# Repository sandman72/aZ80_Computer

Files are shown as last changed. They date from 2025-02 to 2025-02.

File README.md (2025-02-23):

# aZ80_Computer

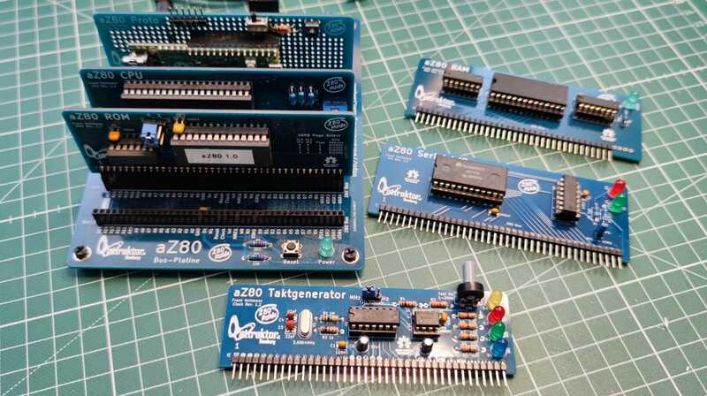
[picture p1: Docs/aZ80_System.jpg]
Das aZ80 System


#### Was ist der aZ80 Retro Computer?

Die Idee war: Wir bauen einen kleinen bezahlbaren Retro Computer für Workshops im Attraktor e.V.

 - Mit Steckkarten, damit man ihn erweitern kann. 
 - Beim Aufbau jeder Karte gibt es einen Einblick, was diese im Detail macht und wie sie funktioniert
 - Eine Einführung zur Computertechnik der 70er Jahre und die Gedankengänge und Evolutionen, die es zu der Zeit gab.
 - Wir programmieren auf dem aZ80 mit MS-BASIC und Assembler, z.B. kleine Spiele und Programme.

Unter Docs findet sich eine erste Präsentation über das Projekt. Eine ausführliche Anleitung folgt nach den ersten Workshops.

#### Hardware

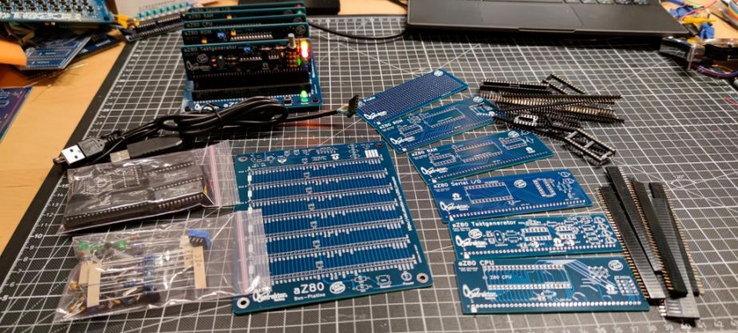
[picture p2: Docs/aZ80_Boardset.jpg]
Die aZ80 Boards


Die Entscheidung was für ein System ich "neu" entwickeln wollte, fiel auf einen Bauvorschlag von <a href="http://searle.wales/">Grant Searle</a>, 
der auch bei einigen anderen Retro-Computern (z.B. RC2014) zum Einsatz kam. Damit gibt es eine gewisse 
Kompatibilität zum RC2014 System und den Steckkarten, aber der aZ80 sollte als Open-Hardware und -Software verfügbar 
sein und nicht hinter einer Paywall liegen, teure Kits oder Zusatz Hardware benötigen, z.B. wie der RC2014.

#### Software

Für den aZ80 wurden eine alte Version von MS Basic (Nascom Basic 4.7) und der Efex Monitor (Efex V4 1.0) mit einem eigenen BIOS kombiniert.
Das BIOS checkt, ob die wichtigsten Karten des Systems funktionieren und initialisiert diese. Danach erscheint über die serielle Schnittstelle
die Auswahlmöglichkeit zwischen dem Basic und dem Monitor Programm. Diese sind so angepasst, dass sie mit dem 
Online Z80 Compiler <a href="https://www.asm80.com/">ASM80</a> bearbeitet werden können.

Nascom Basic Verweis: <a href="https://gitlab.com/feilipu/NASCOM_BASIC"> https://gitlab.com/feilipu/NASCOM_BASIC </a>

Efex V4 1.0 Verweis: <a href="https://mkpeker.wixsite.com/efex"> https://mkpeker.wixsite.com/efex </a>

#### VDP

Als Highlight hat der aZ80 ein Video Display Prozessor mit an Board, der die Verbindung in die jetzige Zeit herstellt. Mit dieser Karte kann man den aZ80
an einen DVI/HDMI Monitor anschließen und per USB auch Tastatur, Maus, Joystick und/oder Speicher anschließen. Das kombiniert mit einem schicken Gehäuse
mit eingebautem Display gibt dann einen kleinen feinen Standalone Z80 Computer.

Der VDP wird über die serielle Schnittstelle angesprochen und kann Text 40x25 Zeichen oder auch Grafiken (320x240 Pixel mit 256 Farben), Sprites oder 
einen Mouse Cursor anzeigen. Zusätzlich gibt es einen Debug Bildschirm, mit dem man den aktuellen Status sich anzeigen lassen kann (Win+ESC Taste).

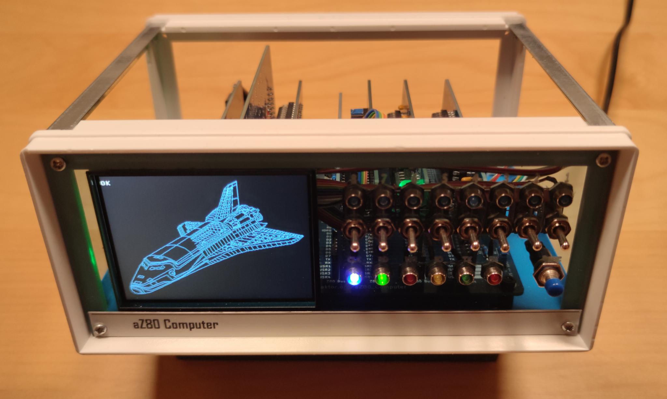
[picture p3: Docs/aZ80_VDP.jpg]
Die aZ80 VDP


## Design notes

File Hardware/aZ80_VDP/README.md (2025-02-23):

# aZ80 VDP Platine

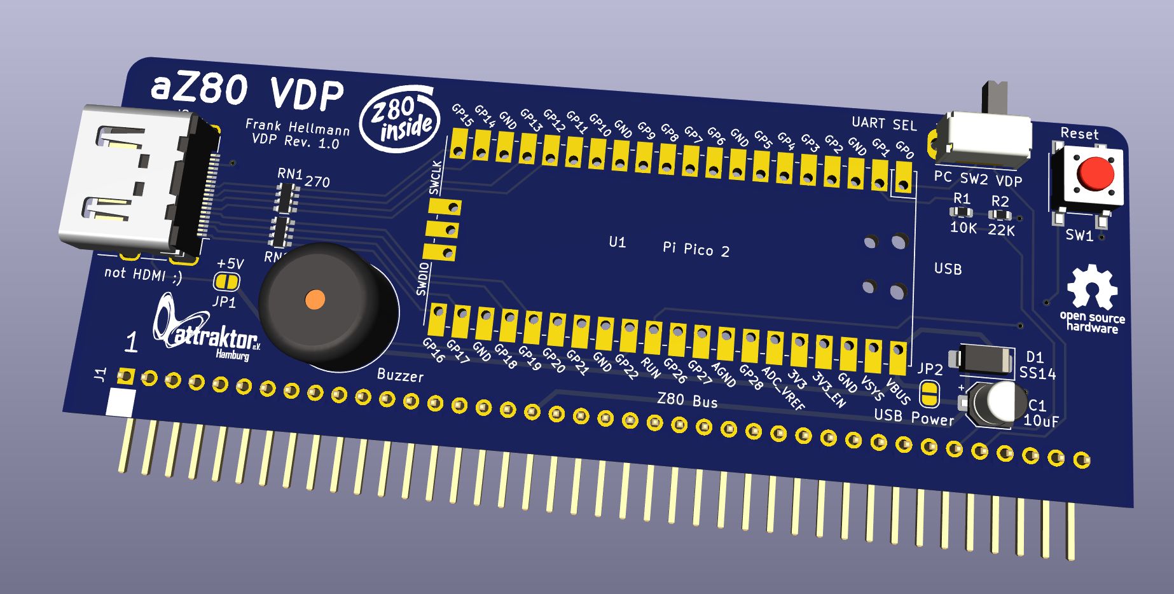
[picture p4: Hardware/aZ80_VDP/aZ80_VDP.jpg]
Die aZ80 VDP Platine


Die Video-Display-Processor VDP Platine ist eine Grafik- und I/O-Karte mit eingebautem VT100+ Terminal Emulator. Über die serielle Schnittstelle kann sie Daten vom aZ80 System
entgegennehmen und anzeigen, kann aber auch über den USB Port Eingaben über eine USB-Tastatur an das aZ80 System weitergeben. 
Auch andere USB-Geräte, wie Maus, Joystick oder Speicherstick können abgefragt werden, wobei die Unterstützung noch work in progress ist.

Der VDP untertützt die normale Anzeige von Text, der über die seriellen Schnittstelle eingeht. Darüber hinaus werden auch ANSI Kontrollzeichen 
unterstützt, welche eine erweiterte Kontrolle der Textattribute, wie Farbe, Blinken, Position usw. erlaubt, und darüber hinaus auch eine Grafikausgaben
und die Kontrolle von Sprites, Maus-Cursor und den Buzzer erlaubt. Weiteres auf der <a href="./ANSI.md">ANSI Seite</a>.

Über die USB-Tastatur kann mit der Tastenkombination WIN+ESC ein Debug-Fenster eingeblendet werden, das den akutellen Zustand des VDP anzeigt.

Der Reset Taster SW1 bietet es an den VDP zurückzusetzen und vereinfacht auch das installieren einer neuen Firmware an einem PC.

Der Umschalter SW2 bietet zwei Betriebsmodi an:
| SW1 | Modus |
|:---:|:---|
| PC  | PC-Betrieb - Die serielle Schnittstelle auf der Bus-Platine hat Vorrang |
| VDP | Standalone-Betrieb - Die USB Schnittstelle am VDP hat Vorrang |

#### Technische Daten

Der VDP bietet eine Grafikauflösung von 320x240 Pixel mit 256 Farben. Die Ausgabe erfolgt hochskaliert als 640x480 Pixel Modus mit 60Hz über eine (not) HDMI Schnittstelle.

 - Arduino Software auf einem Raspberry PI Pico 2 - RP2350
 - 320x240 Pixel Auflösung
 - 40x30 Zeichen Textmodus mit 16 bzw. 256 Farben
 - 256 Farben Palette mit 16bit Farbtiefe, 8 Farben in automatischer Farbrotation
 - 64 32x32 Pixel Sprites mit 256 Farben und Maskenkanal
 - einen Mauscursor
 - einfache Text- und Grafik-Kommandos
 - Double-Buffered Text-, Grafik und Sprite-Aufbau für flickerfreie Anzeige mit 60Hz

#### Update der Firmware

Zur Installation einer neuen Firmware auf den Pico 2 wird dieser mit einem Micro USB Kabel an einen PC angeschloßen.
Dann drückt man erst die Reset Taste SW1, nun den BOOT Taster, hält diesen fest und lässt die Reset Taste SW1 los.
Auf dem PC sollte nun ein weiteres Laufwerk RPI angezeigt werden. Auf dieses kopiert man die aktualisierte UF2 Datei.

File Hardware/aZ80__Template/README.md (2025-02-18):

# aZ80 Platinen Template

Dieses Template kann genutzt werden um mit KiCAD V8.0 oder neuer eigene Platinen im Formfaktor des aZ80 Retro Systems zu designen.

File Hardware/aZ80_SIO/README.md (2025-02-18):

# aZ80 Serielle Platine

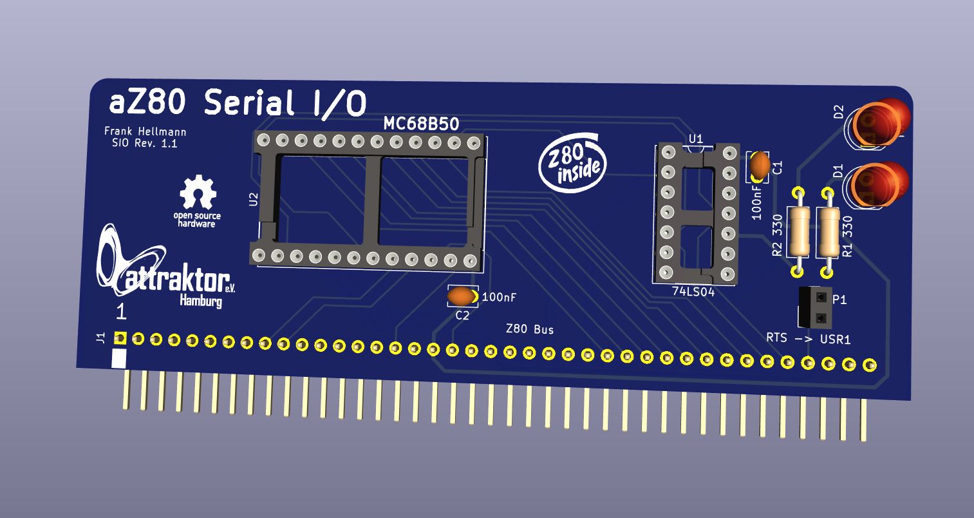
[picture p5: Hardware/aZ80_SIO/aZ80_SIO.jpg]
Die aZ80 Serielle Platine


Die serielle Platine stellt über eine serielle Schnittstelle die Verbindung zur Aussenwelt her. 
Diese Schnittstelle wird über die Busplatine an deren Anschluß J1 zur Verfügung gestellt. 
Dort kann man dann ein seriell zu USB Wandlerkabel anschließen und mit einem Computer als Terminal Ersatz verbinden. 
Hierbei ist auf die Pinbelegung zu achten, da diese nicht wirklich genormt ist.

Über den Jumper JP1 kann ein RTS/CTS-Handshaking aktiviert werden, was wichtig ist, wenn man viele Daten oder lange 
Listings vom Computer übertragen will. Das Handshaking stellt sicher, dass nur dann Daten übertragen werden, wenn 
das aZ80 System diese auch verarbeiten kann und noch Platz im Empfangsbuffer ist.

Die Einstellungen in einem seriellen Terminal Emulator auf einem PC sind dann folgende:

    57600 Baud  8-N-1  RTS/CTS Handshake

#### LEDs

Die LEDs zeigen den Datentransfer über die Sende- (TX) und Empfangs- (RX) Leitung an.

#### Jumper JP1

Der Jumper JP1 erlaubt das Aktivieren des RTS/CTS-Handshaking über die USR1 Leitung zur Busplatine. 
Dort muß auch der Jumper JP1 gesteckt werden um das Signal an den Anschluß J1 weiterzuleiten.

#### Baudrate

Die Baudrate wird direkt aus dem Systemtakt der Clock Platine abgeleitet und beträgt im Normallfall 57600 Baud, wenn ein 3.6864MHz Quartz verwendet wird.

Wenn die Clock Platine auf niedrige Frequenz (4-20Hz) steht, dann funktioniert die Serielle Karte nicht ordnungsgemäß.

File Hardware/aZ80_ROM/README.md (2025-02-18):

# aZ80 ROM Platine

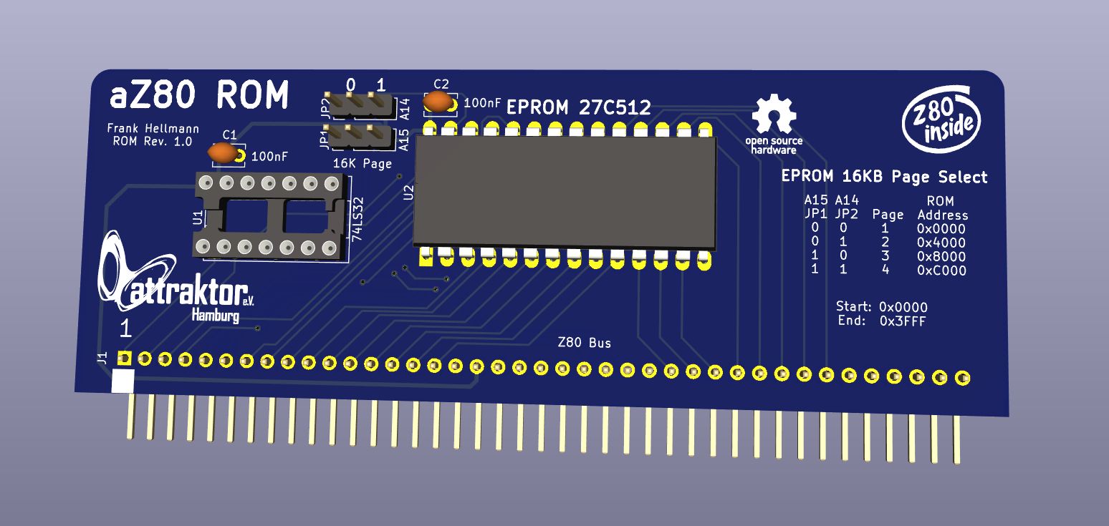
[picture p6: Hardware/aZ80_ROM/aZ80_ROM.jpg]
Die aZ80 ROM Platine


Die ROM Platine stellt dem aZ80 Retro System den nichtflüchtigen Speicher zur Verfügung. 

Der 32KB große Speicherbaustein (EEPROM) ist in 4 8KB große Teile (Bänke/Pages) aufgeteilt.

Das ROM wird im ersten Speicherbereich eingeblendet ($0000 - $3FFF) und enthält auch die Interrupt Vectoren.

#### Bank Auswahl

Über die Jumper JP1 und JP2 kann der 8KB Teil des ROMs eingestellt werden, der dem aZ80 zur Verfügung gestellt werden soll.

| JP2 | JP1 | Bank |
|:---:|:---:|:-----|
| 0 | 0 | 1 - BIOS mit BASIC und MONITOR |
| 0 | 1 | 2 - Diagnostic ROM |
| 1 | 0 | (aktuell Kopie von Bank 1) |
| 1 | 1 | (aktuell Kopie von Bank 2) |

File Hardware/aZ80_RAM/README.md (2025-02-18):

# aZ80 RAM Platine

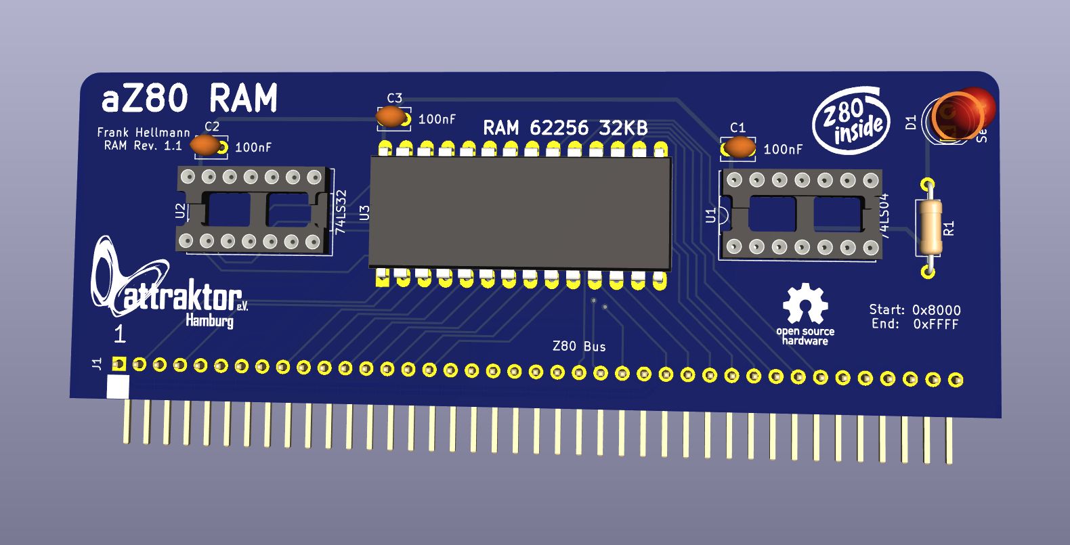
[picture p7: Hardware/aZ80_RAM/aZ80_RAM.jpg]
Die aZ80 RAM Platine


Die RAM Platine stellt den 32KB großen flüchtigen Arbeitsspeicher dem aZ80 Retro System zur Verfügung.

Das RAM wird im oberen Teil des Addressraums eingeblendet ($8000-$FFFF).

Die LED zeigt einen Zugriff auf den Arbeitsspeicher an.

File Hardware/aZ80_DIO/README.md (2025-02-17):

# aZ80 Digital I/O Platine

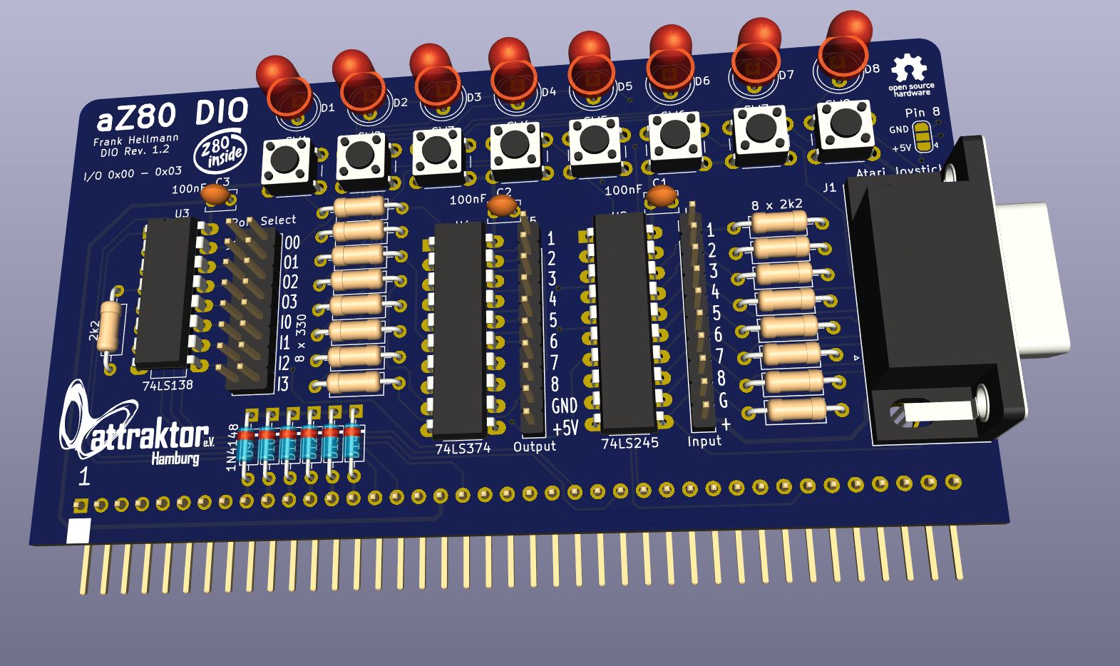
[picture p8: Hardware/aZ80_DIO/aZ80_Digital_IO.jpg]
Die aZ80 Digital I/O Platine


Die DIO (Digital I/O) Platine stellt über Taster, Joystick Anschluss und LEDs eine Verbindung zur Aussenwelt her.

#### Port Auswahl

Über den Jumperblock JP1 kann die Adresse (Port) eingestellt werden, auf den die DIO Platine reagieren soll. 
Normalerweise ist dort O0 und I0 gesteckt, was bedeutet, dass die DIO Platine auf Addresse 0 beim Lesen und Schreiben reagiert.
Damit können auch mehrere Karten in einem aZ80 System genutzt werden, wenn alle Karten unterschiedliche Addressen bekommen.

#### LEDs

Die LEDs können über die eingestellte Addresse mit einem I/O Write eingeschaltet werden. 

```
Basic:   OUT 0, 170             schaltet jede zweite LED an Port 0 an.

ASM:     LD      A,%10101010
         OUT     IOPORT,A       schaltet jede zweite LED an Port 0 an.
```

#### Taster & Joystick

Die Taster und der Joystick können über die eingestellte Addresse mit einem I/O Read ausgelesen werden.

```
Basic:   A$=INP(0)     liest den Status der Taster in A$ ein

ASM:     IN A,(0)      liest den Status der Taster in Register A
```

#### Basic Beispiel um LED mit Button einzuschalten

```
10 OUT 0,INP(0)
20 GOTO 10
```

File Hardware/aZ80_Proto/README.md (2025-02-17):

# aZ80 Prototypen Platine

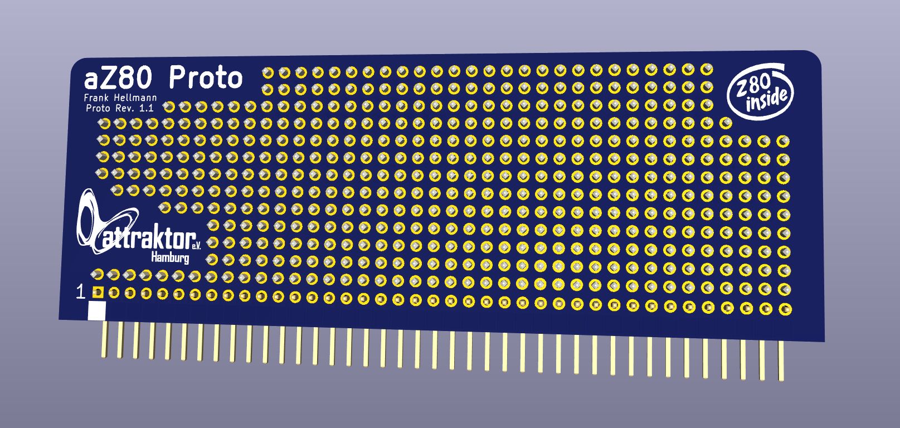
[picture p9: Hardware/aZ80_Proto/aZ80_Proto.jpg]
Die aZ80 Prototypen Platine


Die Proto Platine kann für eigene Experimente oder Schaltungen benutzt werden und ist mit einem Lochraster ausgestattet.

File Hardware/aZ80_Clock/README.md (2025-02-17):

# aZ80 Taktgenerator Platine

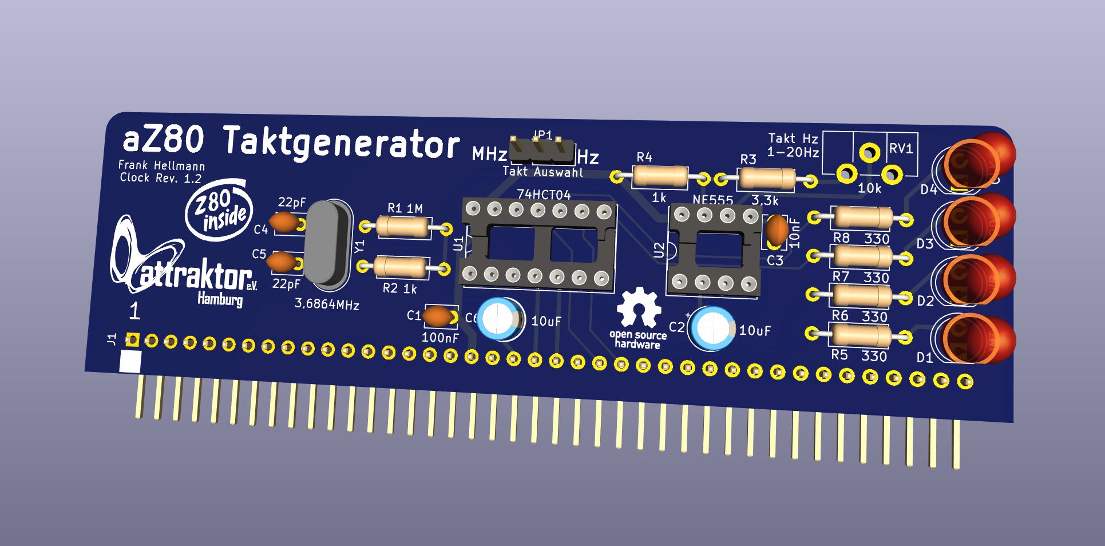
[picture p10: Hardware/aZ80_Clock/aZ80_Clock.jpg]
Die aZ80 Takt Platine


Die Taktgenerator Platine gibt den Takt des aZ80 Retro Computers vor und synchronisiert alle Karten.

Es gibt zwei Modis die mit dem Jumper JP1 umgestellt werden können:

 - 1 - Volle Geschwindigkeit mit 3.6864 MHz
 - 2 - Langsame Geschwindigkeit mit 4-20Hz

Im Normalfall läuft das aZ80 Retro System mit vollem 3.6864Mhz Takt, welcher auch die serielle Baudrate von 57.600 Baud vorgibt.

Bei der langsamen Geschwindigkeit kann man dem System besser "auf den Zahn fühlen", z.B. mit einem Logic Analyser oder der Digital I/O Karte, hat aber keine serielle Verbindung mehr.
Das Poti RV1 erlaubt das Einstellen der Geschwindigkeit im Rahmen von ca. 4 bis 20 Herz.

Die Status LEDs zeigen an, was auf dem aZ80 Bus so los ist:

 - RD - Es wird auf dem Bus etwas gelesen
 - WR - Es wird auf dem Bus etwas geschrieben
 - INT - Es ist ein Interrupt ausgelöst worden
 - CLK - Hier wird der aktuelle Takt als Blinken angezeigt

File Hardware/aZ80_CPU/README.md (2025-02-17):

# aZ80 CPU Platine

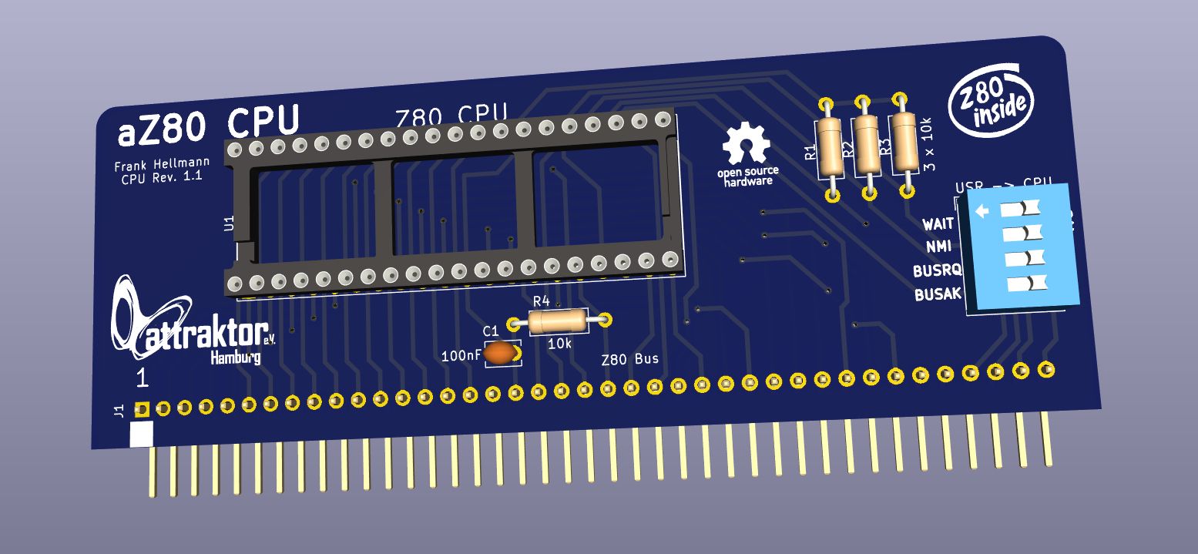
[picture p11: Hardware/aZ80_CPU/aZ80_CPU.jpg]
Die aZ80 CPU Platine


Die CPU Platine ist das Hirn des aZ80 Retro Computers und verarbeitet die Daten.

#### Switch USR -> CPU

Der Switch ist normalerweise in allen Positionen auf Off gestellt und erlaubt in Zukunft weiteren Karten die Steuerung der CPU.

 - 1 - WAIT 
 - 2 - NMI
 - 3 - BUSRQ
 - 4 - BUSAK

Das WAIT Signal hält die CPU an und wird aktuell nur beim Betrieb der SN76489 Soundkarte genutzt. Diese ist so langsam, dass sie die CPU anhalten muss, bis der nächste Befehl gesendet werden darf.

Das NMI (Non-Maskable-Interrupt) Signal ist aktuell ungenutzt.

Das BUSRQ (Bus-Request) Signal ist aktuell ungenutzt.

Das BUSAK (Bus-Acknowledge) Signal ist aktuell ungenutzt.

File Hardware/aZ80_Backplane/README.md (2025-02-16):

# aZ80 Bus-Platine

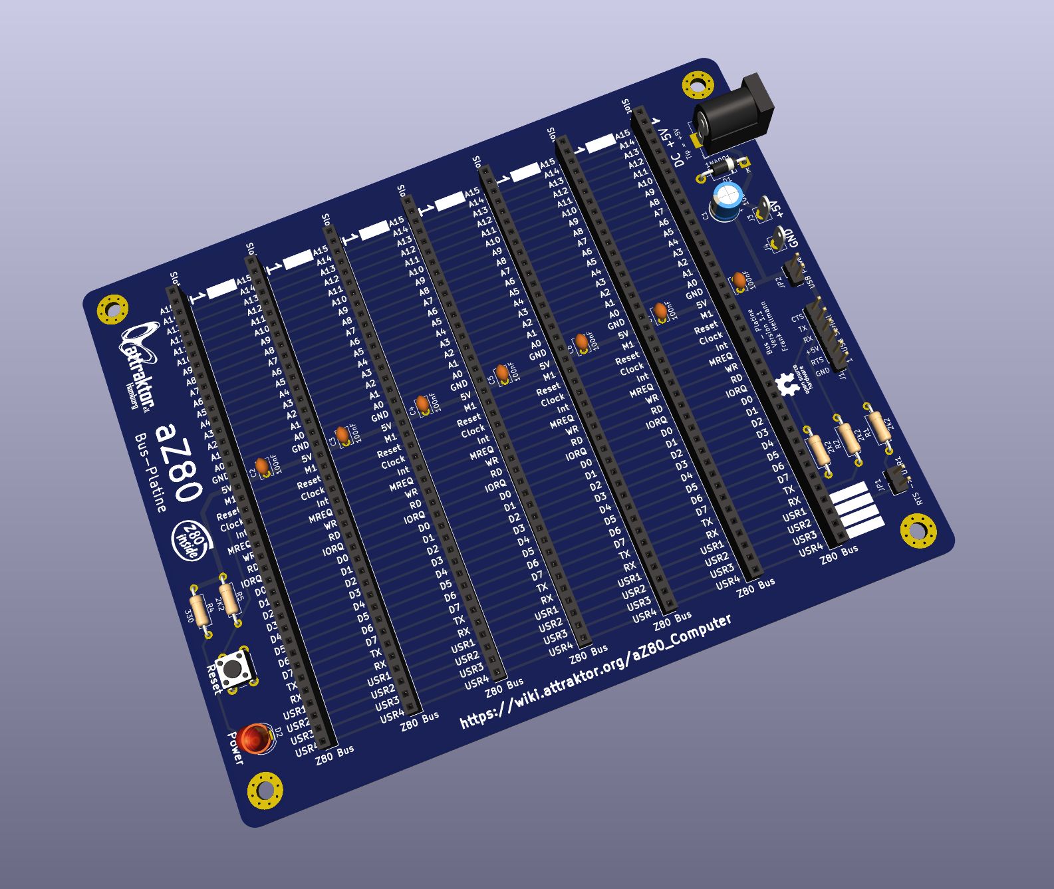
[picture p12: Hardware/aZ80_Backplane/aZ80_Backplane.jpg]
Die aZ80 Bus-Platine


Die Bus-Platine bildet das Rückgrat unseres Computers. Sie verbindet die einzelnen Karten des aZ80 miteinander.

Die sieben Slots sind alle gleich belegt und leiten den Adress- und Datenbus sowie die Kontrollsignale und die Versorgungsspannung weiter an die verschiedenen Karten.

Die LED D2 zeigt an, dass eine Versorgungsspannung anliegt.

Der Taster SW1 erlaubt das Zurücksetzen und Neustarten des Computers, der sogenannte RESET. Dies ist hilfreich, wenn der aZ80 mal nicht mehr reagieren sollte.

Im Kurs zeigen wir euch, wie man diese Platinen am besten zusammen lötet.

#### Externe Anschlüsse:

 - J1 - Steckleiste für Serielles Interfaces (FTDI Belegung)
 - J2 - Buchse für die externe 5V Versorgungsspannung (Barrel-Jack, Mitte +5V)
 - J3 - +5V Messpunkt für die Versorgungsspannung.
 - J4 - Masse Messpunkt für die Versorgungsspannung.

#### Steckbrücken (Jumper):

 - JP1 - Steuerleitung RTS des FTDI USB Seriell Wandlers mit Leitung USR1 verbinden
 - JP2 - Stromversorgung per FTDI USB Seriell Wandler erlauben

Unser aZ80 Computer benötigt eine +5V Versorgungsspannung von etwa 300mA, was einen Betrieb über den FTDI USB Seriell Wandler erlaubt, wenn nicht noch weitere Zusatzkarten (Video, Audio usw.) eingesteckt sind. In diesem Falle sollte man über die Buchse J2 ein USB-Netzteil anschließen.

Der BUS ist größtenteils kompatibel mit dem sogenannten RC40 System (Retro Computer 40), dass auch im RC2014 Computer benutzt wird. Hierzu gibt es diverse Erweiterungsplatinen, die auch zum großen Teil mit dem aZ80 kompatibel sind.

#### Pin-Belegung der aZ80 Busses:

| Pin |  Signal  |
|---:|:---|
|  1 - 16 | A15-A0 	Adress-Bus | 
| 17 | GND		Masse |
| 18 | VCC +5V	Versorgungsspannung |
| 19 | M1		Steuerungssignal |
| 20 | RESET		Zurücksetzen des Systems |
| 21 | CLOCK		Taktsignal 3,68MHz |
| 22 | INT		Interrupt, Unterbrechungsanforderung |
| 23 | MREQ		Memory Request, Speicheranfrage |
| 24 | WR		Write, Daten schreiben |
| 25 | RD		Read, Daten lesen |
| 26 | IORQ		I/O Request, I/O-Anfrage |
| 27 - 34 | D0-D7		Daten-Bus |
| 35 | TX		Serielle Daten Senden |
| 36 | RX		Serielle Daten Empfangen |
| 37 - 40 | USR1-USR4	Benutzerdefinierte Signale |  

Der Adress- und Daten-Bus ermöglicht dem Prozessor/CPU mit den einzelnen Karten Daten auszutauschen. Dabei enthält der Adress-Bus, wenn man so will, die Adresse eines Postfachs in das man was reinlegen oder rausholen möchte. Der Daten-Bus enthält die Information die dort gelesen wurde oder abgelegt werden soll.

Mit den Steuersignale (RD, WR, MREQ, IORQ, M1) legt der Prozessor fest, wie und von wo etwas gelesen oder geschrieben werden soll.   

#### Benutzerdefinierte Signale USR1-USR4:

Die vier USR1-USR4 Pins kann man selber nach Bedarf belegen. Die Serielle Karte kann z.B. über die Steuerleitung USR1 mit dem FTDI Seriell Wandler verbunden werden, was eine Flusssteuerung der Daten erlaubt. Dies ist nötig, wenn unser aZ80 lange BASIC Programme empfangen und nichts verloren gehen soll.

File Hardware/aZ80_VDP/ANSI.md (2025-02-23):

### We support the following ESC Sequences

To use them the Escape Sequence (ESC = 27) needs to be send. For example:

PRINT CHR$(27);"[7m REVERSE"
    
PRINT CHR$(27);"[31m RED"
  
#### Single Chars:
| ESC  | Action |
|:-----|:-----|
| ESC[7 | Save the cursor position |
| ESC[8 | Move cursor to previously saved position |
| ESC[c | Reset Terminal |
| ESC[s | Save the cursor position |
| ESC[u | Move cursor to previously saved position |
| ESC[A | Move the cursor up |
| ESC[B | Move the cursor down |
| ESC[C | Move the cursor forward |
| ESC[D | Move the cursor backward |
| ESC[H | Move to 0-0 |
| ESC[J | Clear screen from cursor |
| ESC[K | Clear line from cursor |

#### Multiple chars:
| ESC  | Action |
|:-----|:-----|
| ESC[?12l | Cursor not blinking |
| ESC[?12h | Cursor blinking |
| ESC[?25l | Cursor invisible |
| ESC[?25h | Cursor visible |
| ESC[0m | Text Normal |
| ESC[5m | Text Blink on |
| ESC[7m | Text Reverse on |
| ESC[30m | Set foreground color to palette entry 0 (usually black) |
|  to | |
| ESC[37m | Set foreground color to palette entry 7 (usually white) |
| ESC[38;5;-n-m | Set foreground color to palette entry -n- (0-255) |
| ESC[40m | Set background color to palette entry 0 (usually black) |
|  to
| ESC[47m | Set background color to palette entry 7 (usually white) |
| ESC[48;5;-n-m | Set background color to palette entry -n- (0-255) |
| ESC[49;5;-n-m | Set screen background color to palette entry -n- (usually black) |
| ESC[50;c;r;g;bm | Set palette entry -c- to RGB color -r-,-g-,-b- (0-255) |
| ESC[5n | Return terminal status "OK" |
| ESC[6n | Return cursor position -> returns ESC[-n-;-m-R -n- = y -m- = x (reversed) |
| ESC[9n | Return mouse pos/buttons  -> returns ESC[-n-;-m-;-b-R -n- = x -m- = y  -b- = buttons |
| ESC[-n-A | Move the cursor up -n- lines |
| ESC[-n-B | Move the cursor down -n- lines |
| ESC[-n-C | Move the cursor forward -n- characters |
| ESC[-n-D | Move the cursor backward -n- characters |
| ESC[-Row-;-Col-H | Move to -Row-,-Col- |
| ESC[0J | clear screen from cursor |
| ESC[1J | clear screen to cursor |
| ESC[2J | Clear the screen and move the cursor to 0-0 |
| ESC[3J | same as ESC[2J |
| ESC[0K | Clear from cursor to the end of the line |
| ESC[1K | Clear from the beginning of the current line to the cursor |
| ESC[2K | Clear the whole line |
| ESC[nS | scroll whole page up by n rows (default 1 if n missing) |

#### Sprites
| ESC  | Action |
|:-----|:-----|
| ESC[80;n;em | Set sprite state -e- enable=1 disable=0 |
| ESC[81;n;x;ym | Move sprite -n- to position -x- -y- |
| ESC[82;n;x;ym | Set sprite velocity to -x- -y- |

#### Graphics
| ESC  | Action |
|:-----|:-----|
| ESC[1;0;0;g | Move GFX cursor to position x=0 y=0 |
| ESC[5;10;20;42;g | Draw Pixel at position x=10 y=20 with color 42 |
| ESC[10;80;90;17;g | Draw Rectangle at cursor with width 80, height 90 with color 17 |
| ESC[11;80;90;17;g | Draw filled Rectangle at cursor with width 80, height 90 with color 17 |
| ESC[20;40;64;g | Draw Circle at cursor with radius 40 with color 64 |
| ESC[21;40;64;g | Draw filled Circle at cursor with radius 40 with color 64 |
| ESC[99g | Clear command list and set cursor to x=0 y=0 |

#### Cursor Modes
| ESC  | Action |
|:-----|:-----|
| ESC[0 q | Cursor Off |
| ESC[1 q | Blinking Block |
| ESC[2 q | Steady Block |
| ESC[3 q | Blinking Underline |
| ESC[4 q | Steady Underline |
| ESC[5 q | Blinking Bar |
| ESC[6 q | Steady Bar |

#### Mouse Modes
| ESC  | Action |
|:-----|:-----|
| ESC[?1020h | Return Mouse Position -> returns ESC[-n-;-m-;-b-R -n- = x  -m- = y  -b- = buttons |
| ESC[?1030h | Mouse Off |
| ESC[?1031h | Mouse moves text cursor (TODO) |
| ESC[?1032h | Mouse shows as single point |
| ESC[?1033h | Mouse shows as cross hair |
| ESC[?1034h | Mouse shows as user defined sprite (TODO) |
| ESC[?1030l | Mouse Off |

#### OS Commands (TODO)
commands are send in form of ESC]command; with a closing ;
| ESC  | Action |
|:-----|:-----|
| ESC]dir; | Return directory listing of USB Stick |
| ESC]load -n-; | Loads/Prints out file -n- to terminal |
| ESC]save -n-; | Saves terminal output to file -n- |
| ESC]del -n-; | Deletes file -n- |

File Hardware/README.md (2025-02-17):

# aZ80 Hardware

Das aZ80 System

#### Wie funktioniert der aZ80 Retro Computer?

Wenn man sich die Teile dieses Computers, wie Bus-Platine, Taktgenerator, CPU, RAM, ROM, Serielle Schnittstelle usw., als Teile eines menschlichen Körpers vorstellt, dann wäre z.B. die Bus-Platine das Rückgrat, welche die anderen Komponenten verbindet. An der Busplatine hängt dann die Taktplatine, die den Herzschlag an allen Platinen liefert und diese damit synchronisiert. Die CPU als Hirn hängt genauso am Bus und verarbeitet alle Sinneseindrücke und gibt die Befehle. Die ROM und RAM Platinen hängen dort auch wie unser Gedächtnis mit am Bus. Und die Serielle Schnittstelle arbeitet wie unser Mund und Ohren und nimmt die Verständigung mit der Umwelt auf.

Alle Teile werden benötigt um ein funktionierenden Computer zu bekommen und wenn ein Teil nicht richtig funktioniert, kann sich das aZ80 System im übertragenen Sinne z.B. nichts merken, oder auch nicht richtig sprechen.

#### Aus welchen Komponenten besteht das aZ80 System?

Über die zentrale Verbindungsplatine (aZ80 Bus) werden die Prozessorplatine (aZ80 CPU),
der Festwertspeicher (aZ80 ROM), der Zugriffspeicher (aZ80 RAM), die Taktplatine (aZ80 Clock),
der serielle Controller (aZ80 Serial), die Ein- und Ausgabeplatine (aZ80 DIO) und weitere Platinen,
miteinander verbunden. Der 40 Pin breite Bus des aZ80 enthält die wichtigsten Signale um diese 
Komponenten miteinander zu verbinden. Weitere Infos und Produktionsdaten findet man im jeweiligen
Unterordner.

## Hier weitere Infos zur Hardware:

### Pin-Belegung der aZ80 Busses:

| Pin |  Signal  |
|---:|:---|
|  1 - 16 | A15-A0 	Adress-Bus | 
| 17 | GND		Masse |
| 18 | VCC +5V	Versorgungsspannung |
| 19 | M1		Steuerungssignal |
| 20 | RESET		Zurücksetzen des Systems |
| 21 | CLOCK		Taktsignal 3,68MHz |
| 22 | INT		Interrupt, Unterbrechungsanforderung |
| 23 | MREQ		Memory Request, Speicheranfrage |
| 24 | WR		Write, Daten schreiben |
| 25 | RD		Read, Daten lesen |
| 26 | IORQ		I/O Request, I/O-Anfrage |
| 27 - 34 | D0-D7		Daten-Bus |
| 35 | TX		Serielle Daten Senden |
| 36 | RX		Serielle Daten Empfangen |
| 37 - 40 | USR1-USR4	Benutzerdefinierte Signale |  

### Speicher und I/O Adressen

#### ROM:  $0000 - $3FFF
|  Addresse  | Verwendung |
| ---:|:---|
| $0000 | RST Vectors und System Funktionen |
| $0070 | BIOS |
| $0200 | BASIC |
| $2000 | MONITOR |
| | |
| $4000 - $7FFF	| Expansion ROM or VideoRAM 16K (preliminary) |

#### RAM:  $8000 - $FFFF
|  Addresse  | Verwendung |
| ---:|:---|
| $8000 - $80FF | System Variables (Zero Page) |
| $8000 | Serial Buffer  size $3F |
| $8040 | Serial In Pointer  size 2 |
| $8042 | Serial Rd Pointer  size 2 |
| $8044 | Serial Buffer Used	size 2 |
| $8046 | Basic Started?  size 1 |
| Init: | | 
| $80ED | Temp Stack |			
| Basic: | |
| $8047 | Workspace Start (see Basic) |
| $81A3 | Basic Memory Start |
| Monitor: | |
| $8047 | Workspace Start (see Monitor) |
| | |
| $8100 - $FFFF	| Stack + User Memory |

#### I/O Map
|  I/O Addresse  | Verwendung |
| ---:|:---|
| $00-$0F	| Digital I/O 00000000 - 0000xx11  (preliminary) |
| $10-$1F	| IDE/CF  I/O 0001xx00 - 0001xx11  (preliminary) |
| $80-$81	| Serial  I/O 10xxxxx0 - 10xxxxx1  (addr decoder verbrät viele Addressen) |
| $C0-$CF	| Video I/O 1100xx00 - 1100xx11  (preliminary) |
| $D0-$DF	| Audio I/O 1101xx00 - 1101xx11  (preliminary) |

#### RST Vectors
|  Reset Vector | Verwendung |
| ---:|:---|
| RST00		| $0000	Reset Vector |
| RST08		| $0008	TX Char - Sende Zeichen über seriellen Port |
| RST10		| $0010	RX Char - Empfange Zeichen über seriellen Port | 
| RST18		| $0018	Check Char - Überprüfe ob Zeichen eingegangen sind |
| RST20		| $0020	- |
| RST28		| $0028	- |
| RST30		| $0030	- |
| RST38		| $0038	INT Vector - |

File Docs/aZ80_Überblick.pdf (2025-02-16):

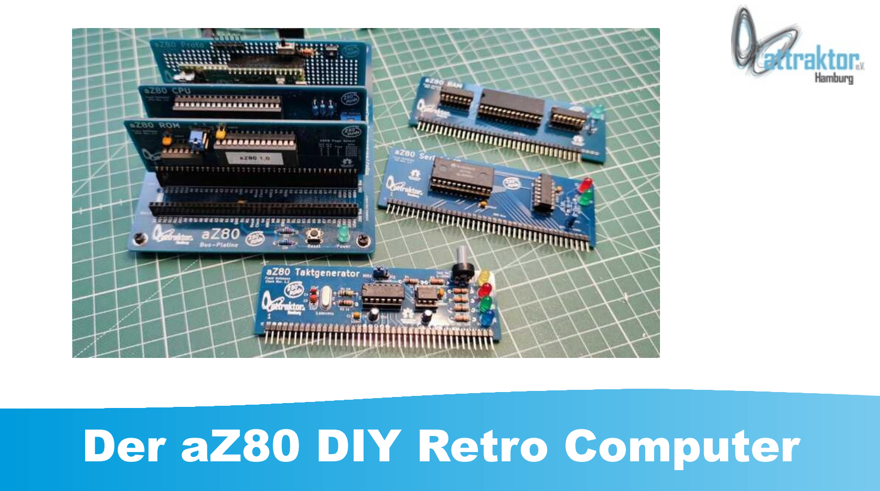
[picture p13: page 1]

# Der aZ80 DIY Retro Computer

31.07.2023 | Frank Hellmann - Attraktor e.V. | 2

## aZ80 – Überblick

- Die Idee: Wir bauen einen kleinen bezahlbaren Retro Computer
- Mit Steckkarten, damit man ihn erweitern kann
- Beim Aufbau jeder Karte gibt es einen Einblick, was diese im Detail macht und wie sie funktioniert
- Eine Einführung zur Computertechnik der 70er Jahre und die Gedankengänge und Evolutionen, die es zu der Zeit gab.
- Wir programmieren auf dem aZ80 mit MS-BASIC und Assembler, z.B. kleine Spiele und Programme.

## aZ80 – Computertechnik Anfang der 70er

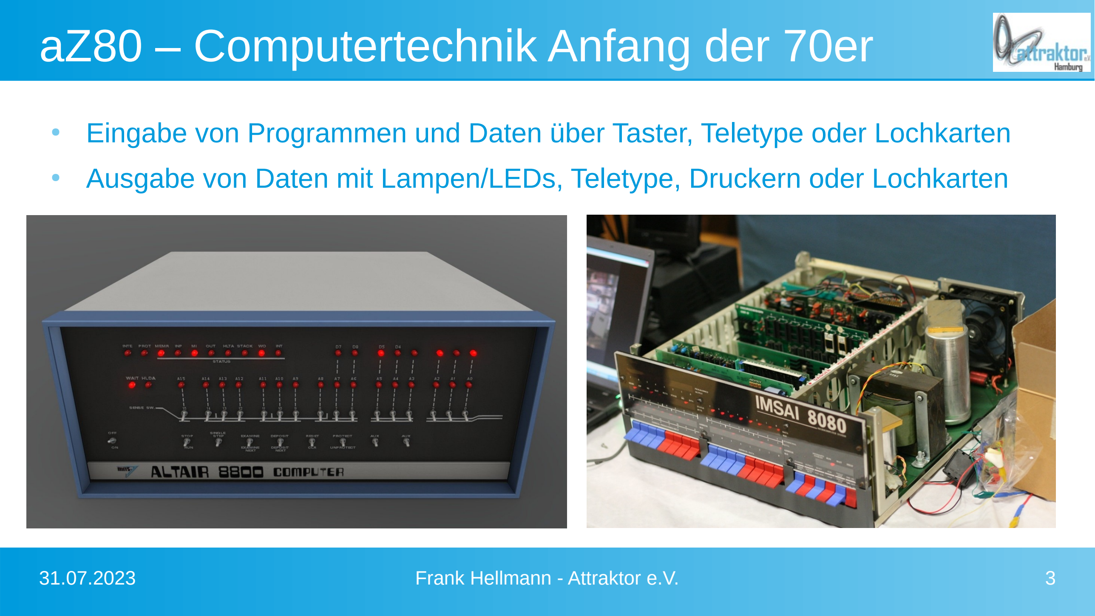
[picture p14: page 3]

- Eingabe von Programmen und Daten über Taster, Teletype oder Lochkarten
- Ausgabe von Daten mit Lampen/LEDs, Teletype, Druckern oder Lochkarten

## aZ80 – Computertechnik Anfang der 70er

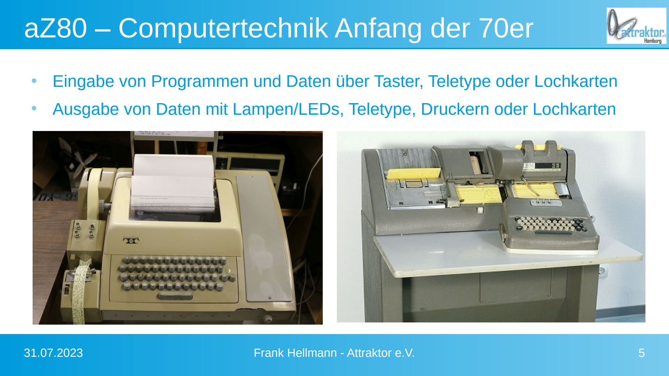
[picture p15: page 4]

- Eingabe von Programmen und Daten über Taster, Teletype oder Lochkarten
- Ausgabe von Daten mit Lampen/LEDs, Teletype, Druckern oder Lochkarten

## aZ80 – Computertechnik Anfang der 70er

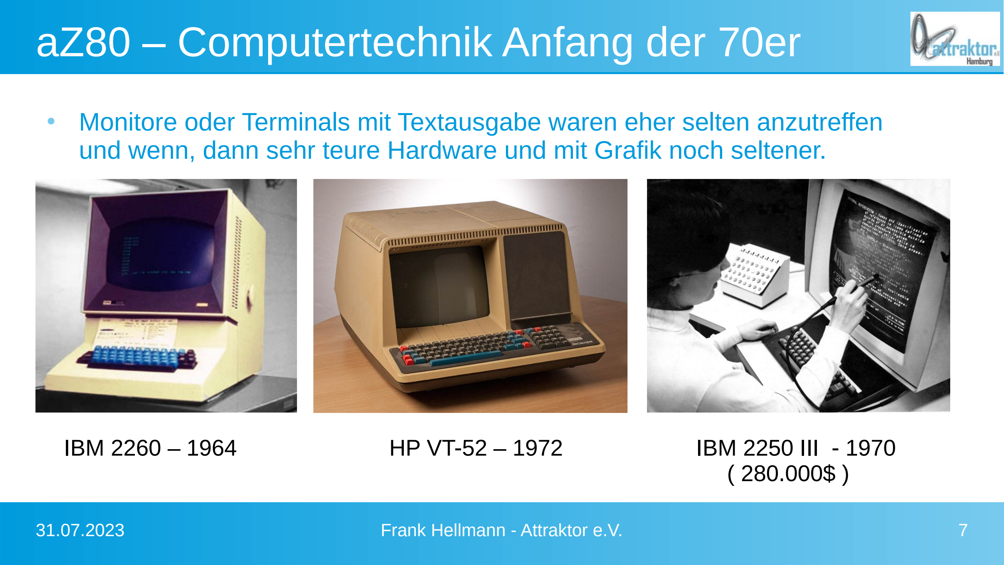
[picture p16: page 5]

- Monitore oder Terminals mit Textausgabe waren eher selten anzutreffen und wenn, dann sehr teure Hardware und mit Grafik noch seltener.
IBM 2260 – 1964 | HP VT-52 – 1972 | IBM 2250 III - 1970 ( 280.000$ )

## aZ80 – Computertechnik Anfang der 70er

- Don Lancasters TV-Typewriter war 1973 der erste erschwingliche Bausatz ($275 / $1920 heute) um Text (32*16 Zeichen) auf einem Fernseher über ein Antennenkabel anzuzeigen zu können.
- Der Apple I Computer war der erste Computer mit einem eingebauten „TV-Terminal“ (40*24 Zeichen). 200 Stück wurden davon für $666,66 ($3600 heute) verkauft.

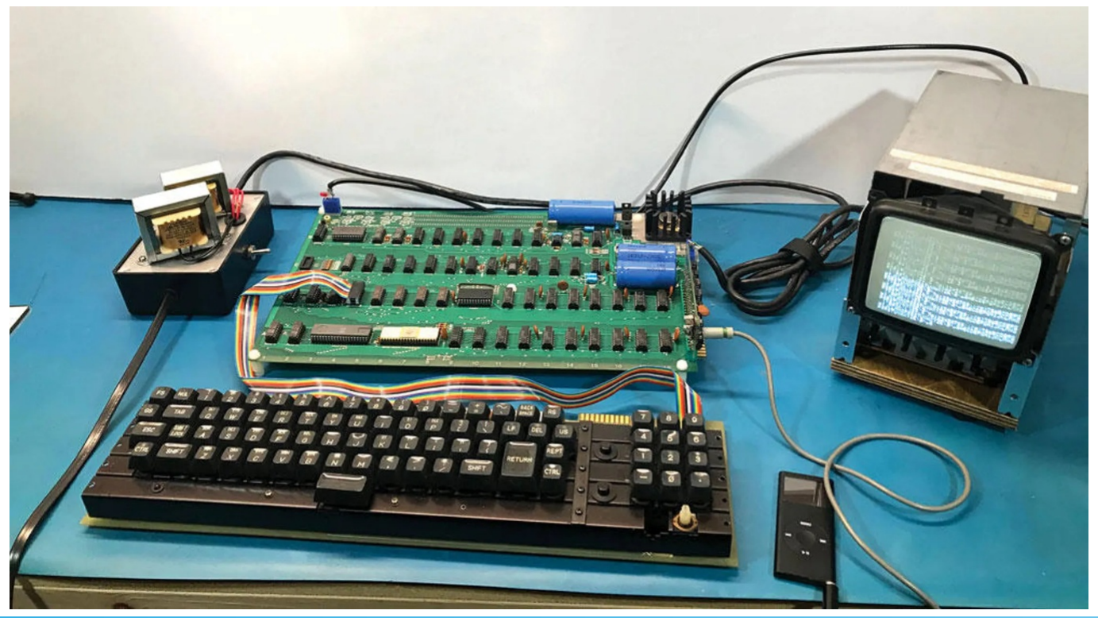
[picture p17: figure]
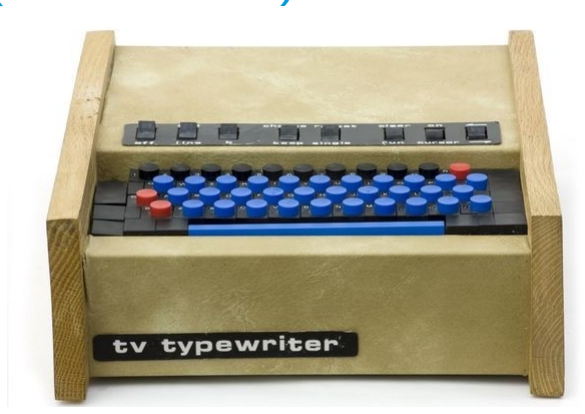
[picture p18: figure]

## aZ80 – Überblick

- Die Entscheidung fiel auf einen Bauvorschlag von Grant Searle, der auch bei einigen anderen Retro-Computern (RC2014) zum Einsatz kam. Damit gibt es eine gewisse Kompatibilität zu diesen Computern.
- Unser aZ80 soll aber als Open-Hardware und -Software verfügbar sein und nicht hinter einer Paywall liegen, teure Kits oder Zusatz-Hardware benötigen, z.B. wie der RC2014.

Grant Searle’s Blog: http://searle.wales/

## aZ80 – Überblick Basis-Kit

Hier der technische Überblick. Wir gehen beim Aufbau der einzelnen Karten auf die Details ein, was das jeweils bedeutet:
- Der Prozessor wird ein Z80 sein
- Der Takt wird bei 3.68MHz liegen
- Der Speicher des aZ80 Basis-Kits hat 32kB RAM und 8kB ROM
- Die Anbindung an die Außenwelt erfolgt über den seriellen Port
- Verbunden werden die Karten über eine Busplatine
- Die Busplatine verbindet den aZ80 per USB auch mit einem PC

## aZ80 – Überblick Basis-Kit

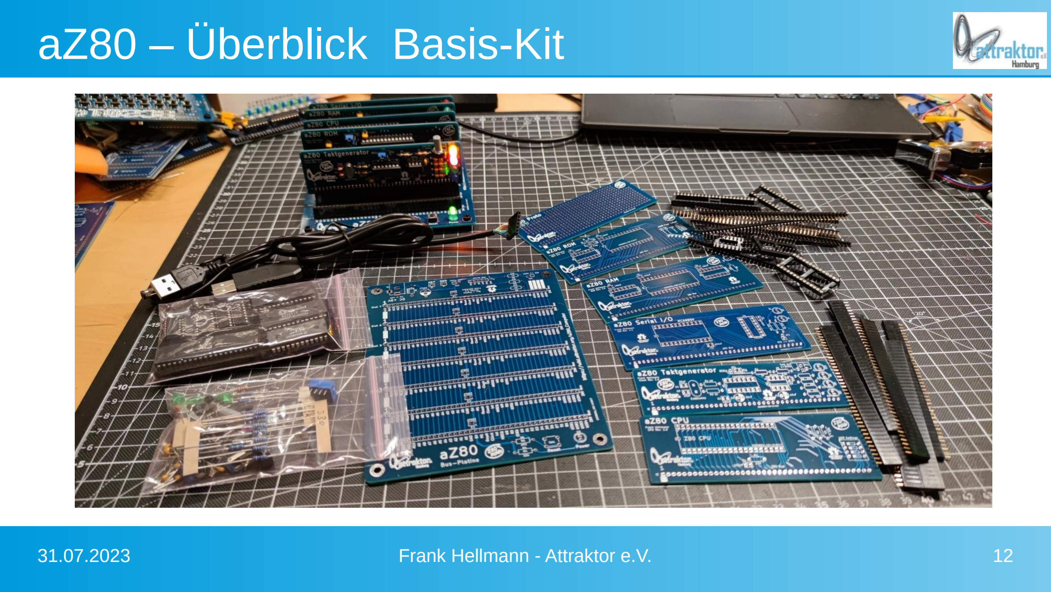
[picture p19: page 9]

## aZ80 – Überblick Basis-Kit

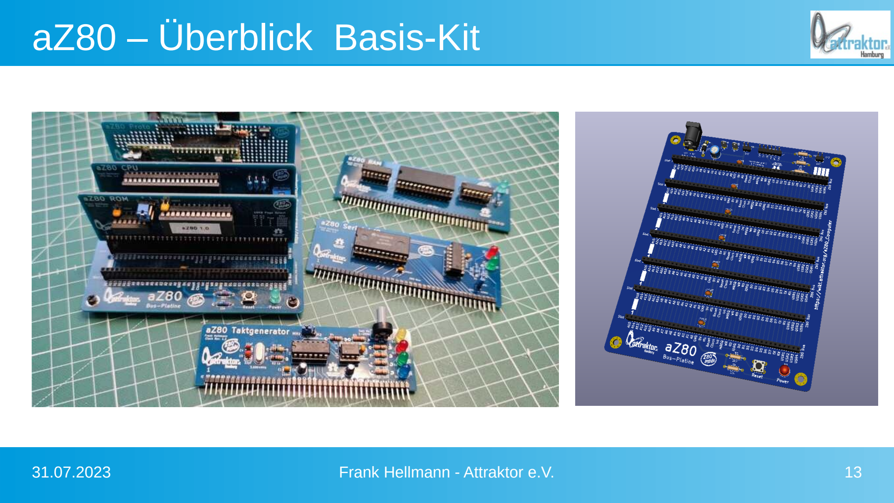
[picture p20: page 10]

## aZ80 – Überblick CPU

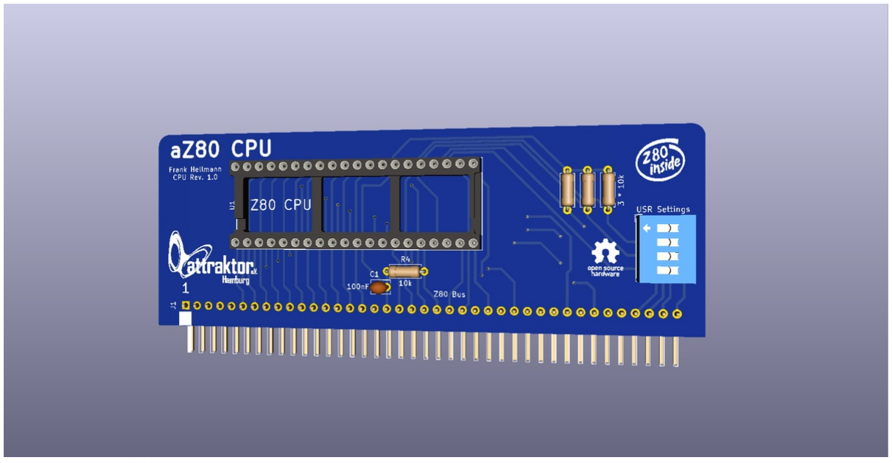
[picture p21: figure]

## aZ80 – Historie des Z80 Prozessors

- Federico Faggin (* 1. Dez. 1941 in Italien)
- Hat bei Fairchild 1968 an den ersten ICs gearbeitet
- Ging 1970 zu Intel, da Fairchild kein Interesse an seiner Arbeit und Forschung hatte.
- Hat bei Intel den ersten Mikroprozessor 4004 fast im Alleingang entwickelt, der zum Boom Intels führte
- War bei Intel nicht glücklich über den Führungsstil,
insbesondere der verweigerten Patente, und verließ Intel

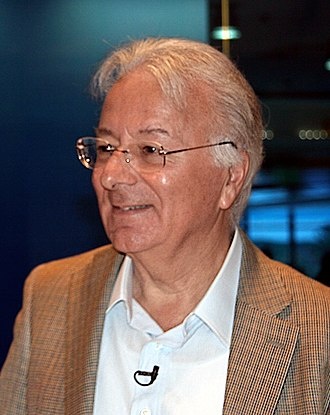
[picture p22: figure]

- Gründete 1974 Zilog um seine Vorstellung von Prozessoren zu verwirklichen
- 1976 kam mit dem Zilog Z80 einer der erfolgreichsten 8bit - Prozessoren der 70er und 80er Jahre auf den Markt.

## aZ80 – Überblick Taktgenerator

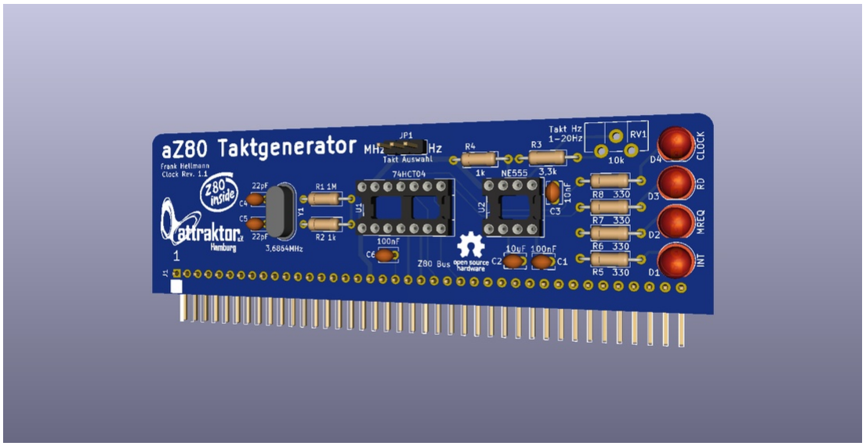
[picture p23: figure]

## aZ80 – Überblick RAM

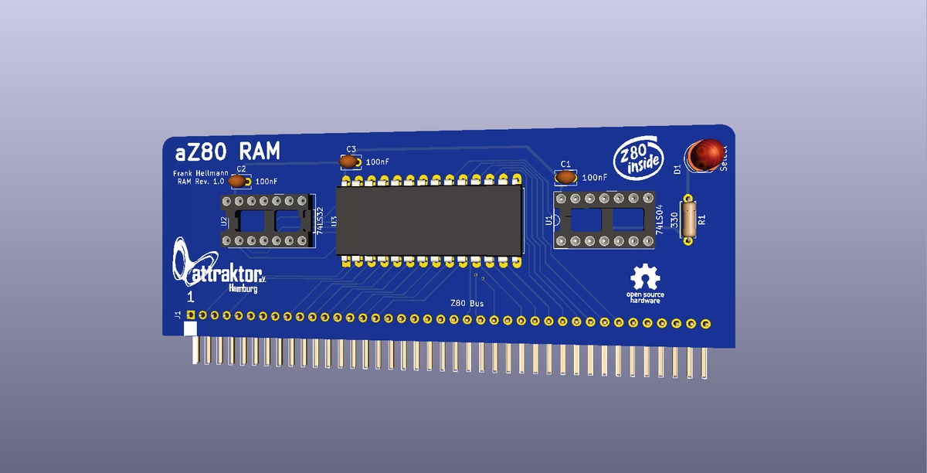
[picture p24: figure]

## aZ80 – Überblick ROM

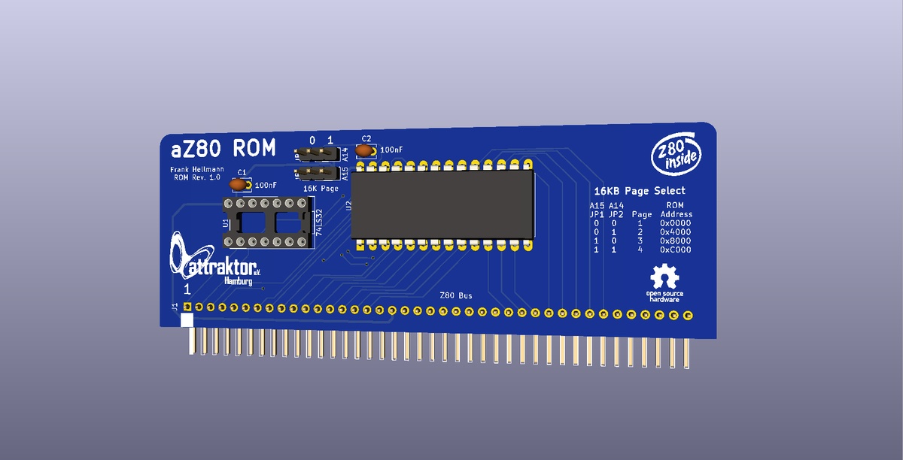
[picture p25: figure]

## aZ80 – Überblick Serieller Port

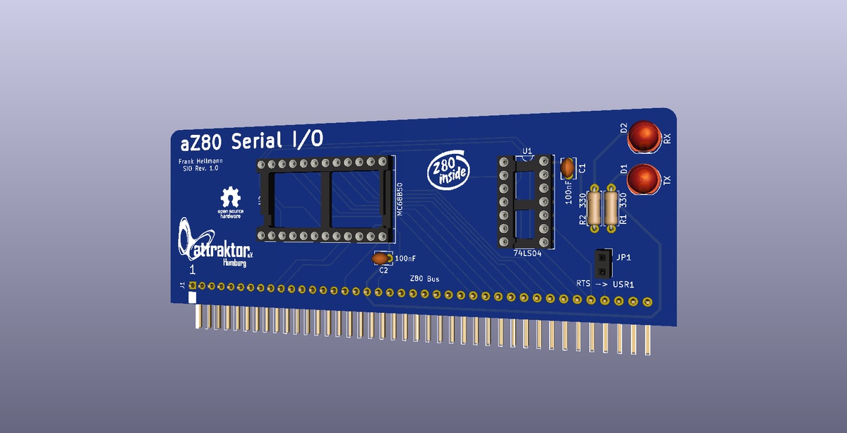
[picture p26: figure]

## aZ80 – Überblick Serieller Port per USB

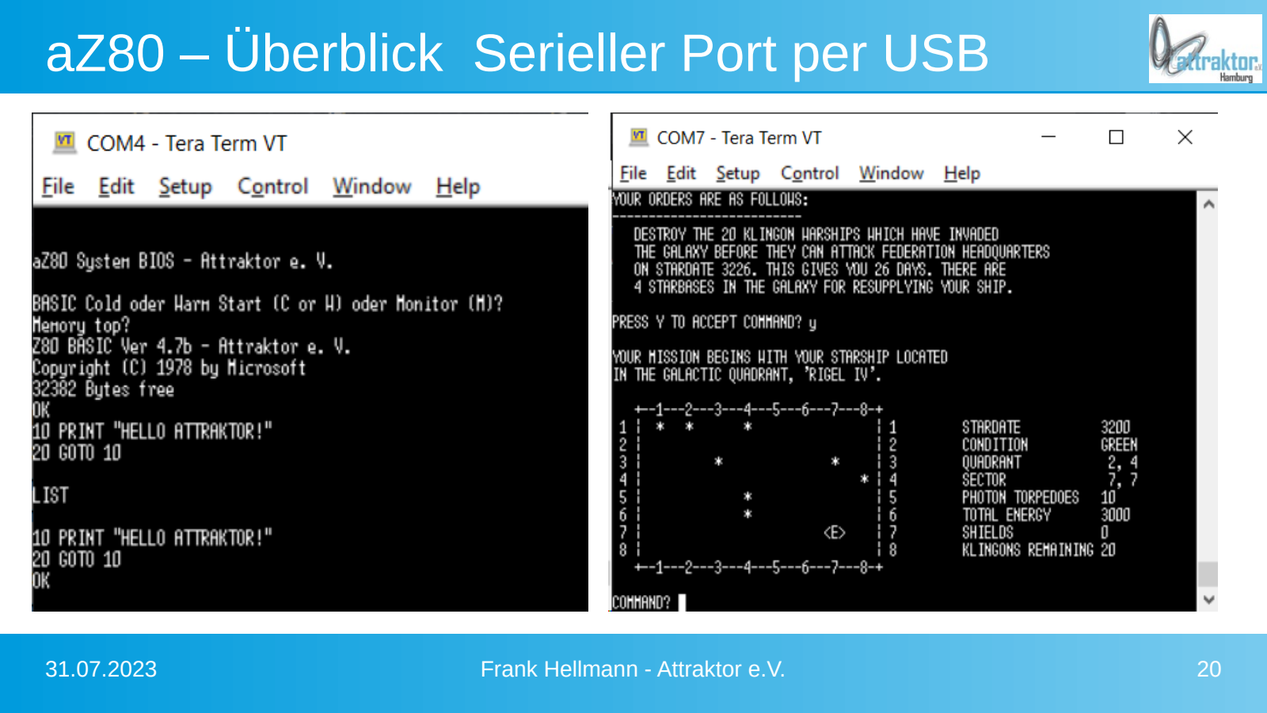
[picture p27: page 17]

## aZ80 – Überblick Basis-Kit

- Ausblick auf die möglichen Erweiterungen:
- I/O Karten mit Tastern und LEDs
- Grafikkarte mit HDMI Ausgang und USB Geräten (320x240, 256Farben, 48 Sprites, 40x30 Zeichen Text)
- Audio Karte mit SN76189 Soundchip
- CP/M kompatible RAM/ROM- und CF-Karte

## aZ80 – Überblick Basis-Kit

Wenn Interesse besteht an diesem Projekt mitzuwirken, sprecht mich gerne an.

https://wiki.attraktor.org/aZ80_Computer

Vielen Dank!

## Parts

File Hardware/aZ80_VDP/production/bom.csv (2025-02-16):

Designator | Footprint | Quantity | Value | LCSC Part #
C1 | CP_Elec_4x5.7 | 1 | 10uF | C3343
D1 | D_SMA | 1 | SS14 | C2480
J2 | HDMI_A_Molex_208658-1001_Horizontal | 1 | not HDMI ;) | C22750565
SW2 | SW_Slide_SPDT_Angled_CK_OS102011MA1Q | 1 | UART SEL | C226259
R1 | 0603 | 1 | 10K | C25804
R2 | 0603 | 1 | 22K | C31850
RN1, RN2 | R_Array_Convex_4x0603 | 2 | 270 | C1966
SW1 | SW_Push_1P1T_NO_6x6mm_H9.5mm | 1 | Reset | C221872

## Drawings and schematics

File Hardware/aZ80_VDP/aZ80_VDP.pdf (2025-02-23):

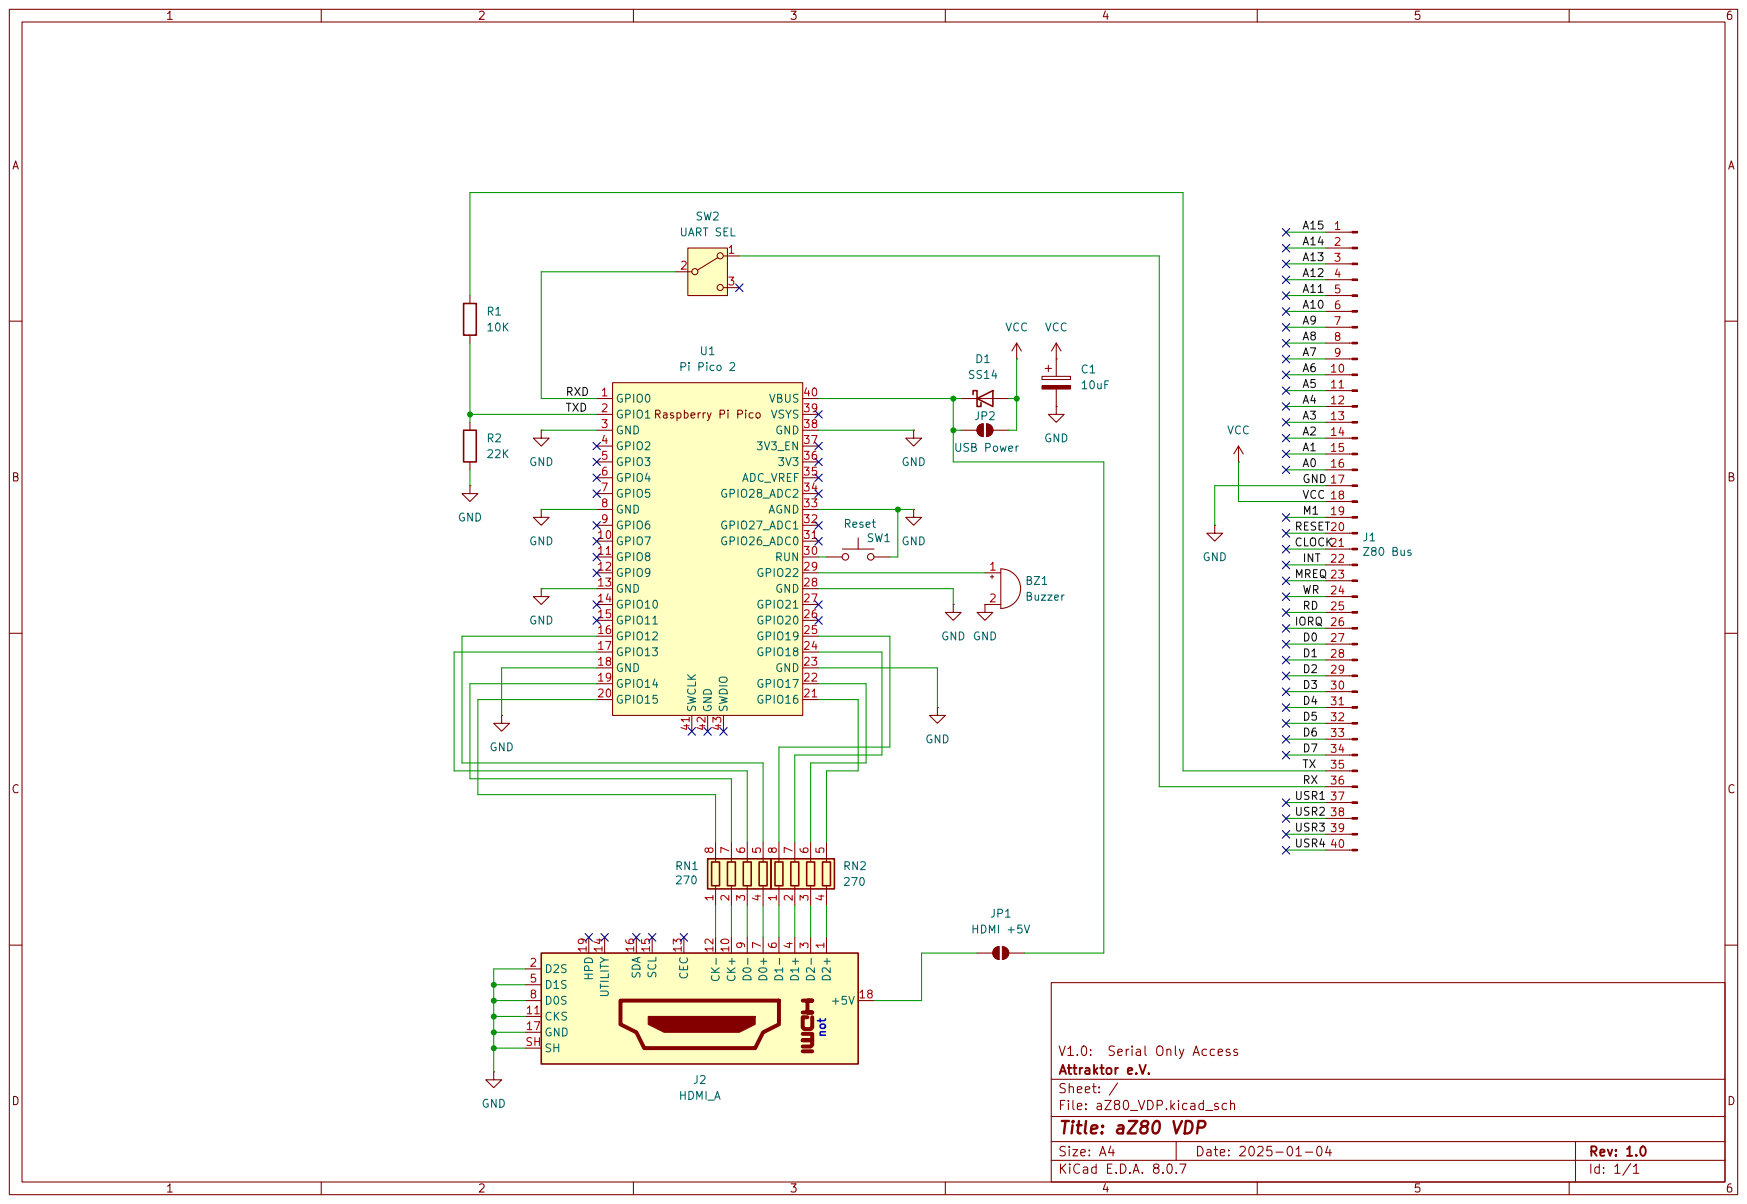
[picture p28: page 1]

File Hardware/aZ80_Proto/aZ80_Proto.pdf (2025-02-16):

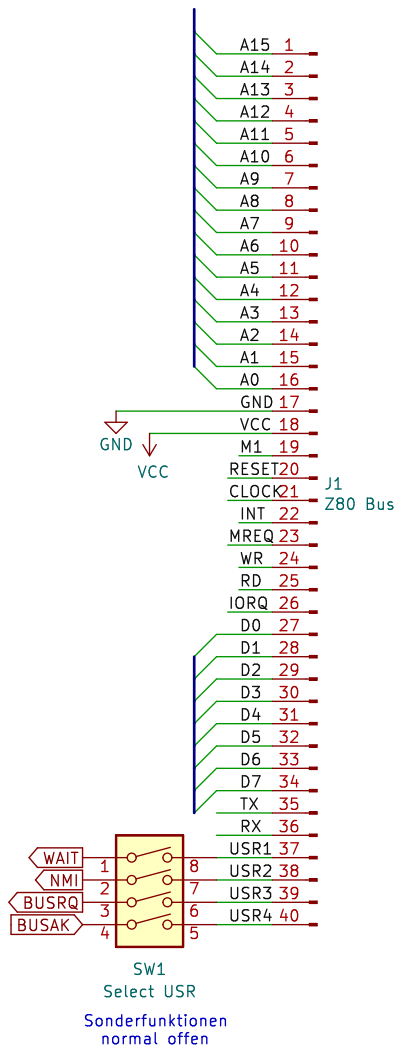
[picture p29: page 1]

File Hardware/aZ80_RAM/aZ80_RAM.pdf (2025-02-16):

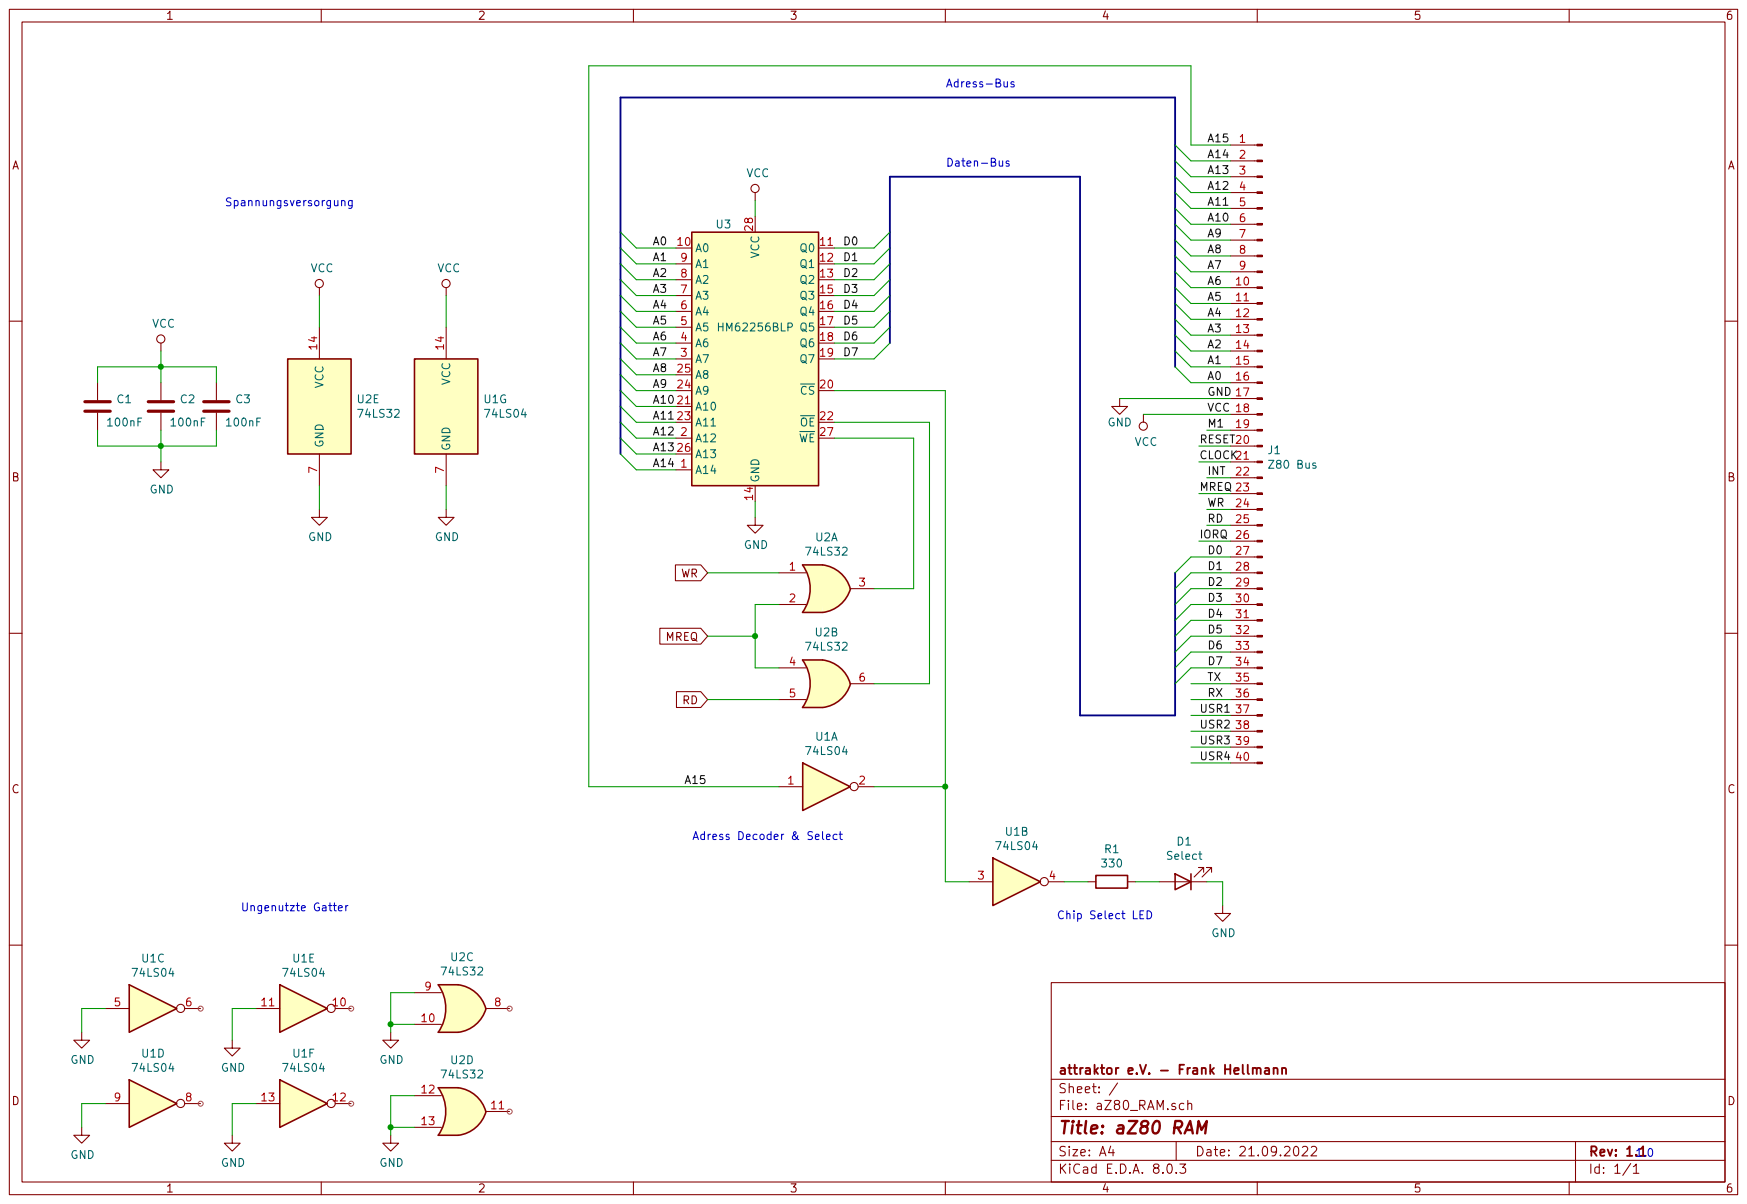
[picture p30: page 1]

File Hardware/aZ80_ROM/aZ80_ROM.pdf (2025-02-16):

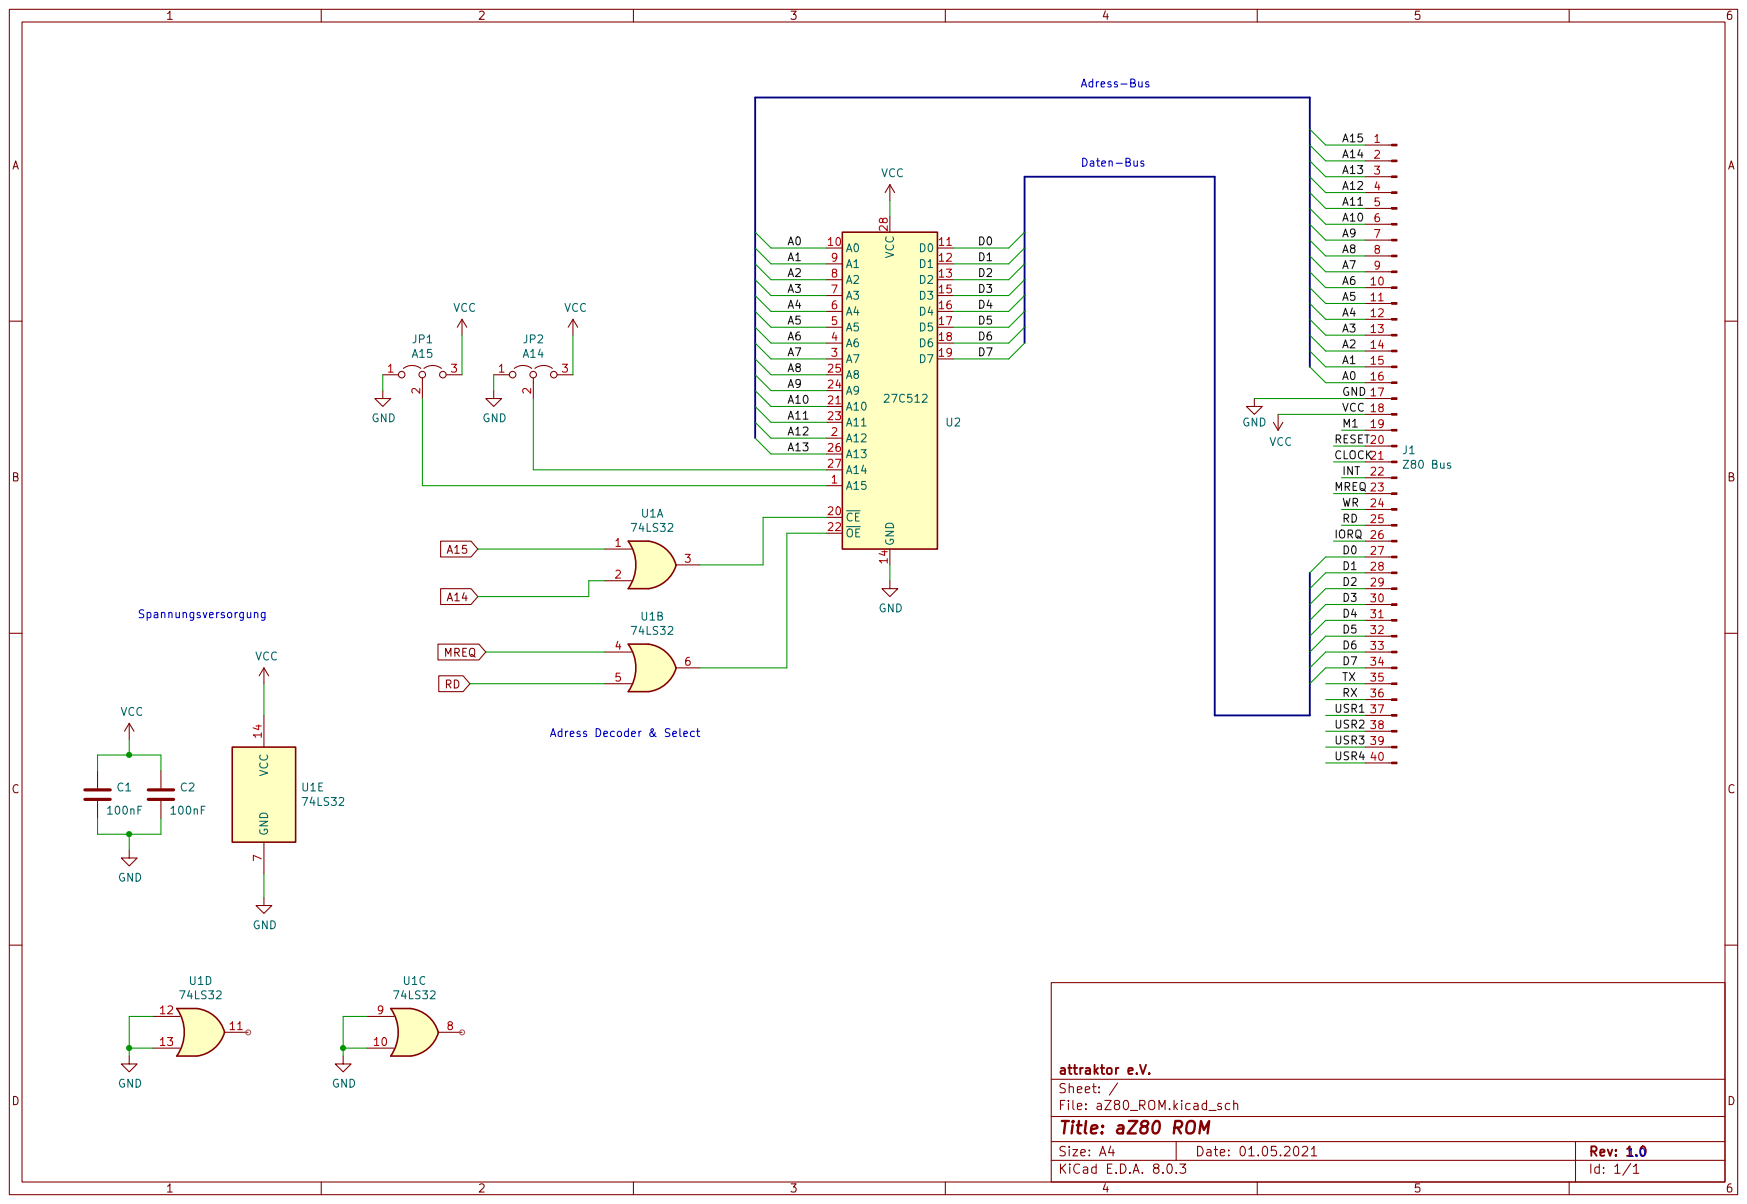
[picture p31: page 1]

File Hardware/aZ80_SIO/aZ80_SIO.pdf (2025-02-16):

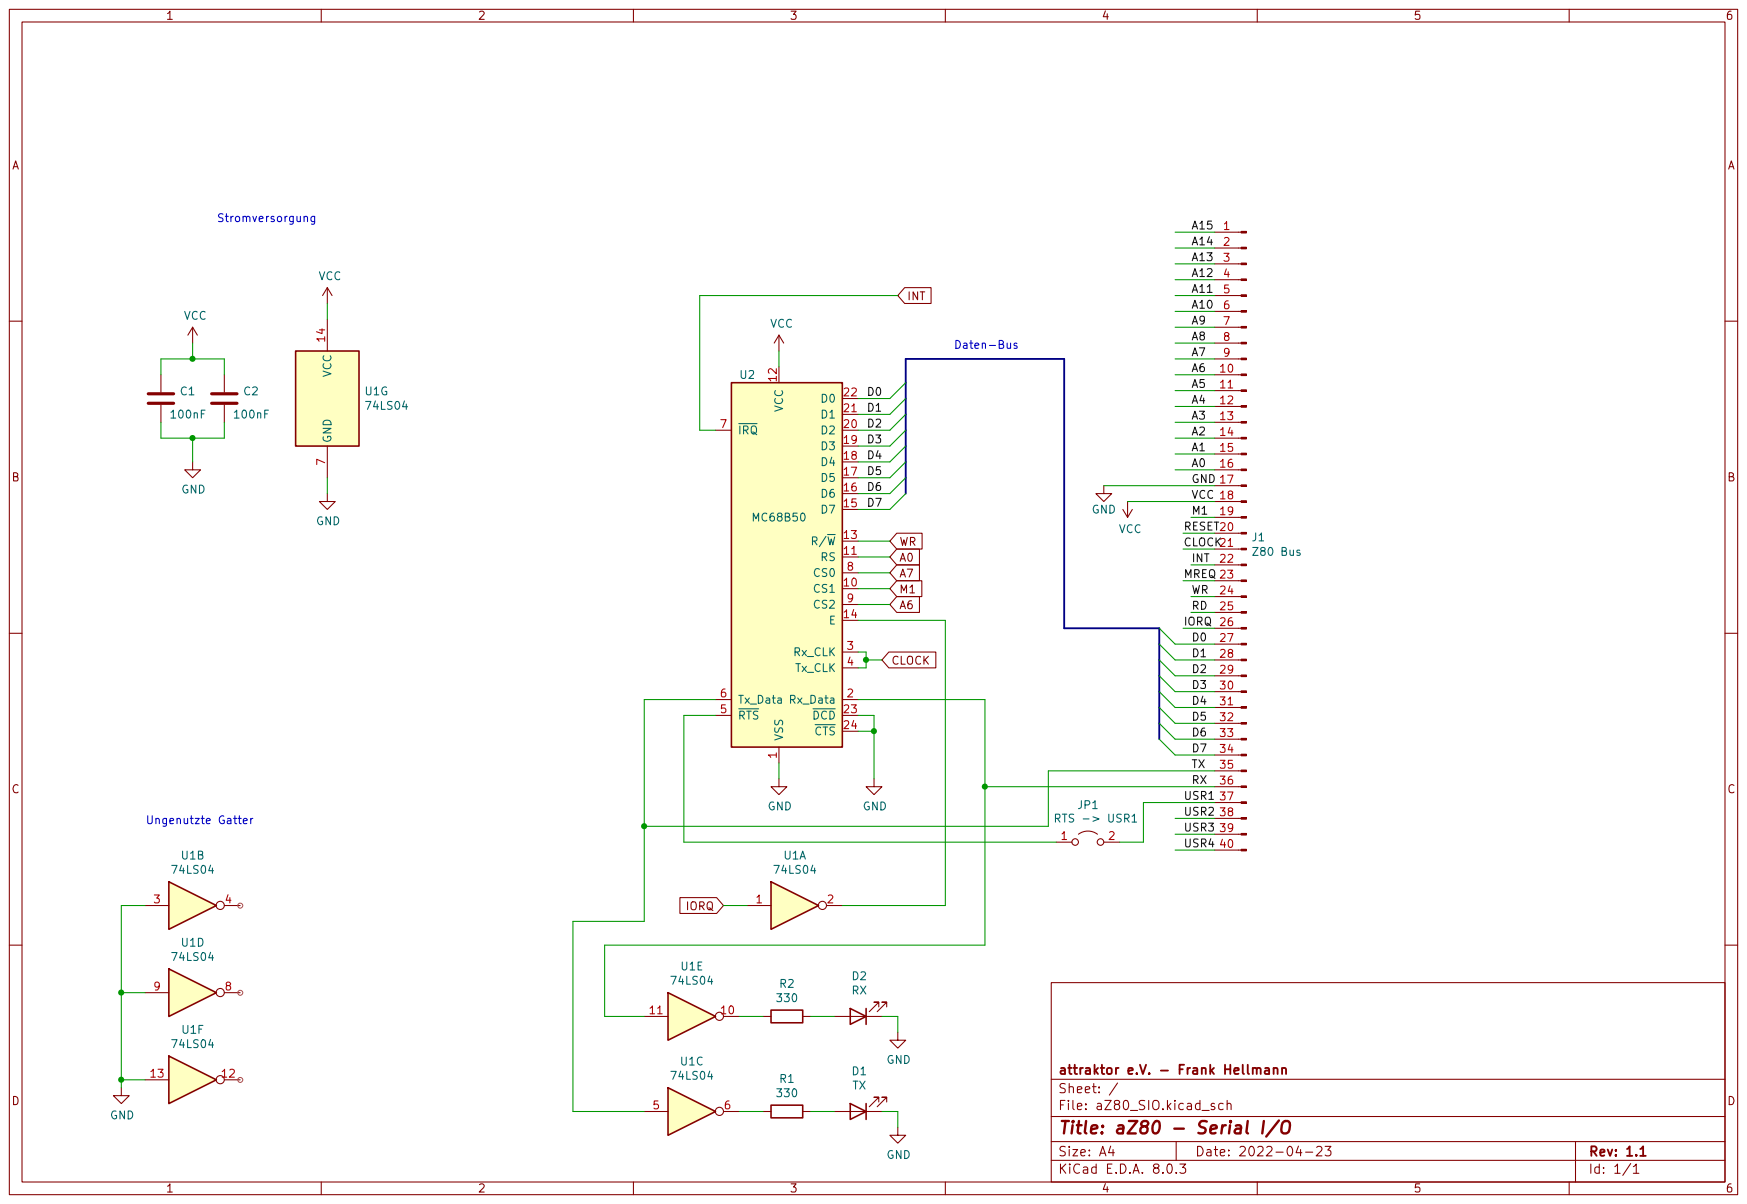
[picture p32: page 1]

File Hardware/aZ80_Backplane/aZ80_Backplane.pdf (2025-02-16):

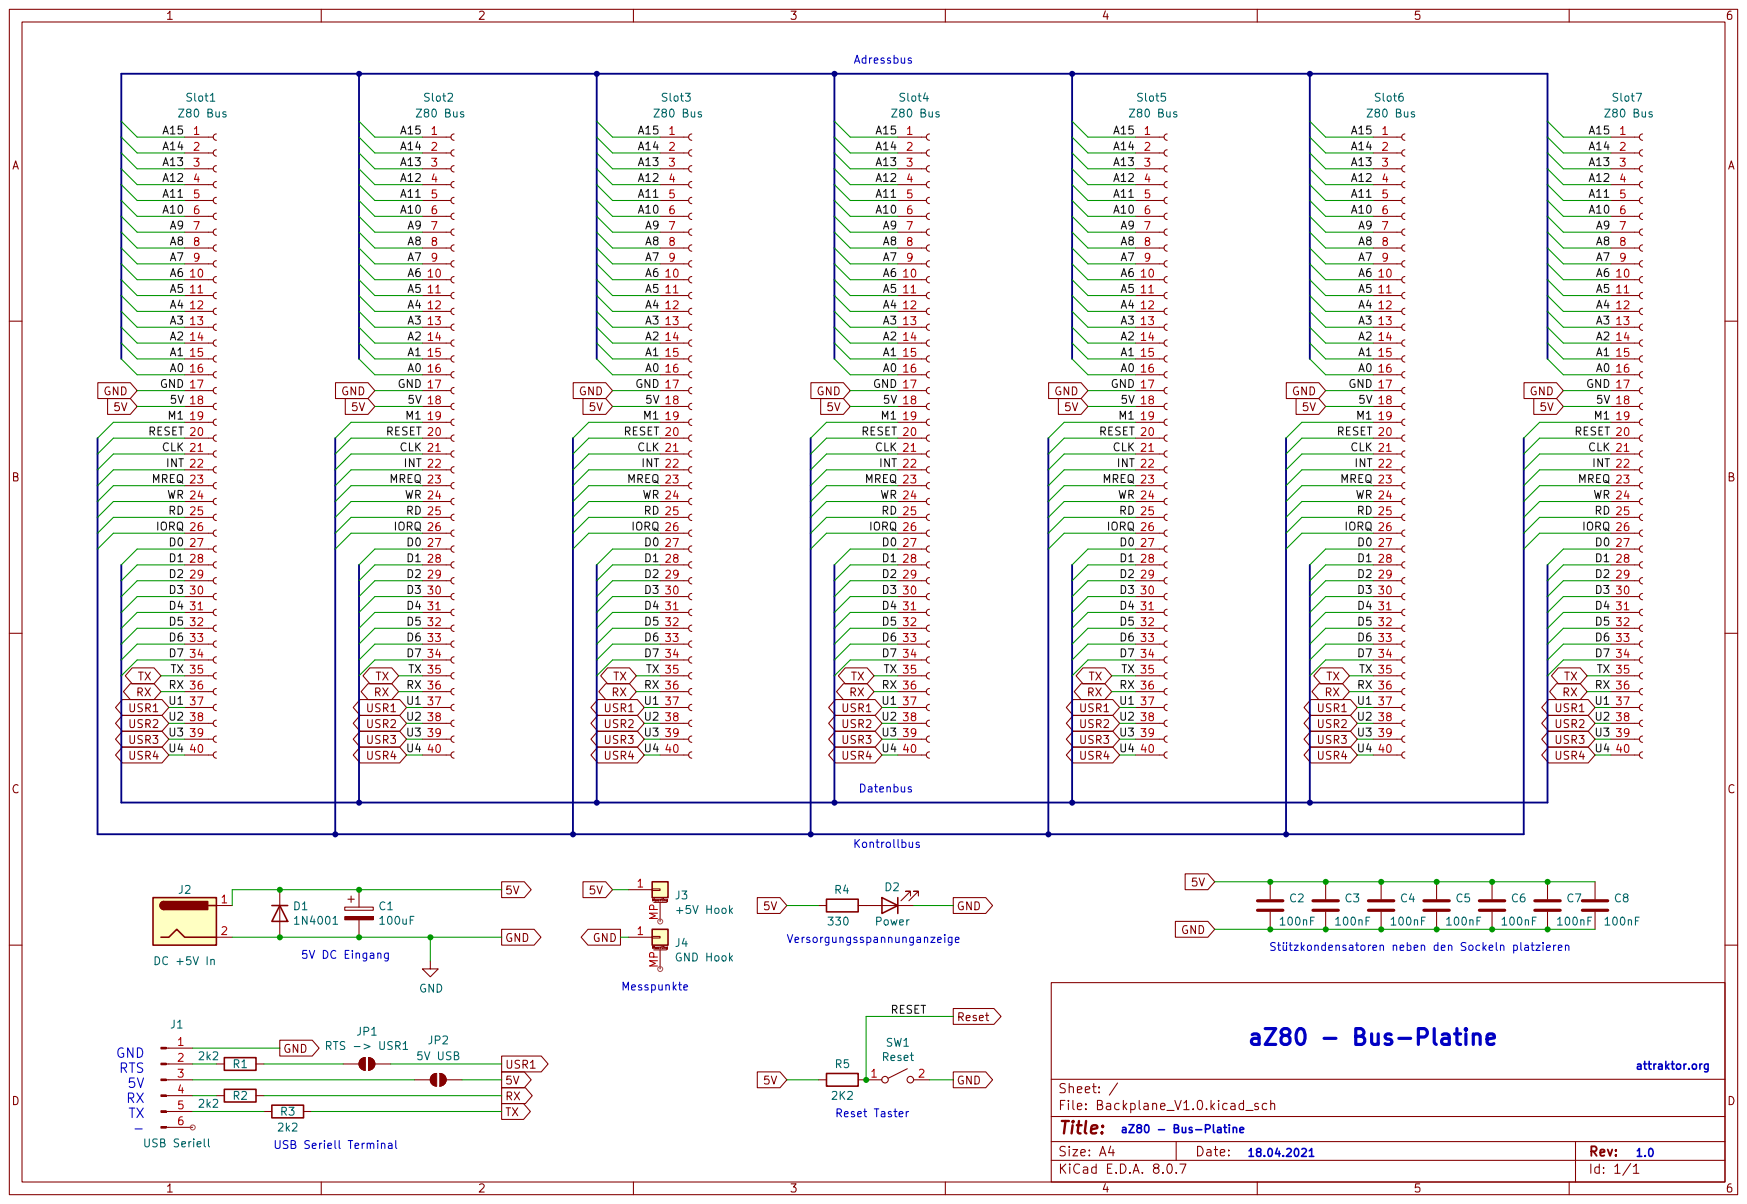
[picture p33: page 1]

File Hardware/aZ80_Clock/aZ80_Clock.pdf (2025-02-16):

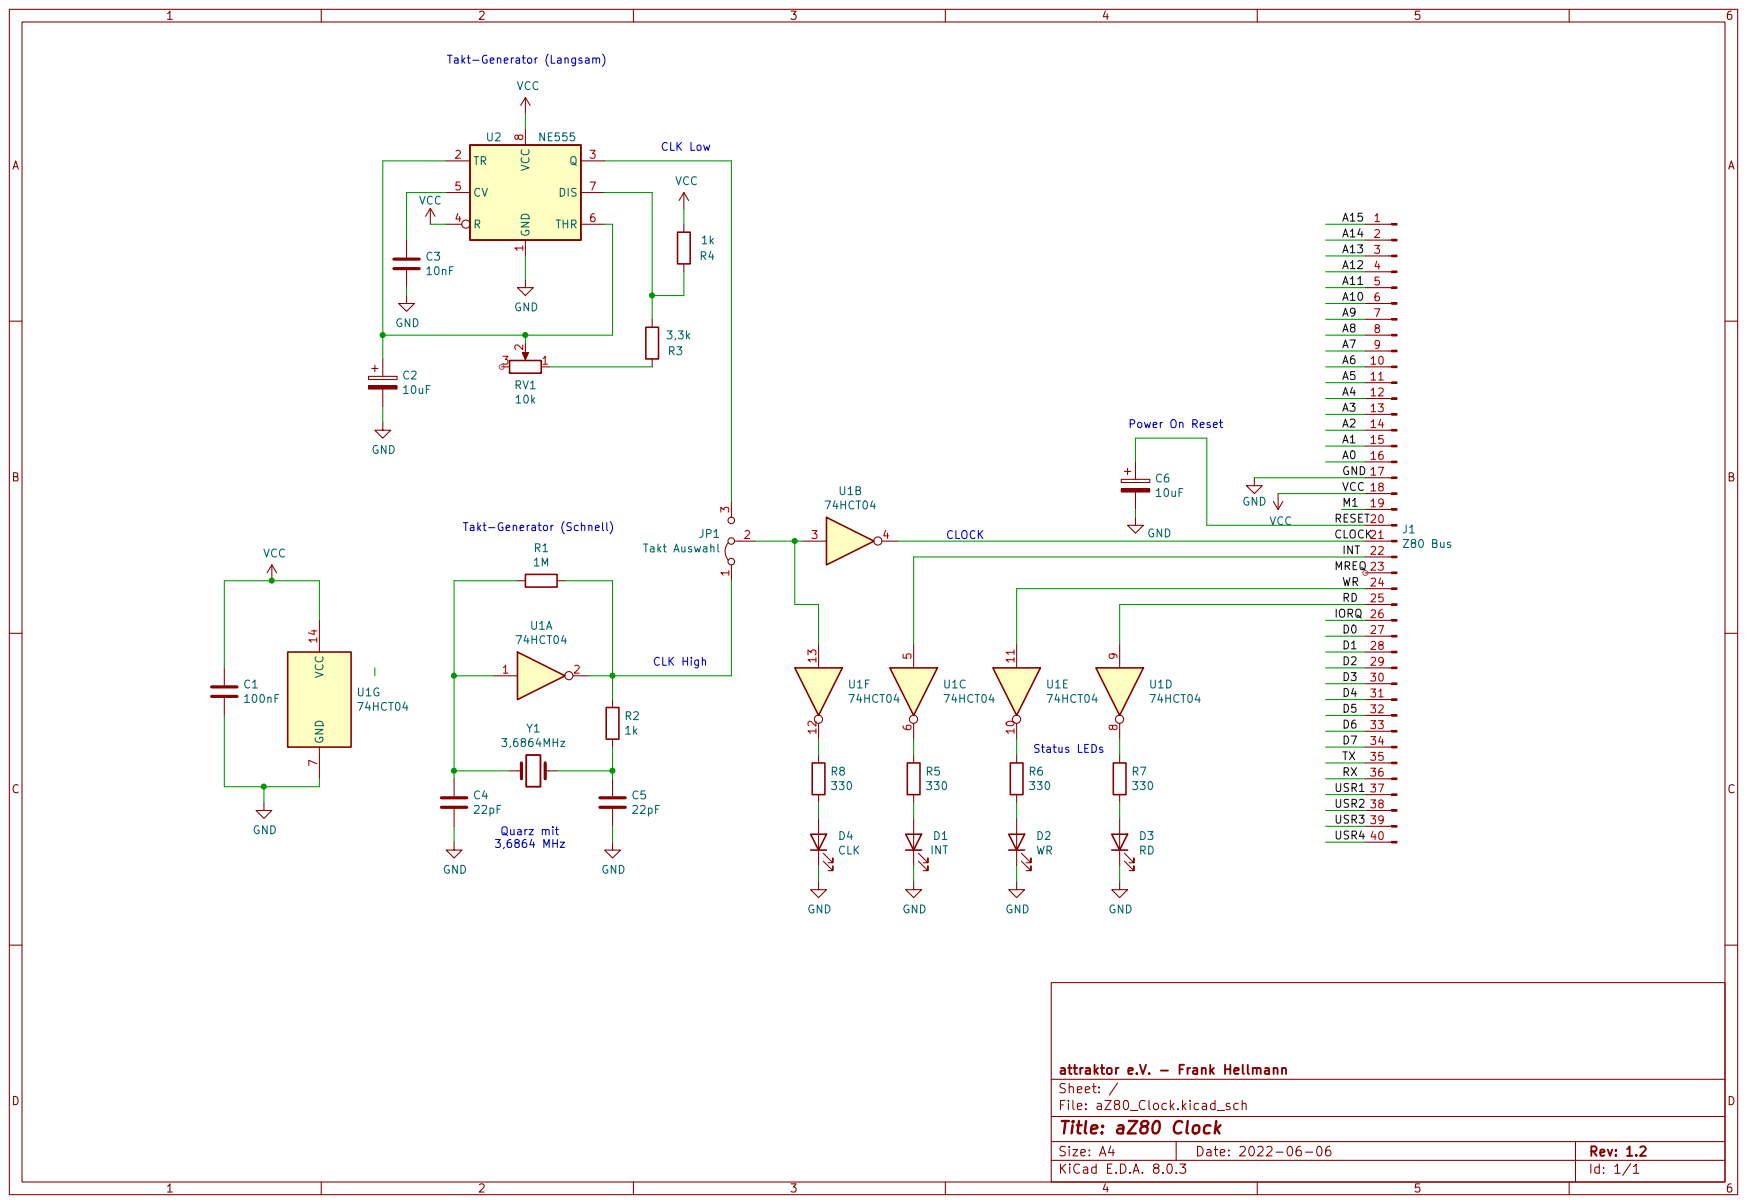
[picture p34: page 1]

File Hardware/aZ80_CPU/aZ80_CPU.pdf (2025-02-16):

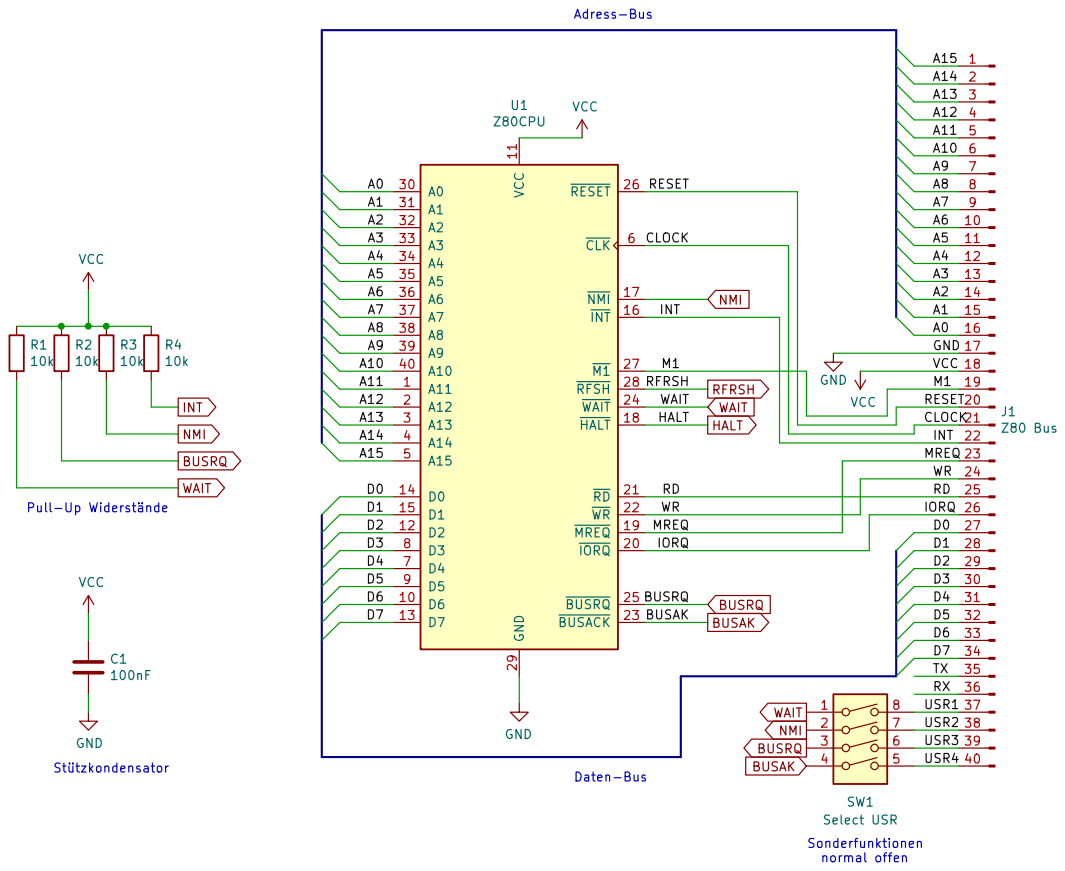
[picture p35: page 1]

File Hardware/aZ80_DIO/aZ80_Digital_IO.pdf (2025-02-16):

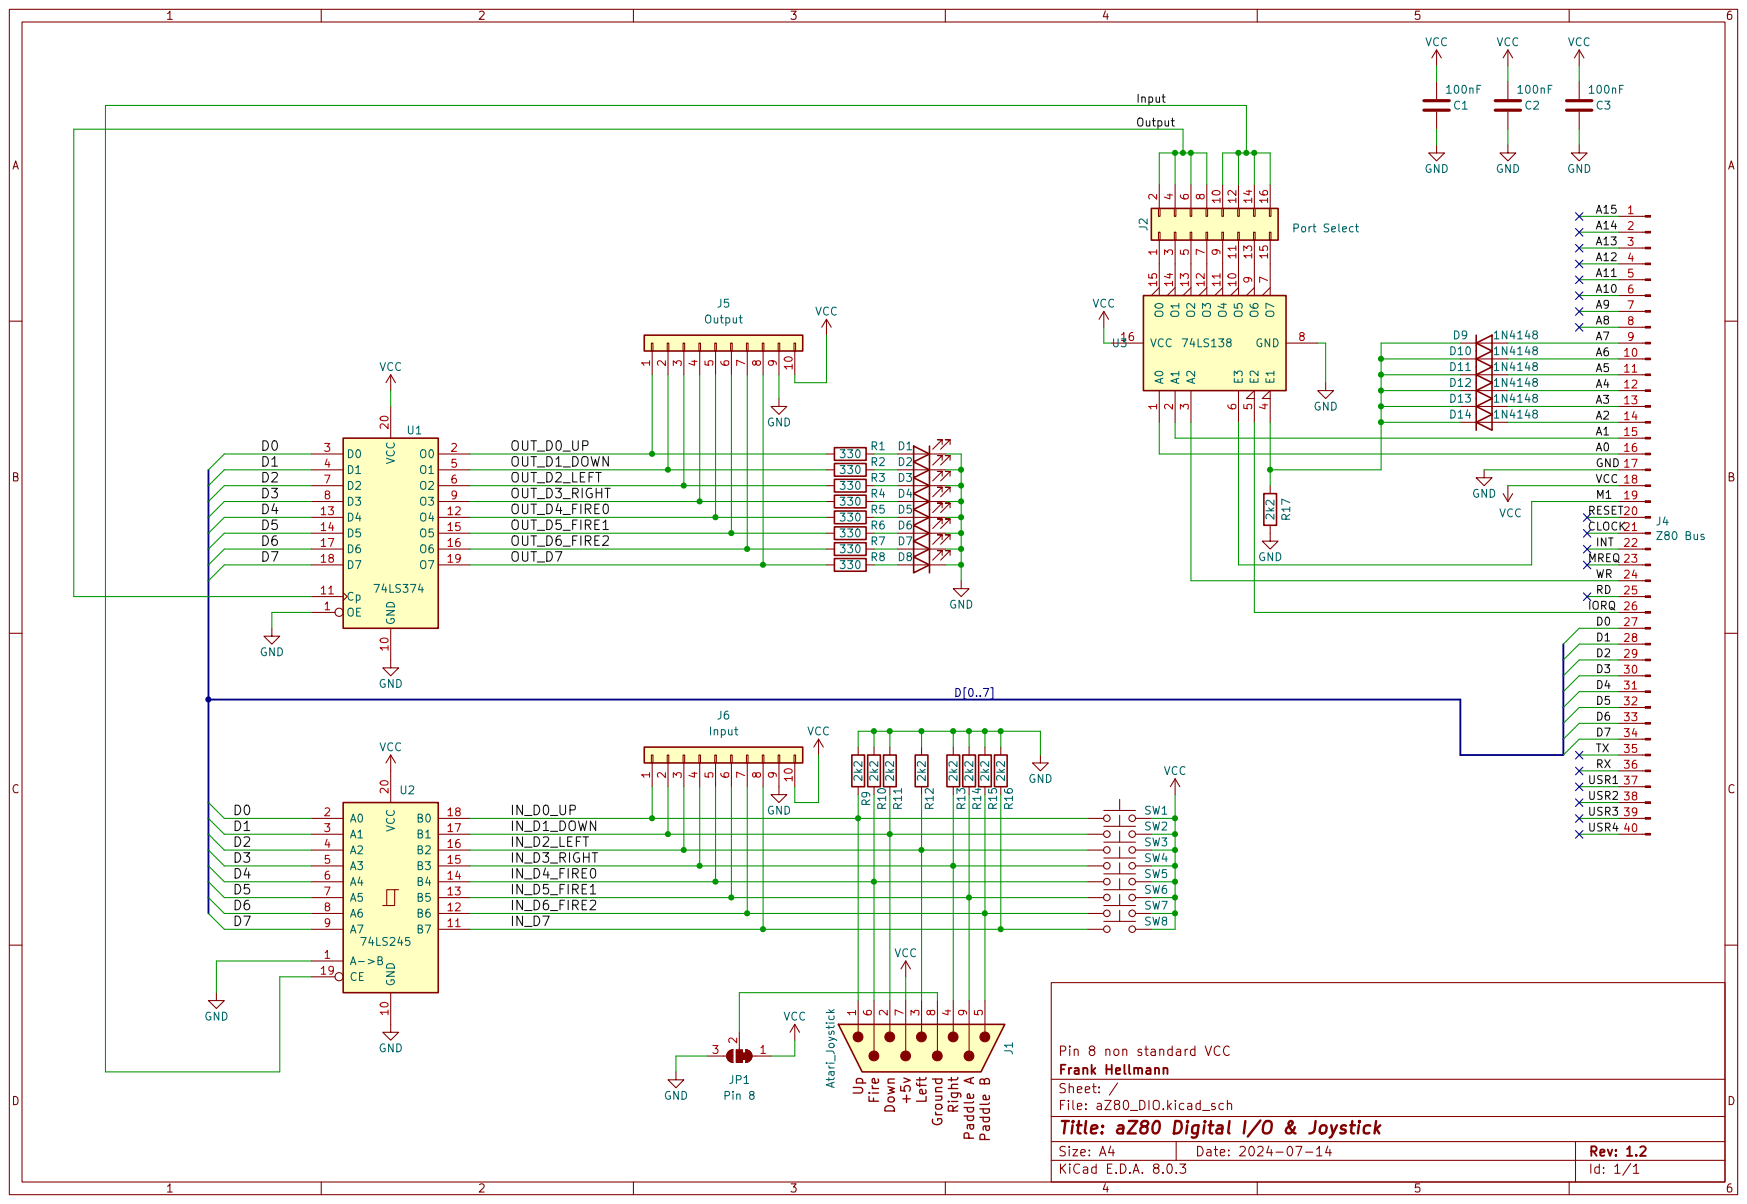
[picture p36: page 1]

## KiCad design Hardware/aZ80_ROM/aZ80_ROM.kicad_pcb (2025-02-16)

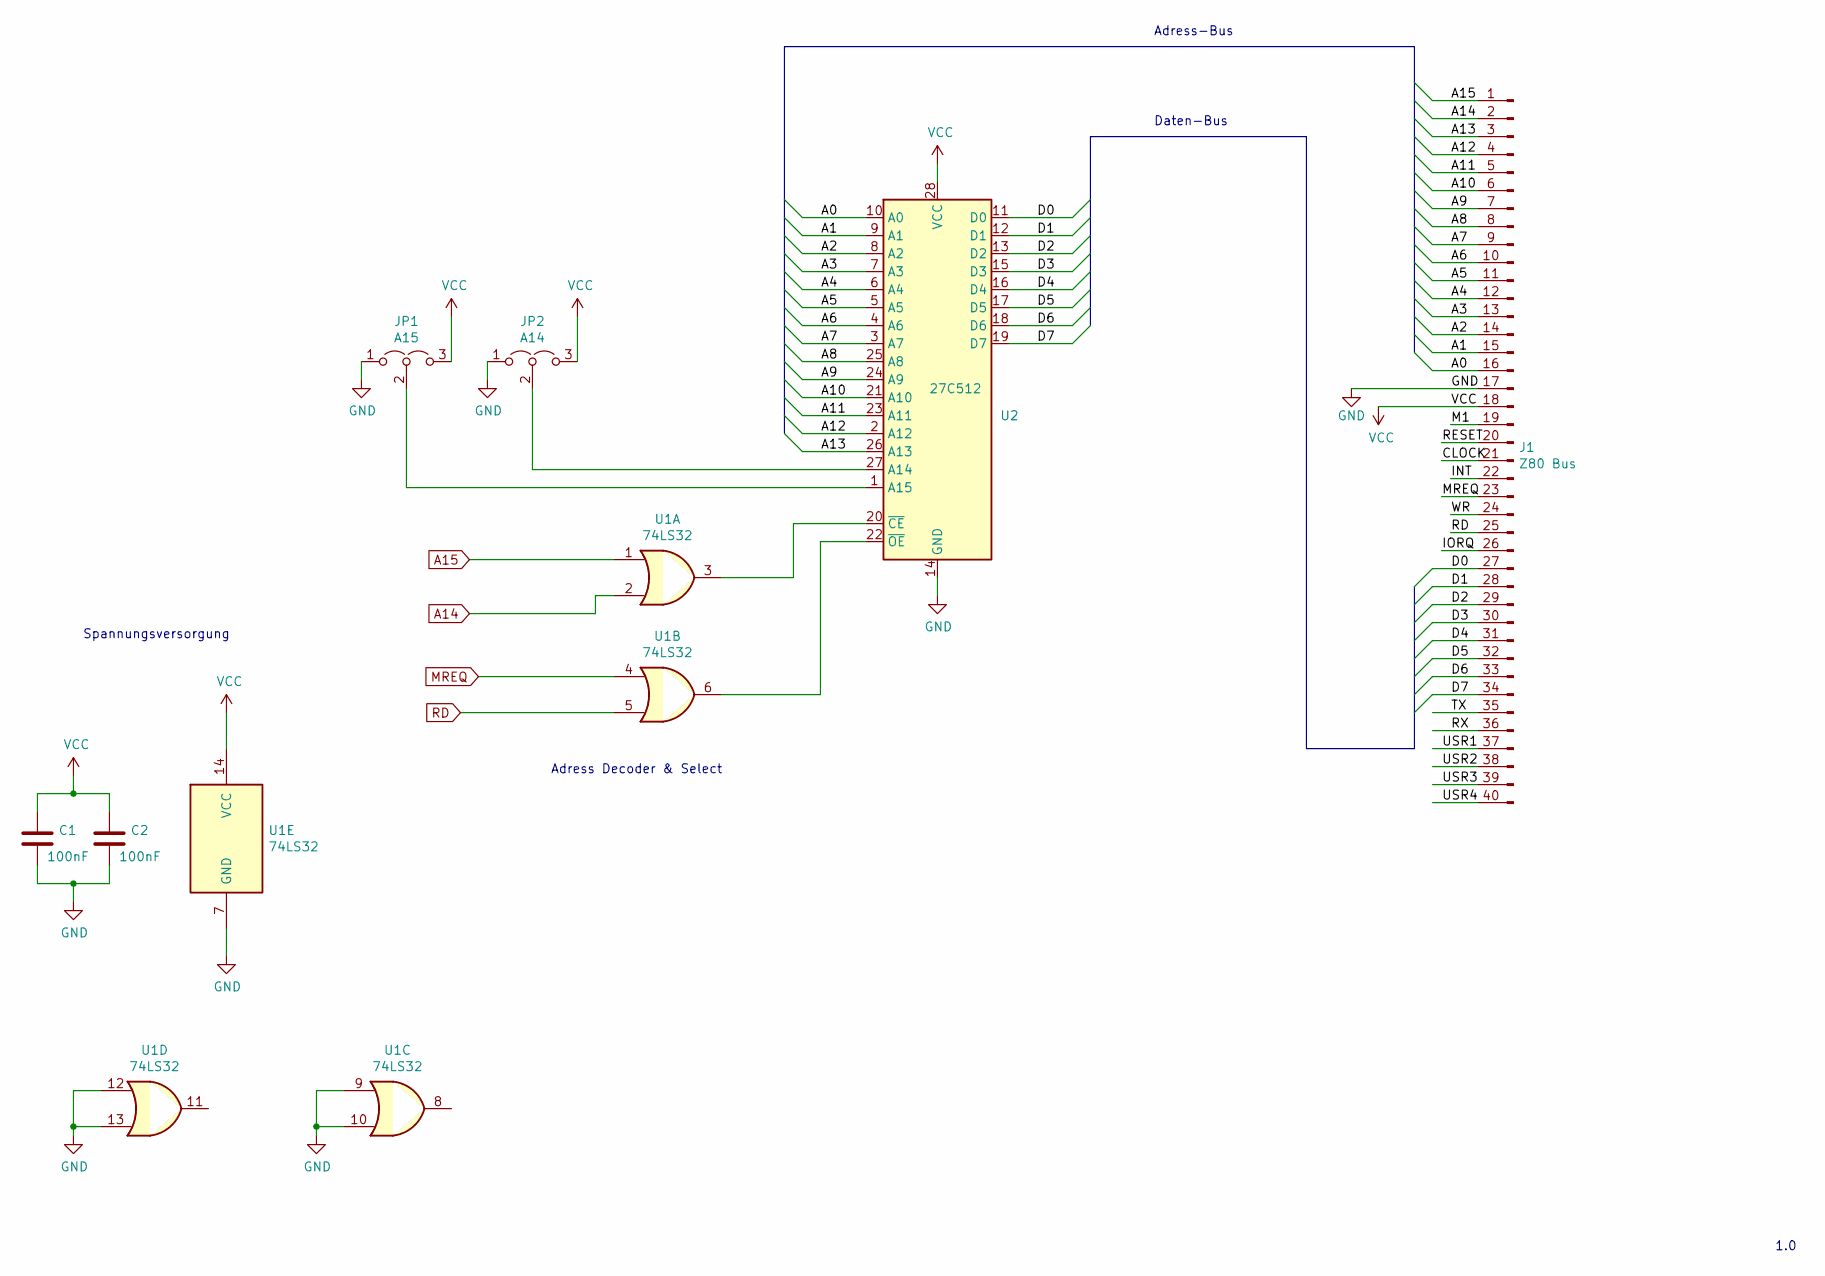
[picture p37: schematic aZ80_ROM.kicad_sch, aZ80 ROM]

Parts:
C1, C2: 100nF; C_Disc_D3.8mm_W2.6mm_P2.50mm
J1: Z80 Bus; PinHeader_1x40_P2.54mm_Horizontal
JP1: A15; PinHeader_1x03_P2.54mm_Vertical
JP2: A14; PinHeader_1x03_P2.54mm_Vertical
U1: 74LS32; DIP-14_W7.62mm_Socket_LongPads
U2: 27C512; DIP-28_W15.24mm_LongPads

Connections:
/A0: J1.16, U2.10 (A0)
/A1: J1.15, U2.9 (A1)
/A2: J1.14, U2.8 (A2)
/A3: J1.13, U2.7 (A3)
/A4: J1.12, U2.6 (A4)
/A5: J1.11, U2.5 (A5)
/A6: J1.10, U2.4 (A6)
/A7: J1.9, U2.3 (A7)
/A8: J1.8, U2.25 (A8)
/A9: J1.7, U2.24 (A9)
/A10: J1.6, U2.21 (A10)
/A11: J1.5, U2.23 (A11)
/A12: J1.4, U2.2 (A12)
/A13: J1.3, U2.26 (A13)
/CLOCK: J1.21
/D0: J1.27, U2.11 (D0)
/D1: J1.28, U2.12 (D1)
/D2: J1.29, U2.13 (D2)
/D3: J1.30, U2.15 (D3)
/D4: J1.31, U2.16 (D4)
/D5: J1.32, U2.17 (D5)
/D6: J1.33, U2.18 (D6)
/D7: J1.34, U2.19 (D7)
/INT: J1.22
/IORQ: J1.26
/M1: J1.19
/RESET: J1.20
/RX: J1.36
/TX: J1.35
/USR1: J1.37
/USR2: J1.38
/USR3: J1.39
/USR4: J1.40
/WR: J1.24
A14: J1.2, U1.2
A15: J1.1, U1.1
GND: C1.2, C2.2, J1.17, JP1.1 (A), JP2.1 (A), U1.7 (GND), U1.9, U1.10, U1.12, U1.13, U2.14 (GND)
MREQ: J1.23, U1.4
unnamed: JP1.2 (C), U2.1 (A15)
unnamed: JP2.2 (C), U2.27 (A14)
unnamed: U1.3, U2.20 (~CE)
unnamed: U1.6, U2.22 (~OE)
RD: J1.25, U1.5
VCC: C1.1, C2.1, J1.18, JP1.3 (B), JP2.3 (B), U1.14 (VCC), U2.28 (VCC)

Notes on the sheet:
Daten-Bus
Adress Decoder & Select
Adress-Bus
Spannungsversorgung
1.0

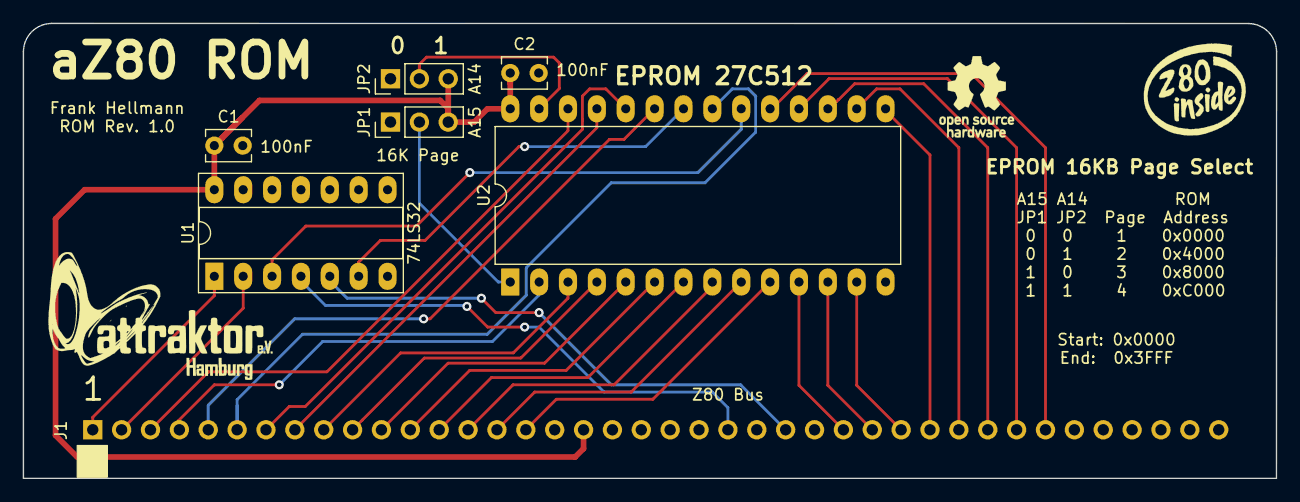
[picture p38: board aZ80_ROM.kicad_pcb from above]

Board: 2 copper layers, 110.2 x 40.0 mm, 7 parts (1 on the bottom side), 32 nets.

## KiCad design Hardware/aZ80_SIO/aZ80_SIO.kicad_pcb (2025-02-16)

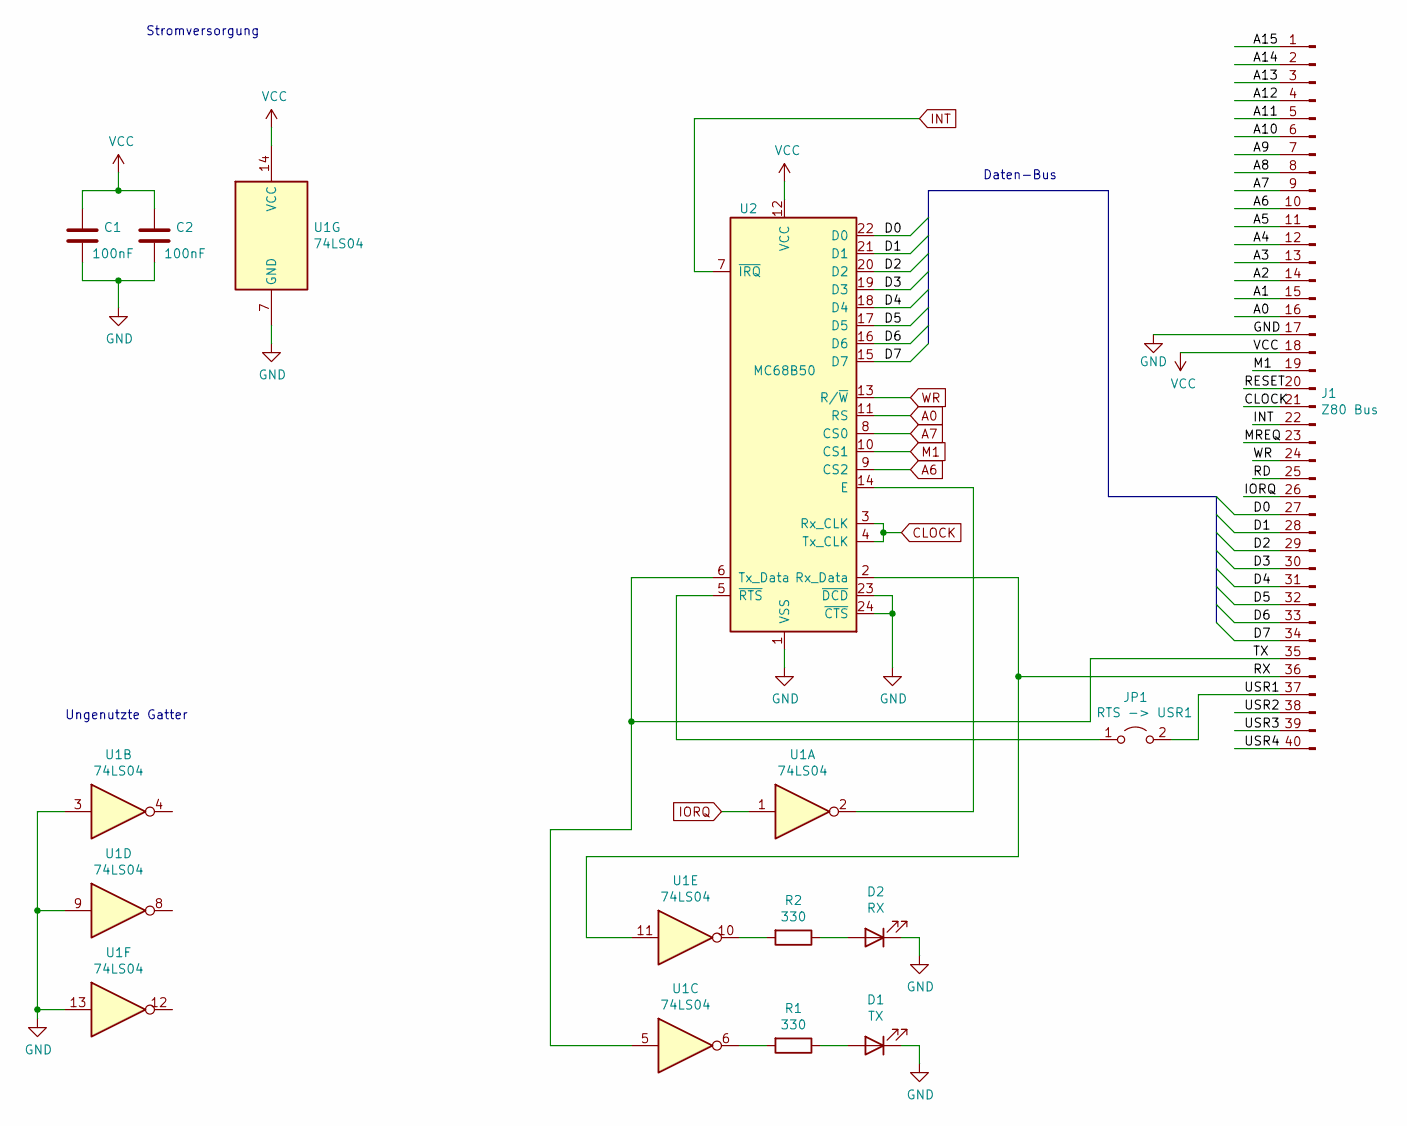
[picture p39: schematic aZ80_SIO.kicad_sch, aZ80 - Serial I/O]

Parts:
C1, C2: 100nF; C_Disc_D3.8mm_W2.6mm_P2.50mm
D1: TX; LED_D5.0mm
D2: RX; LED_D5.0mm
J1: Z80 Bus; PinHeader_1x40_P2.54mm_Horizontal
JP1: RTS -> USR1; PinSocket_1x02_P2.54mm_Vertical
R1, R2: 330; R_Axial_DIN0207_L6.3mm_D2.5mm_P10.16mm_Horizontal
U1: 74LS04; DIP-14_W7.62mm_Socket_LongPads
U2: MC68B50; DIP-24_W15.24mm_Socket_LongPads

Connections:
/A1: J1.15
/A2: J1.14
/A3: J1.13
/A4: J1.12
/A5: J1.11
/A8: J1.8
/A9: J1.7
/A10: J1.6
/A11: J1.5
/A12: J1.4
/A13: J1.3
/A14: J1.2
/A15: J1.1
/D0: J1.27, U2.22 (D0)
/D1: J1.28, U2.21 (D1)
/D2: J1.29, U2.20 (D2)
/D3: J1.30, U2.19 (D3)
/D4: J1.31, U2.18 (D4)
/D5: J1.32, U2.17 (D5)
/D6: J1.33, U2.16 (D6)
/D7: J1.34, U2.15 (D7)
/MREQ: J1.23
/RD: J1.25
/RESET: J1.20
/RX: J1.36, U1.11, U2.2 (Rx_Data)
/TX: J1.35, U1.5, U2.6 (Tx_Data)
/USR1: J1.37, JP1.2 (B)
/USR2: J1.38
/USR3: J1.39
/USR4: J1.40
A0: J1.16, U2.11 (RS)
A6: J1.10, U2.9 (CS2)
A7: J1.9, U2.8 (CS0)
CLOCK: J1.21, U2.3 (Rx_CLK), U2.4 (Tx_CLK)
GND: C1.2, C2.2, D1.1 (K), D2.1 (K), J1.17, U1.3, U1.7 (GND), U1.9, U1.13, U2.1 (VSS), U2.23 (~DCD), U2.24 (~CTS)
INT: J1.22, U2.7 (~IRQ)
IORQ: J1.26, U1.1
M1: J1.19, U2.10 (CS1)
unnamed: D1.2 (A), R1.1
unnamed: D2.2 (A), R2.1
unnamed: JP1.1 (A), U2.5 (~RTS)
unnamed: R1.2, U1.6
unnamed: R2.2, U1.10
unnamed: U1.2, U2.14 (E)
VCC: C1.1, C2.1, J1.18, U1.14 (VCC), U2.12 (VCC)
WR: J1.24, U2.13 (R/~W)

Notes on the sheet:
Daten-Bus
Ungenutzte Gatter
Stromversorgung

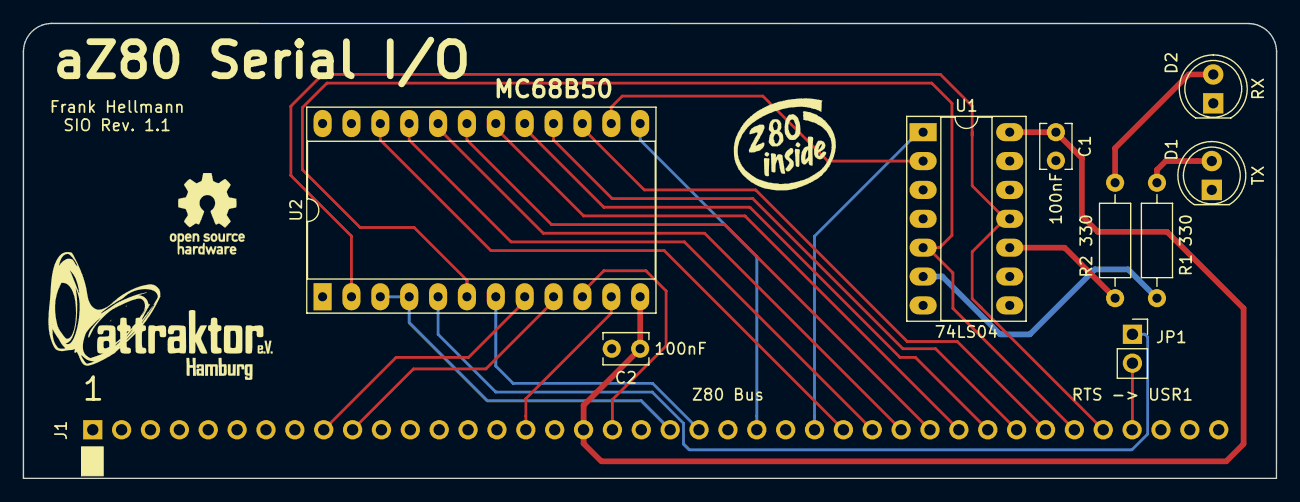
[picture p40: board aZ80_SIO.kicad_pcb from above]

Board: 2 copper layers, 110.2 x 40.0 mm, 10 parts (1 on the bottom side), 27 nets.

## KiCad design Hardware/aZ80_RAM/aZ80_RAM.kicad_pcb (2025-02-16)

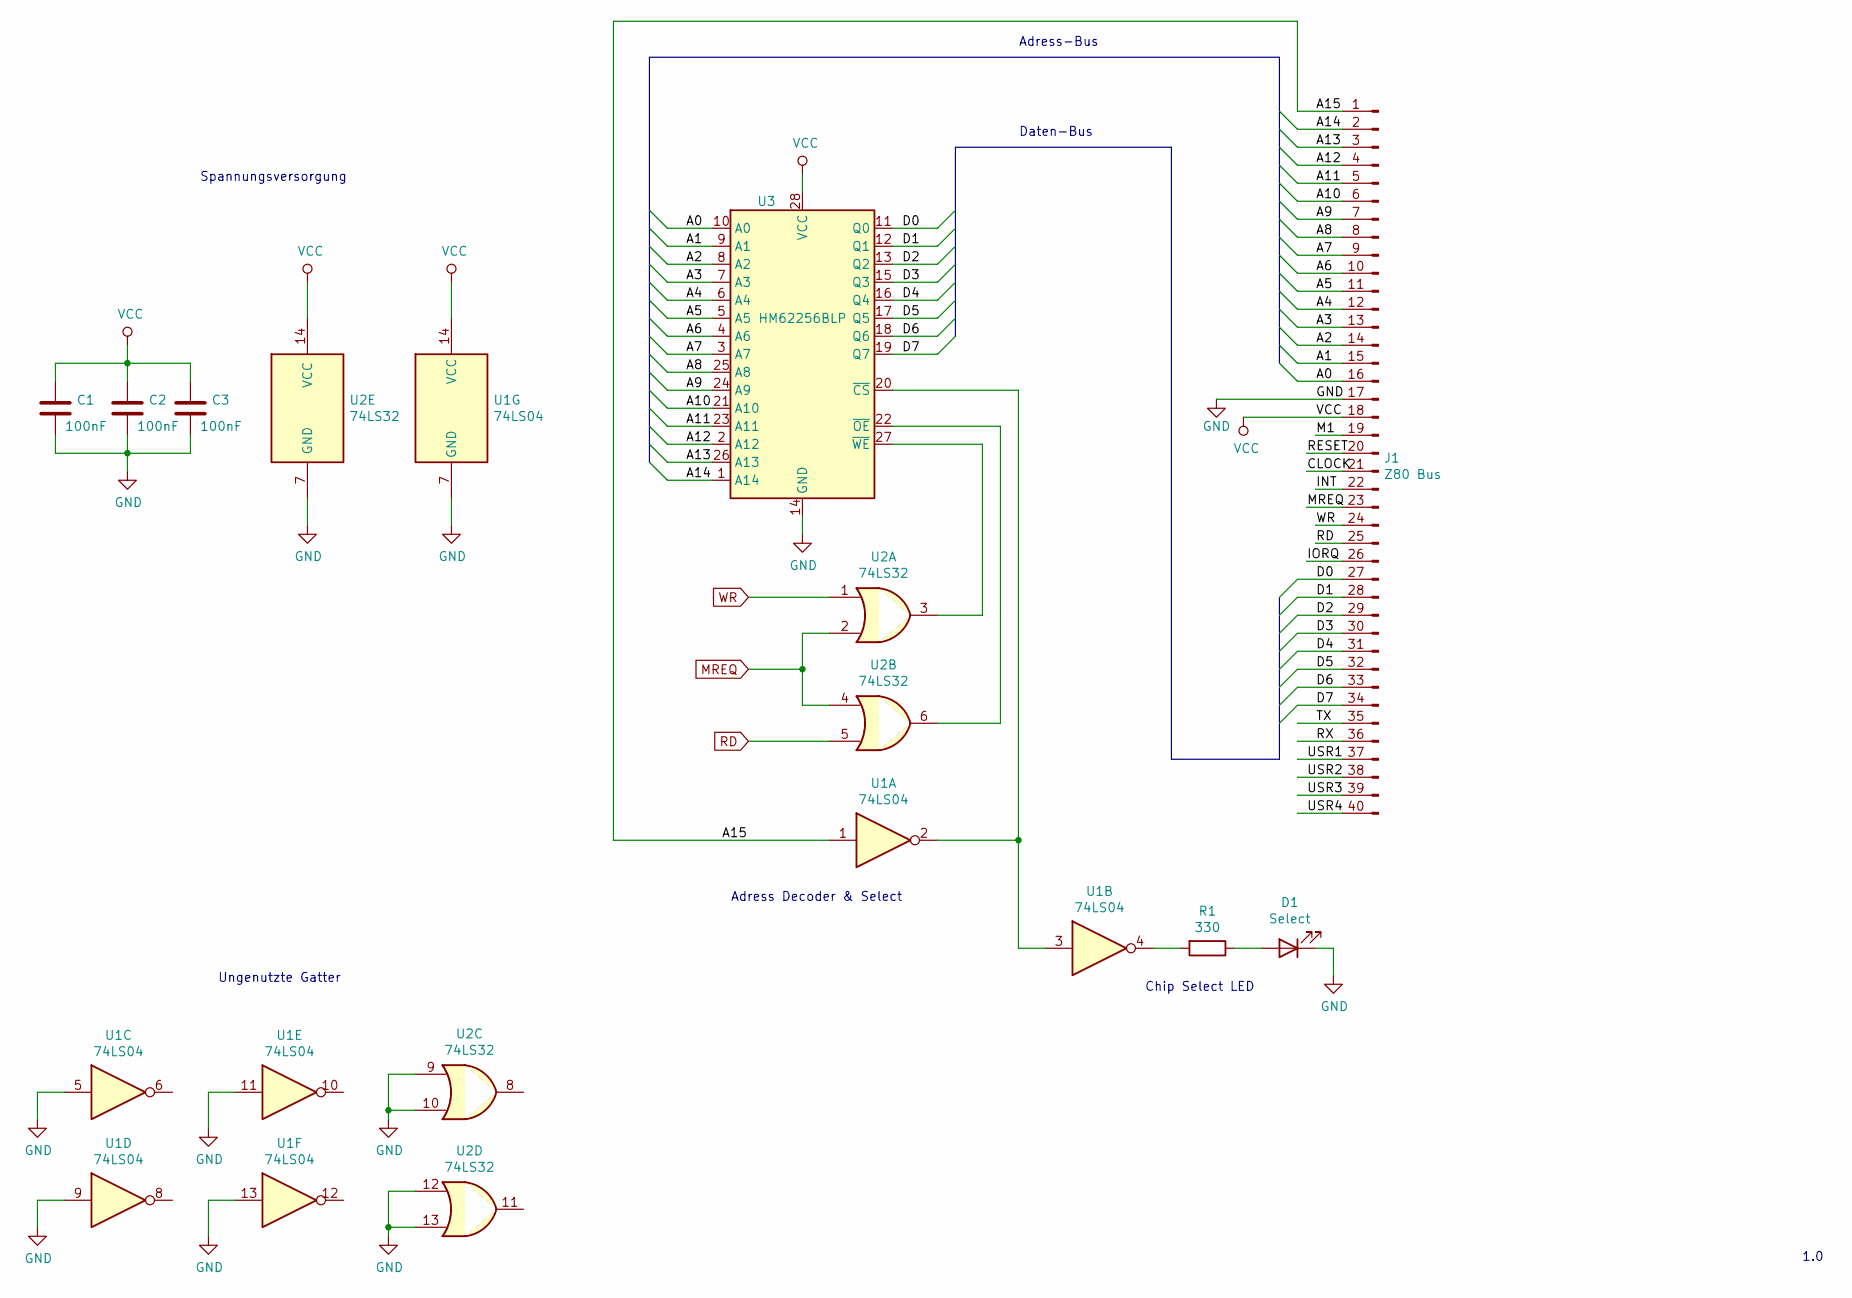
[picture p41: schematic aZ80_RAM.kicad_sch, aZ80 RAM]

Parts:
C1, C2, C3: 100nF; C_Disc_D3.8mm_W2.6mm_P2.50mm
D1: Select; LED_D5.0mm
J1: Z80 Bus; PinHeader_1x40_P2.54mm_Horizontal
R1: 330; R_Axial_DIN0207_L6.3mm_D2.5mm_P10.16mm_Horizontal
U1: 74LS04; DIP-14_W7.62mm_Socket_LongPads
U2: 74LS32; DIP-14_W7.62mm_Socket_LongPads
U3: HM62256BLP; DIP-28_W15.24mm_LongPads

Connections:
/A0: J1.16, U3.10 (A0)
/A1: J1.15, U3.9 (A1)
/A2: J1.14, U3.8 (A2)
/A3: J1.13, U3.7 (A3)
/A4: J1.12, U3.6 (A4)
/A5: J1.11, U3.5 (A5)
/A6: J1.10, U3.4 (A6)
/A7: J1.9, U3.3 (A7)
/A8: J1.8, U3.25 (A8)
/A9: J1.7, U3.24 (A9)
/A10: J1.6, U3.21 (A10)
/A11: J1.5, U3.23 (A11)
/A12: J1.4, U3.2 (A12)
/A13: J1.3, U3.26 (A13)
/A14: J1.2, U3.1 (A14)
/A15: J1.1, U1.1
/CLOCK: J1.21
/D0: J1.27, U3.11 (Q0)
/D1: J1.28, U3.12 (Q1)
/D2: J1.29, U3.13 (Q2)
/D3: J1.30, U3.15 (Q3)
/D4: J1.31, U3.16 (Q4)
/D5: J1.32, U3.17 (Q5)
/D6: J1.33, U3.18 (Q6)
/D7: J1.34, U3.19 (Q7)
/INT: J1.22
/IORQ: J1.26
/M1: J1.19
/RESET: J1.20
/RX: J1.36
/TX: J1.35
/USR1: J1.37
/USR2: J1.38
/USR3: J1.39
/USR4: J1.40
GND: C1.2, C2.2, C3.2, D1.1 (K), J1.17, U1.5, U1.7 (GND), U1.9, U1.11, U1.13, U2.7 (GND), U2.9, U2.10, U2.12, U2.13, U3.14 (GND)
MREQ: J1.23, U2.2, U2.4
unnamed: D1.2 (A), R1.1
unnamed: R1.2, U1.4
unnamed: U1.2, U1.3, U3.20 (~CS)
unnamed: U2.3, U3.27 (~WE)
unnamed: U2.6, U3.22 (~OE)
RD: J1.25, U2.5
VCC: C1.1, C2.1, C3.1, J1.18, U1.14 (VCC), U2.14 (VCC), U3.28 (VCC)
WR: J1.24, U2.1

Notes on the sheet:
Daten-Bus
Ungenutzte Gatter
Adress-Bus
Chip Select LED
1.0
Spannungsversorgung
Adress Decoder & Select

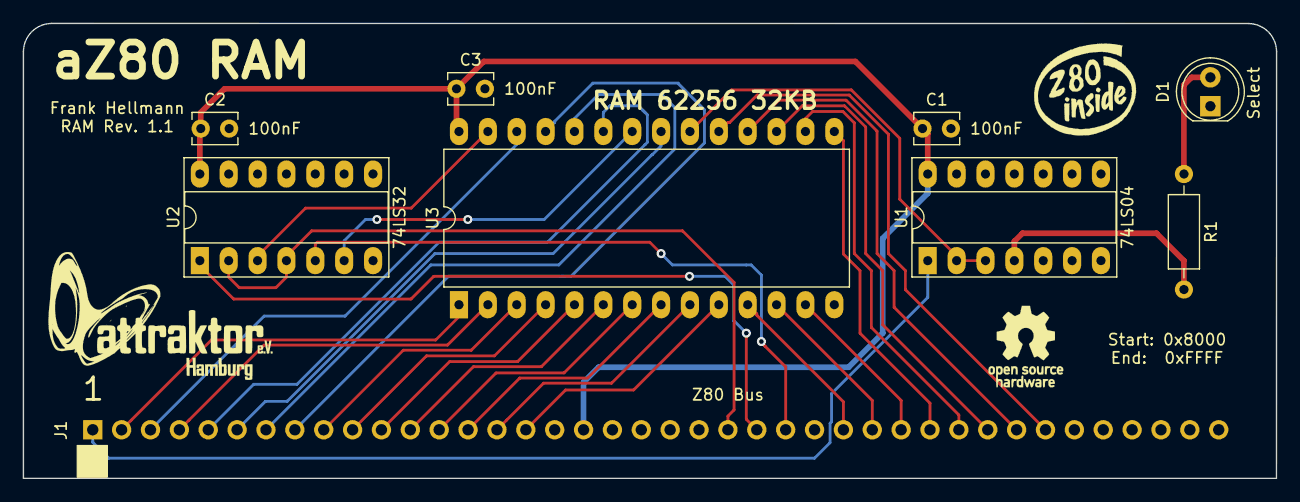
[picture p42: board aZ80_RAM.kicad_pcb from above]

Board: 2 copper layers, 110.2 x 40.0 mm, 9 parts (1 on the bottom side), 34 nets.

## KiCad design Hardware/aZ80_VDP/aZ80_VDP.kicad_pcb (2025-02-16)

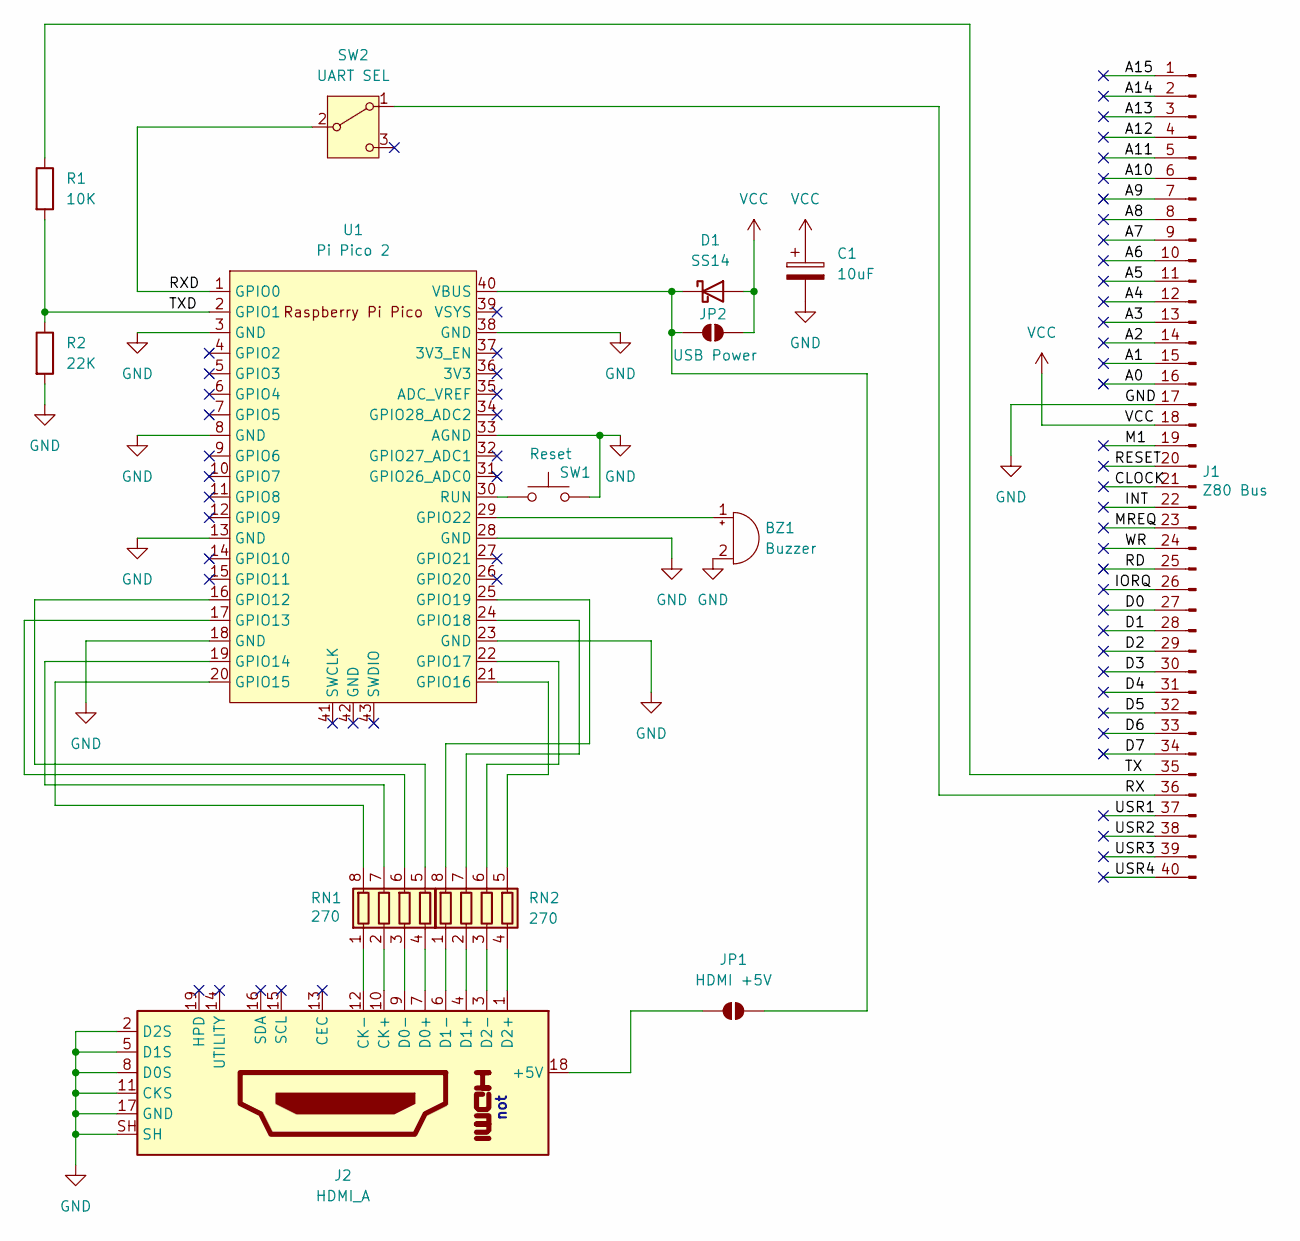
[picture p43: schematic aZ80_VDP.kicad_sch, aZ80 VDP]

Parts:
BZ1: Buzzer; Buzzer_12x9.5RM7.6
C1: 10uF; CP_Elec_4x5.7
D1: SS14; D_SMA
J1: Z80 Bus; PinHeader_1x40_P2.54mm_Horizontal
J2: HDMI_A; HDMI_A_Molex_208658-1001_Horizontal
JP1: HDMI +5V; SolderJumper-2_P1.3mm_Open_RoundedPad1.0x1.5mm
JP2: USB Power; SolderJumper-2_P1.3mm_Open_RoundedPad1.0x1.5mm
R1: 10K; R_0603_1608Metric
R2: 22K; R_0603_1608Metric
RN1, RN2: 270; R_Array_Convex_4x0603
SW1: Reset; SW_Push_1P1T_NO_6x6mm_H9.5mm
SW2: UART SEL; SW_Slide_SPDT_Angled_CK_OS102011MA1Q
U1: Pi Pico 2; RPi_Pico_SMD_TH

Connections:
/A0: J1.16
/A1: J1.15
/A2: J1.14
/A3: J1.13
/A4: J1.12
/A5: J1.11
/A6: J1.10
/A7: J1.9
/A8: J1.8
/A9: J1.7
/A10: J1.6
/A11: J1.5
/A12: J1.4
/A13: J1.3
/A14: J1.2
/A15: J1.1
/CLOCK: J1.21
/D0: J1.27
/D1: J1.28
/D2: J1.29
/D3: J1.30
/D4: J1.31
/D5: J1.32
/D6: J1.33
/D7: J1.34
/INT: J1.22
/IORQ: J1.26
/M1: J1.19
/MREQ: J1.23
/RD: J1.25
/RESET: J1.20
/RX: J1.36, SW2.1 (A); also elsewhere on the board
/RXD: SW2.2 (B), U1.1 (GPIO0); also elsewhere on the board
/TX: J1.35, R1.1
/TXD: R1.2, R2.1, U1.2 (GPIO1)
/USR1: J1.37
/USR2: J1.38
/USR3: J1.39
/USR4: J1.40
/WR: J1.24
GND: BZ1.2 (-), C1.2, J1.17, J2.2 (D2S), J2.5 (D1S), J2.8 (D0S), J2.11 (CKS), J2.17 (GND), J2.SH, R2.2, SW1.2, U1.3 (GND), U1.8 (GND), U1.13 (GND), U1.18 (GND), U1.23 (GND), U1.28 (GND), U1.33 (AGND), U1.38 (GND)
unnamed: BZ1.1 (+), U1.29 (GPIO22)
unnamed: D1.1 (K), JP1.2 (B), JP2.1 (A), U1.40 (VBUS)
unnamed: J2.18 (+5V), JP1.1 (A)
unnamed: J2.10 (CK+), RN1.2 (R2.1)
unnamed: J2.12 (CK-), RN1.1 (R1.1)
unnamed: J2.7 (D0+), RN1.4 (R4.1)
unnamed: J2.9 (D0-), RN1.3 (R3.1)
unnamed: J2.4 (D1+), RN2.2 (R2.1)
unnamed: J2.6 (D1-), RN2.1 (R1.1)
unnamed: J2.1 (D2+), RN2.4 (R4.1)
unnamed: J2.3 (D2-), RN2.3 (R3.1)
unnamed: RN1.8 (R1.2), U1.20 (GPIO15)
unnamed: RN1.7 (R2.2), U1.19 (GPIO14)
unnamed: RN1.6 (R3.2), U1.17 (GPIO13)
unnamed: RN1.5 (R4.2), U1.16 (GPIO12)
unnamed: RN2.8 (R1.2), U1.25 (GPIO19)
unnamed: RN2.7 (R2.2), U1.24 (GPIO18)
unnamed: RN2.6 (R3.2), U1.22 (GPIO17)
unnamed: RN2.5 (R4.2), U1.21 (GPIO16)
unnamed: SW1.1, U1.30 (RUN)
VCC: C1.1, D1.2 (A), J1.18, JP2.2 (B)

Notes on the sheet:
not

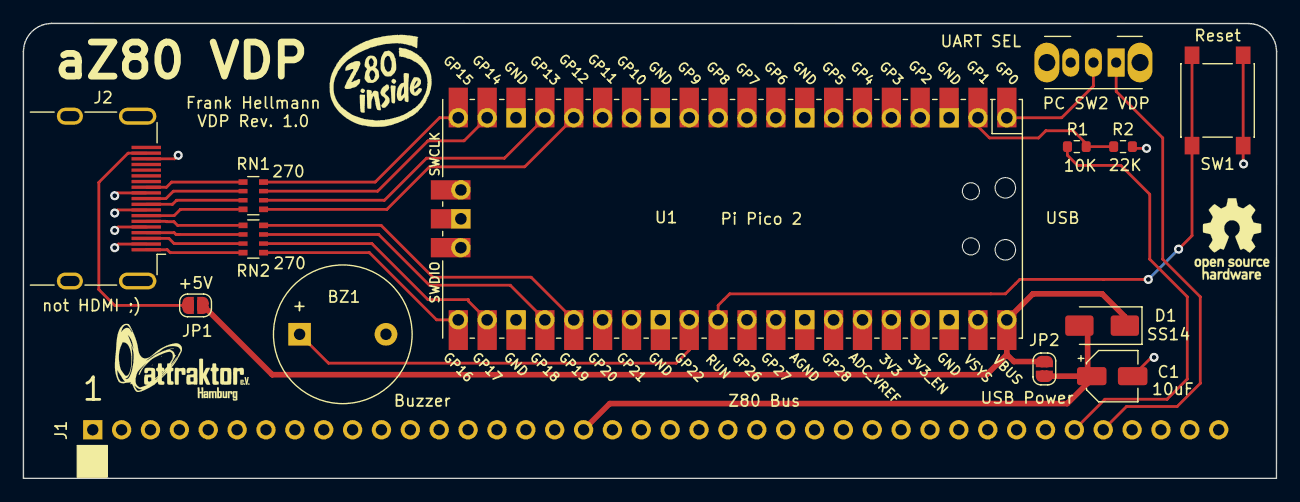
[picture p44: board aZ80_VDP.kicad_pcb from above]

Board: 2 copper layers, 110.2 x 40.0 mm, 14 parts (1 on the bottom side), 26 nets.

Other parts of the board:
PC SW2 VDP: UART SEL; SW_Slide_SPDT_Angled_CK_OS102011MA1Q

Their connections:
/RX: PC SW2 VDP.1 (A); also elsewhere on the board
/RXD: PC SW2 VDP.2 (B); also elsewhere on the board

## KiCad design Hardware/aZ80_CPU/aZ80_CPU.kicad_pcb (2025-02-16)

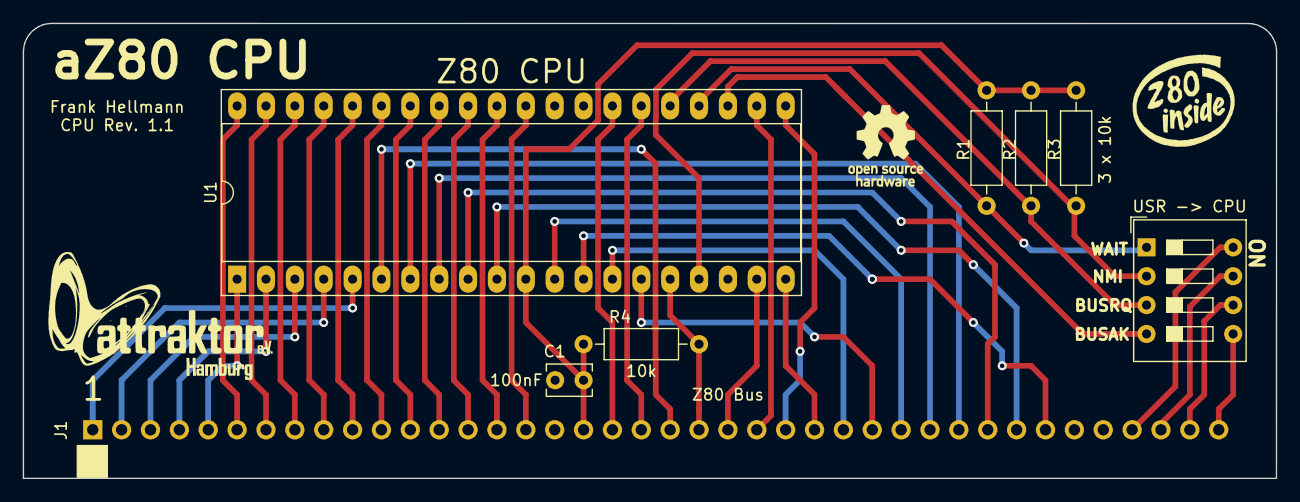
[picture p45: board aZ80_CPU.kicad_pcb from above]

Board: 2 copper layers, 110.2 x 40.0 mm, 8 parts (1 on the bottom side), 42 nets.

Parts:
C1: 100nF; C_Disc_D3.8mm_W2.6mm_P2.50mm
J1: Z80 Bus; PinHeader_1x40_P2.54mm_Horizontal
R1, R2, R4: 10k; R_Axial_DIN0207_L6.3mm_D2.5mm_P10.16mm_Horizontal
R3: 3 x 10k; R_Axial_DIN0207_L6.3mm_D2.5mm_P10.16mm_Horizontal
U1: Z80CPU; DIP-40_W15.24mm_Socket_LongPads
USR -> CPU: Select USR; SW_DIP_SPSTx04_Slide_9.78x12.34mm_W7.62mm_P2.54mm

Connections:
/A0: J1.16, U1.30
/A1: J1.15, U1.31
/A2: J1.14, U1.32
/A3: J1.13, U1.33
/A4: J1.12, U1.34
/A5: J1.11, U1.35
/A6: J1.10, U1.36
/A7: J1.9, U1.37
/A8: J1.8, U1.38
/A9: J1.7, U1.39
/A10: J1.6, U1.40
/A11: J1.5, U1.1
/A12: J1.4, U1.2
/A13: J1.3, U1.3
/A14: J1.2, U1.4
/A15: J1.1, U1.5
/CLOCK: J1.21, U1.6
/D0: J1.27, U1.14
/D1: J1.28, U1.15
/D2: J1.29, U1.12
/D3: J1.30, U1.8
/D4: J1.31, U1.7
/D5: J1.32, U1.9
/D6: J1.33, U1.10
/D7: J1.34, U1.13
/IORQ: J1.26, U1.20
/M1: J1.19, U1.27
/MREQ: J1.23, U1.19
/RD: J1.25, U1.21
/RESET: J1.20, U1.26
/USR1: J1.37, USR -> CPU.8
/USR2: J1.38, USR -> CPU.7
/USR3: J1.39, USR -> CPU.6
/USR4: J1.40, USR -> CPU.5
/WR: J1.24, U1.22
BUSAK: U1.23, USR -> CPU.4
BUSRQ: R2.2, U1.25, USR -> CPU.3
GND: C1.2, J1.17, U1.29
INT: J1.22, R4.2, U1.16
NMI: R3.2, U1.17, USR -> CPU.2
VCC: C1.1, J1.18, R1.1, R2.1, R3.1, R4.1, U1.11
WAIT: R1.2, U1.24, USR -> CPU.1

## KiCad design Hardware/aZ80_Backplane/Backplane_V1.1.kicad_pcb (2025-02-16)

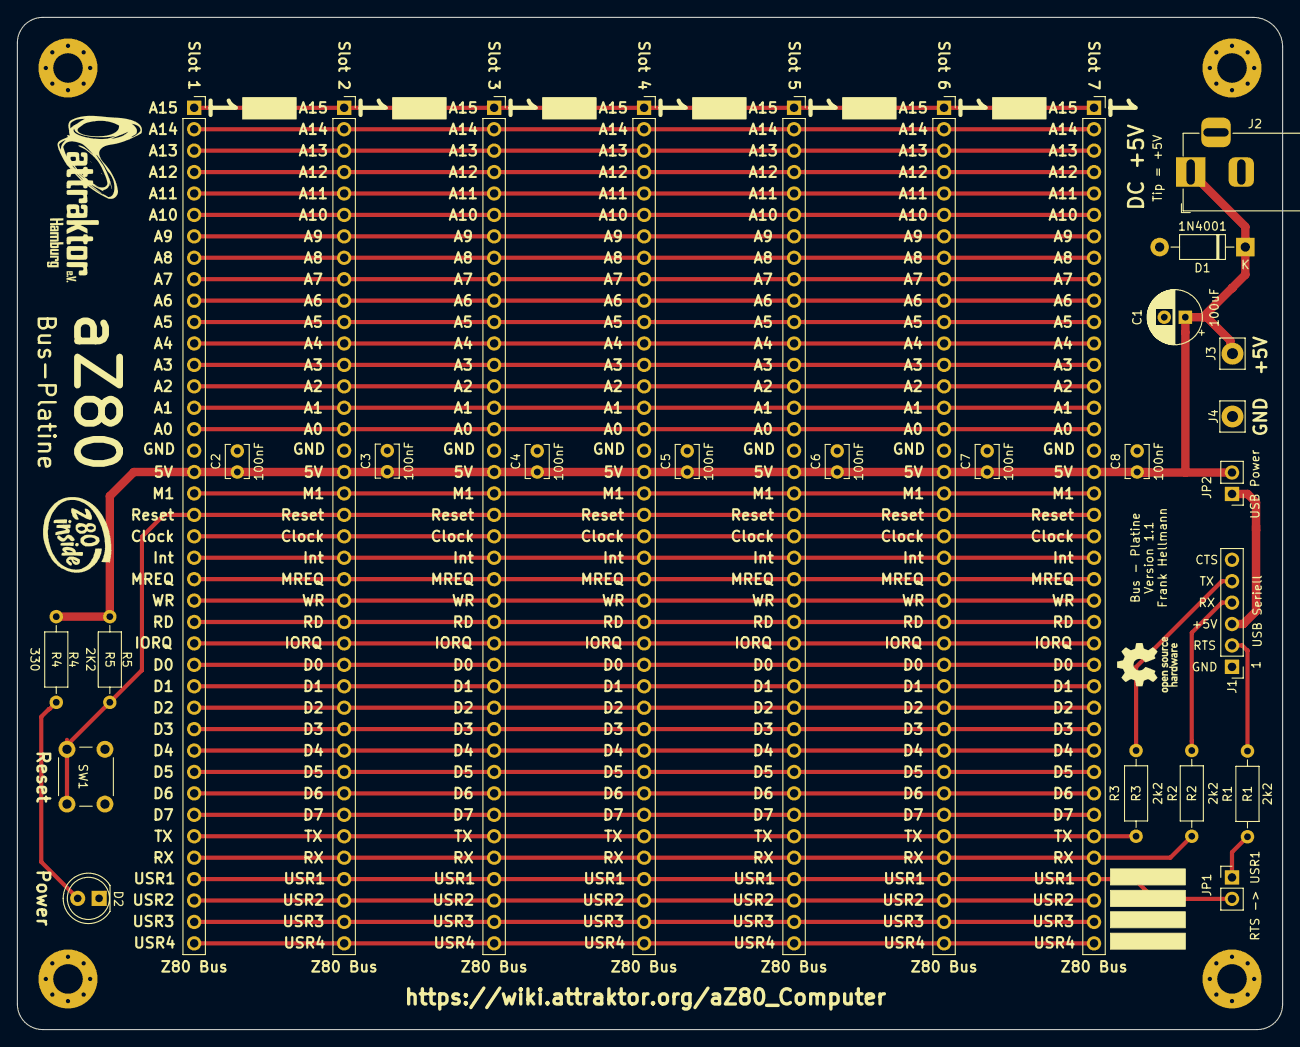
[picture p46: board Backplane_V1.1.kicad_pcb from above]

Board: 2 copper layers, 150.0 x 120.0 mm, 33 parts (0 on the bottom side), 46 nets.

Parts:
C1: 100uF; CP_Radial_D6.3mm_P2.50mm
C2, C3, C4, C5, C6, C7, C8: 100nF; C_Disc_D3.8mm_W2.6mm_P2.50mm
D1: 1N4001; D_DO-41_SOD81_P10.16mm_Horizontal
D2: Power; LED_D5.0mm
Hole1, Hole2, Hole3, Hole4: MountingHole_3.5mm_Pad_Via
J1: USB Seriell; PinHeader_1x06_P2.54mm_Vertical
J2: DC +5V; BarrelJack_Horizontal
J3: +5V Hook; Pin_D1.3mm_L10.0mm_W3.5mm_Flat
J4: GND Hook; Pin_D1.3mm_L10.0mm_W3.5mm_Flat
JP1: RTS -> USR1; PinHeader_1x02_P2.54mm_Vertical
JP2: 5V USB; PinHeader_1x02_P2.54mm_Vertical
R1, R2, R3: 2k2; R_Axial_DIN0207_L6.3mm_D2.5mm_P10.16mm_Horizontal
R4: 330; R_Axial_DIN0207_L6.3mm_D2.5mm_P10.16mm_Horizontal
R5: 2K2; R_Axial_DIN0207_L6.3mm_D2.5mm_P10.16mm_Horizontal
SW1: Reset; SW_PUSH_6mm
Slot 1, Slot 2, Slot 3, Slot 4, Slot 5, Slot 6, Slot 7: Z80 Bus; PinSocket_1x40_P2.54mm_Vertical

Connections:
5V: C1.1, C2.1, C3.1, C4.1, C5.1, C6.1, C7.1, C8.1, D1.1, J2.1, J3.1, JP2.2, R4.1, R5.2, Slot 1.18, Slot 2.18, Slot 3.18, Slot 4.18, Slot 5.18, Slot 6.18, Slot 7.18
/A0: Slot 1.16, Slot 2.16, Slot 3.16, Slot 4.16, Slot 5.16, Slot 6.16, Slot 7.16
/A1: Slot 1.15, Slot 2.15, Slot 3.15, Slot 4.15, Slot 5.15, Slot 6.15, Slot 7.15
/A2: Slot 1.14, Slot 2.14, Slot 3.14, Slot 4.14, Slot 5.14, Slot 6.14, Slot 7.14
/A3: Slot 1.13, Slot 2.13, Slot 3.13, Slot 4.13, Slot 5.13, Slot 6.13, Slot 7.13
/A4: Slot 1.12, Slot 2.12, Slot 3.12, Slot 4.12, Slot 5.12, Slot 6.12, Slot 7.12
/A5: Slot 1.11, Slot 2.11, Slot 3.11, Slot 4.11, Slot 5.11, Slot 6.11, Slot 7.11
/A6: Slot 1.10, Slot 2.10, Slot 3.10, Slot 4.10, Slot 5.10, Slot 6.10, Slot 7.10
/A7: Slot 1.9, Slot 2.9, Slot 3.9, Slot 4.9, Slot 5.9, Slot 6.9, Slot 7.9
/A8: Slot 1.8, Slot 2.8, Slot 3.8, Slot 4.8, Slot 5.8, Slot 6.8, Slot 7.8
/A9: Slot 1.7, Slot 2.7, Slot 3.7, Slot 4.7, Slot 5.7, Slot 6.7, Slot 7.7
/A10: Slot 1.6, Slot 2.6, Slot 3.6, Slot 4.6, Slot 5.6, Slot 6.6, Slot 7.6
/A11: Slot 1.5, Slot 2.5, Slot 3.5, Slot 4.5, Slot 5.5, Slot 6.5, Slot 7.5
/A12: Slot 1.4, Slot 2.4, Slot 3.4, Slot 4.4, Slot 5.4, Slot 6.4, Slot 7.4
/A13: Slot 1.3, Slot 2.3, Slot 3.3, Slot 4.3, Slot 5.3, Slot 6.3, Slot 7.3
/A14: Slot 1.2, Slot 2.2, Slot 3.2, Slot 4.2, Slot 5.2, Slot 6.2, Slot 7.2
/A15: Slot 1.1, Slot 2.1, Slot 3.1, Slot 4.1, Slot 5.1, Slot 6.1, Slot 7.1
/CLK: Slot 1.21, Slot 2.21, Slot 3.21, Slot 4.21, Slot 5.21, Slot 6.21, Slot 7.21
/D0: Slot 1.27, Slot 2.27, Slot 3.27, Slot 4.27, Slot 5.27, Slot 6.27, Slot 7.27
/D1: Slot 1.28, Slot 2.28, Slot 3.28, Slot 4.28, Slot 5.28, Slot 6.28, Slot 7.28
/D2: Slot 1.29, Slot 2.29, Slot 3.29, Slot 4.29, Slot 5.29, Slot 6.29, Slot 7.29
/D3: Slot 1.30, Slot 2.30, Slot 3.30, Slot 4.30, Slot 5.30, Slot 6.30, Slot 7.30
/D4: Slot 1.31, Slot 2.31, Slot 3.31, Slot 4.31, Slot 5.31, Slot 6.31, Slot 7.31
/D5: Slot 1.32, Slot 2.32, Slot 3.32, Slot 4.32, Slot 5.32, Slot 6.32, Slot 7.32
/D6: Slot 1.33, Slot 2.33, Slot 3.33, Slot 4.33, Slot 5.33, Slot 6.33, Slot 7.33
/D7: Slot 1.34, Slot 2.34, Slot 3.34, Slot 4.34, Slot 5.34, Slot 6.34, Slot 7.34
/INT: Slot 1.22, Slot 2.22, Slot 3.22, Slot 4.22, Slot 5.22, Slot 6.22, Slot 7.22
/IORQ: Slot 1.26, Slot 2.26, Slot 3.26, Slot 4.26, Slot 5.26, Slot 6.26, Slot 7.26
/M1: Slot 1.19, Slot 2.19, Slot 3.19, Slot 4.19, Slot 5.19, Slot 6.19, Slot 7.19
/MREQ: Slot 1.23, Slot 2.23, Slot 3.23, Slot 4.23, Slot 5.23, Slot 6.23, Slot 7.23
/RD: Slot 1.25, Slot 2.25, Slot 3.25, Slot 4.25, Slot 5.25, Slot 6.25, Slot 7.25
/WR: Slot 1.24, Slot 2.24, Slot 3.24, Slot 4.24, Slot 5.24, Slot 6.24, Slot 7.24
GND: C1.2, C2.2, C3.2, C4.2, C5.2, C6.2, C7.2, C8.2, D1.2, D2.1, J1.1, J2.2, J4.1, SW1.2, Slot 1.17, Slot 2.17, Slot 3.17, Slot 4.17, Slot 5.17, Slot 6.17, Slot 7.17
unnamed: D2.2, R4.2
unnamed: J1.2, R1.2
unnamed: J1.3, JP2.1
unnamed: J1.4, R2.2
unnamed: J1.5, R3.2
unnamed: JP1.1, R1.1
RX: R2.1, Slot 1.36, Slot 2.36, Slot 3.36, Slot 4.36, Slot 5.36, Slot 6.36, Slot 7.36
Reset: R5.1, SW1.1, Slot 1.20, Slot 2.20, Slot 3.20, Slot 4.20, Slot 5.20, Slot 6.20, Slot 7.20
TX: R3.1, Slot 1.35, Slot 2.35, Slot 3.35, Slot 4.35, Slot 5.35, Slot 6.35, Slot 7.35
USR1: JP1.2, Slot 1.37, Slot 2.37, Slot 3.37, Slot 4.37, Slot 5.37, Slot 6.37, Slot 7.37
USR2: Slot 1.38, Slot 2.38, Slot 3.38, Slot 4.38, Slot 5.38, Slot 6.38, Slot 7.38
USR3: Slot 1.39, Slot 2.39, Slot 3.39, Slot 4.39, Slot 5.39, Slot 6.39, Slot 7.39
USR4: Slot 1.40, Slot 2.40, Slot 3.40, Slot 4.40, Slot 5.40, Slot 6.40, Slot 7.40

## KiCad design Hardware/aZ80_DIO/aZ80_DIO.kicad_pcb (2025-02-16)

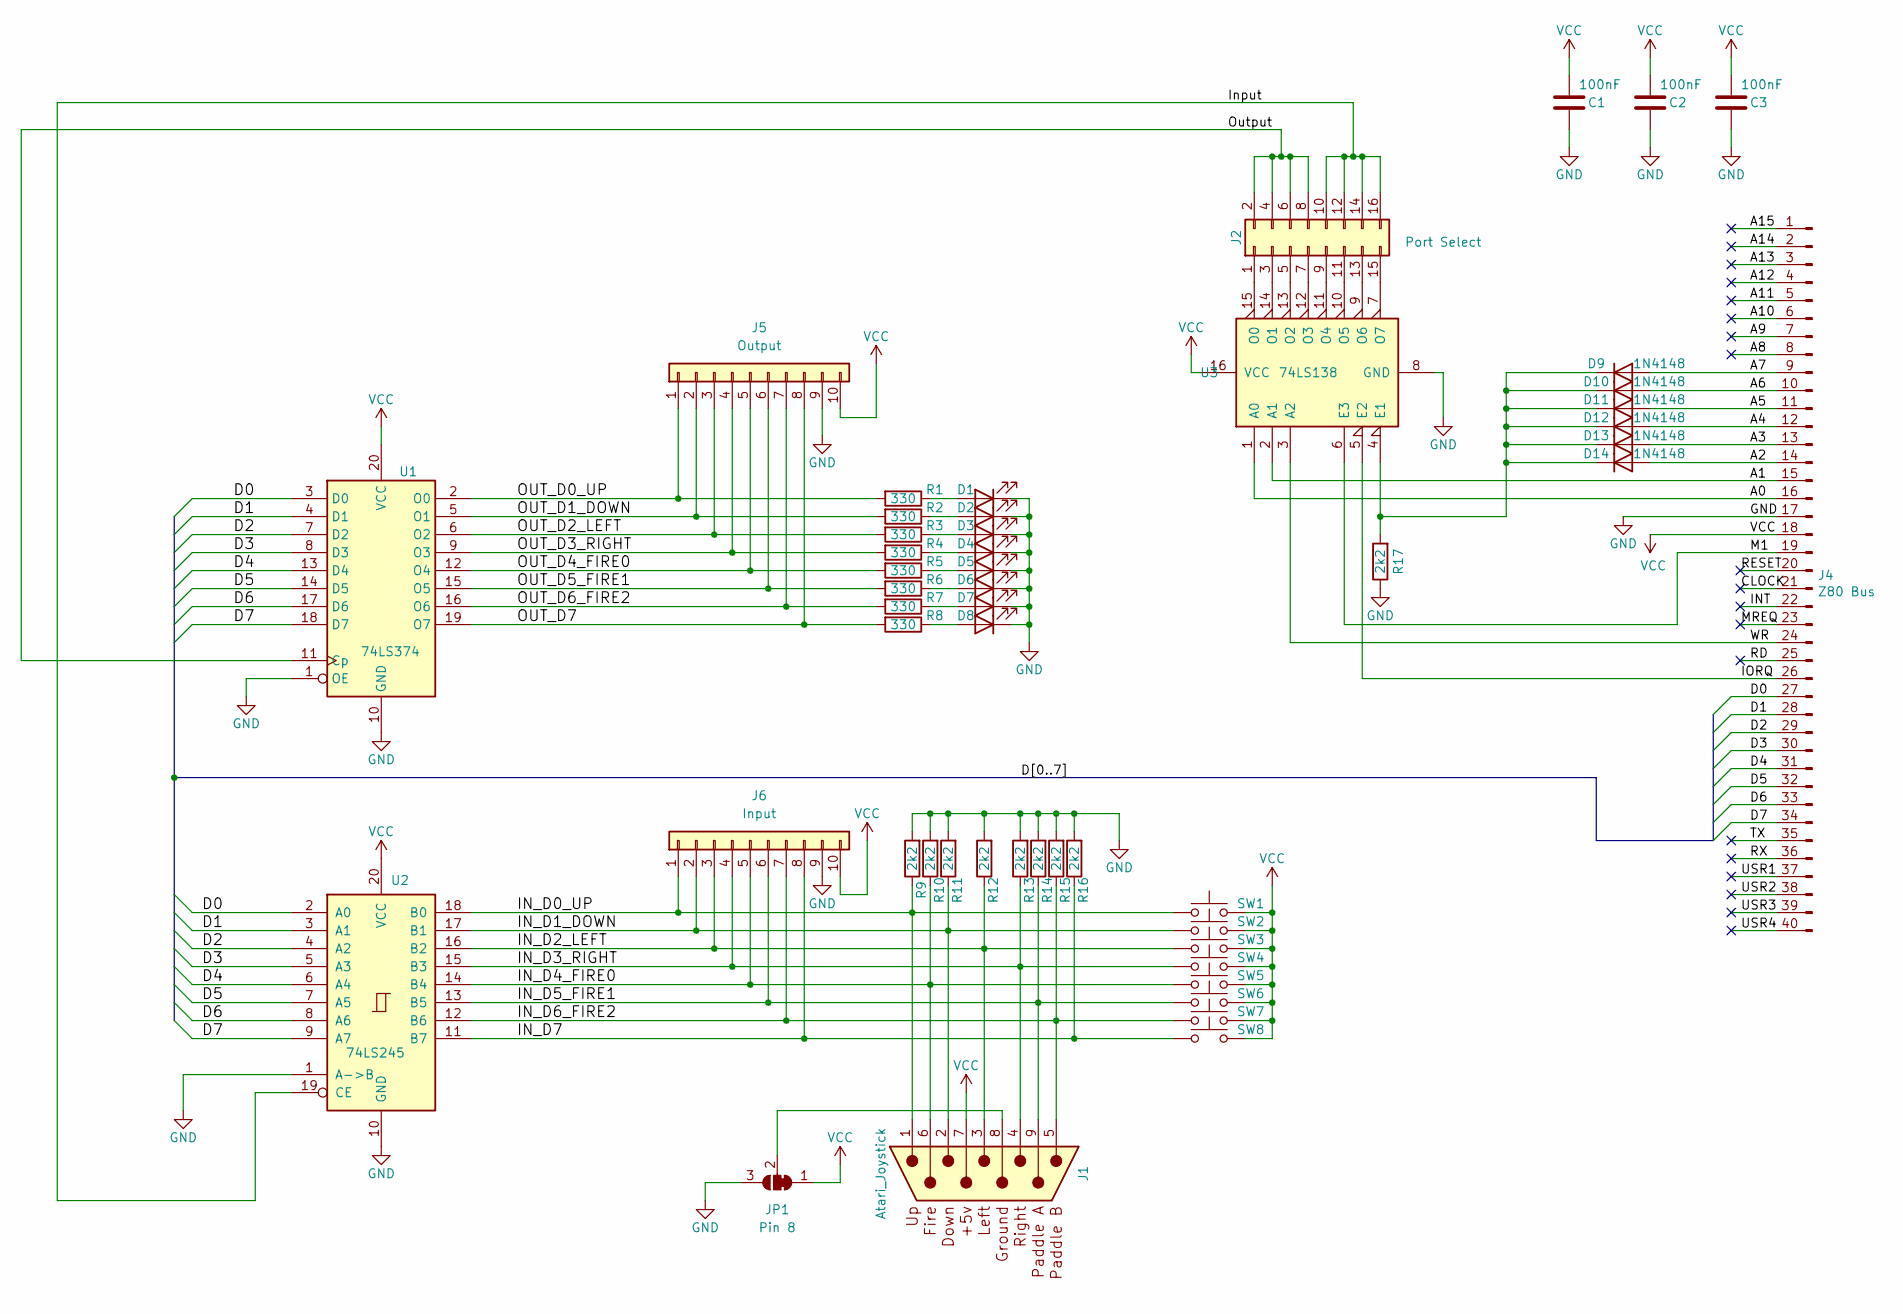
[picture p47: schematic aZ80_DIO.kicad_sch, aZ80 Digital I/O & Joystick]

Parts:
C1, C2, C3: 100nF; C_Disc_D3.8mm_W2.6mm_P2.50mm
D1, D2, D3, D4, D5, D6, D7, D8: LED_Small; LED_D5.0mm
D9, D10, D11, D12, D13, D14: 1N4148; D_DO-35_SOD27_P7.62mm_Horizontal
J1: Atari_Joystick; DSUB-9_Male_Horizontal_P2.77x2.84mm_EdgePinOffset7.70mm_Hou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
J2: Port Select; PinHeader_2x08_P2.54mm_Vertical
J4: Z80 Bus; PinHeader_1x40_P2.54mm_Horizontal
J5: Output; PinHeader_1x10_P2.54mm_Vertical
J6: Input; PinHeader_1x10_P2.54mm_Vertical
JP1: Pin 8; SolderJumper-3_P1.3mm_Bridged2Bar12_RoundedPad1.0x1.5mm
R1, R2, R3, R4, R5, R6, R7, R8: 330; R_Axial_DIN0207_L6.3mm_D2.5mm_P10.16mm_Horizontal
R9, R10, R11, R12, R13, R14, R15, R16, R17: 2k2; R_Axial_DIN0207_L6.3mm_D2.5mm_P10.16mm_Horizontal
SW1, SW2, SW3, SW4, SW5, SW6, SW7, SW8: SW_Push; SW_PUSH_6mm
U1: 74LS374; DIP-20_W7.62mm_LongPads
U2: 74LS245; DIP-20_W7.62mm_LongPads
U3: 74LS138; DIP-16_W7.62mm_LongPads

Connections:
/A0: J4.16, U3.1 (A0)
/A1: J4.15, U3.2 (A1)
/A2: D14.2 (A), J4.14
/A3: D13.2 (A), J4.13
/A4: D12.2 (A), J4.12
/A5: D11.2 (A), J4.11
/A6: D10.2 (A), J4.10
/A7: D9.2 (A), J4.9
/A8: J4.8
/A9: J4.7
/A10: J4.6
/A11: J4.5
/A12: J4.4
/A13: J4.3
/A14: J4.2
/A15: J4.1
/CLOCK: J4.21
/D0: J4.27, U1.3 (D0), U2.2 (A0)
/D1: J4.28, U1.4 (D1), U2.3 (A1)
/D2: J4.29, U1.7 (D2), U2.4 (A2)
/D3: J4.30, U1.8 (D3), U2.5 (A3)
/D4: J4.31, U1.13 (D4), U2.6 (A4)
/D5: J4.32, U1.14 (D5), U2.7 (A5)
/D6: J4.33, U1.17 (D6), U2.8 (A6)
/D7: J4.34, U1.18 (D7), U2.9 (A7)
/INT: J4.22
/IN_D0_UP: J1.1, J6.1, R9.1, SW1.1, U2.18 (B0)
/IN_D1_DOWN: J1.2, J6.2, R11.1, SW2.1, U2.17 (B1)
/IN_D2_LEFT: J1.3, J6.3, R12.1, SW3.1, U2.16 (B2)
/IN_D3_RIGHT: J1.4, J6.4, R13.1, SW4.1, U2.15 (B3)
/IN_D4_FIRE0: J1.6, J6.5, R10.1, SW5.1, U2.14 (B4)
/IN_D5_FIRE1: J1.9, J6.6, R14.1, SW6.1, U2.13 (B5)
/IN_D6_FIRE2: J1.5, J6.7, R15.1, SW7.1, U2.12 (B6)
/IN_D7: J6.8, R16.1, SW8.1, U2.11 (B7)
/IORQ: J4.26, U3.5 (E2)
/Input: J2.10, J2.12, J2.14, J2.16, U2.19 (CE)
/M1: J4.19, U3.6 (E3)
/MREQ: J4.23
/OUT_D0_UP: J5.1, R1.2, U1.2 (O0)
/OUT_D1_DOWN: J5.2, R2.2, U1.5 (O1)
/OUT_D2_LEFT: J5.3, R3.2, U1.6 (O2)
/OUT_D3_RIGHT: J5.4, R4.2, U1.9 (O3)
/OUT_D4_FIRE0: J5.5, R5.2, U1.12 (O4)
/OUT_D5_FIRE1: J5.6, R6.2, U1.15 (O5)
/OUT_D6_FIRE2: J5.7, R7.2, U1.16 (O6)
/OUT_D7: J5.8, R8.2, U1.19 (O7)
/Output: J2.2, J2.4, J2.6, J2.8, U1.11 (Cp)
/RD: J4.25
/RESET: J4.20
/RX: J4.36
/TX: J4.35
/USR1: J4.37
/USR2: J4.38
/USR3: J4.39
/USR4: J4.40
/WR: J4.24, U3.3 (A2)
GND: C1.2, C2.2, C3.2, D1.1 (K), D2.1 (K), D3.1 (K), D4.1 (K), D5.1 (K), D6.1 (K), D7.1 (K), D8.1 (K), J4.17, J5.9, J6.9, JP1.3 (B), R9.2, R10.2, R11.2, R12.2, R13.2, R14.2, R15.2, R16.2, R17.1, U1.1 (OE), U1.10 (GND), U2.1 (A->B), U2.10 (GND), U3.8 (GND)
unnamed: D1.2 (A), R1.1
unnamed: D2.2 (A), R2.1
unnamed: D3.2 (A), R3.1
unnamed: D4.2 (A), R4.1
unnamed: D5.2 (A), R5.1
unnamed: D6.2 (A), R6.1
unnamed: D7.2 (A), R7.1
unnamed: D8.2 (A), R8.1
unnamed: D9.1 (K), D10.1 (K), D11.1 (K), D12.1 (K), D13.1 (K), D14.1 (K), R17.2, U3.4 (E1)
unnamed: J2.1, U3.15 (O0)
unnamed: J2.3, U3.14 (O1)
unnamed: J2.5, U3.13 (O2)
unnamed: J2.7, U3.12 (O3)
unnamed: J2.9, U3.11 (O4)
unnamed: J2.11, U3.10 (O5)
unnamed: J2.13, U3.9 (O6)
unnamed: J2.15, U3.7 (O7)
unnamed: J1.8, JP1.2 (C)
VCC: C1.1, C2.1, C3.1, J1.7, J4.18, J5.10, J6.10, JP1.1 (A), SW1.2, SW2.2, SW3.2, SW4.2, SW5.2, SW6.2, SW7.2, SW8.2, U1.20 (VCC), U2.20 (VCC), U3.16 (VCC)

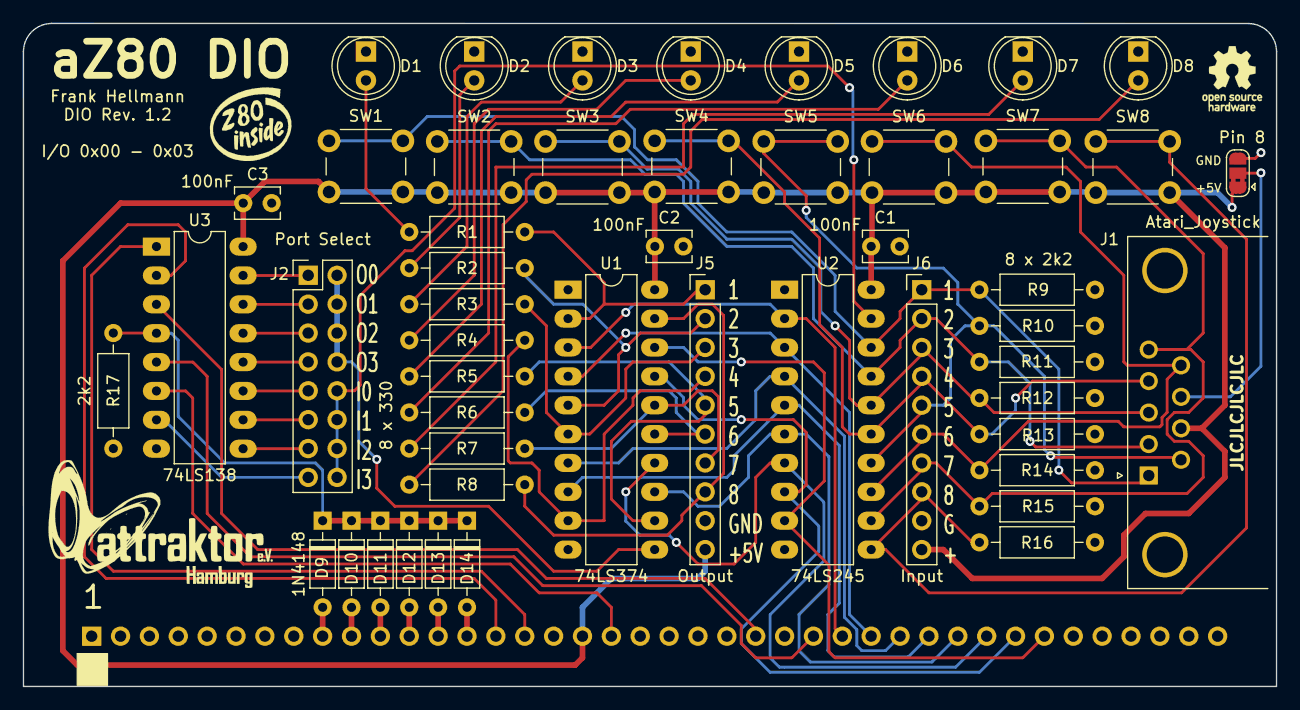
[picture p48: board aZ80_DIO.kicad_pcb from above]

Board: 2 copper layers, 110.3 x 58.3 mm, 51 parts (1 on the bottom side), 57 nets.

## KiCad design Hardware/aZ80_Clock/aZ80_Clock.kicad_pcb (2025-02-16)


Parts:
C1: 100nF; C_Disc_D3.8mm_W2.6mm_P2.50mm
C2, C6: 10uF; CP_Radial_D5.0mm_P2.50mm
C3: 10nF; C_Disc_D3.8mm_W2.6mm_P2.50mm
C4, C5: 22pF; C_Disc_D3.8mm_W2.6mm_P2.50mm
D1: INT; LED_D5.0mm
D2: WR; LED_D5.0mm
D3: RD; LED_D5.0mm
D4: CLK; LED_D5.0mm
J1: Z80 Bus; PinHeader_1x40_P2.54mm_Horizontal
JP1: Takt Auswahl; PinHeader_1x03_P2.54mm_Vertical
R1: 1M; R_Axial_DIN0207_L6.3mm_D2.5mm_P10.16mm_Horizontal
R2, R4: 1k; R_Axial_DIN0207_L6.3mm_D2.5mm_P10.16mm_Horizontal
R3: 3,3k; R_Axial_DIN0207_L6.3mm_D2.5mm_P10.16mm_Horizontal
R5, R6, R7, R8: 330; R_Axial_DIN0207_L6.3mm_D2.5mm_P10.16mm_Horizontal
RV1: 10k; Potentiometer_Piher_PT-10-H01_Horizontal
U1: 74HCT04; DIP-14_W7.62mm_Socket_LongPads
U2: NE555; DIP-8_W7.62mm_Socket_LongPads
Y1: 3,6864MHz; Crystal_HC49-4H_Vertical

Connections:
/A0: J1.16
/A1: J1.15
/A2: J1.14
/A3: J1.13
/A4: J1.12
/A5: J1.11
/A6: J1.10
/A7: J1.9
/A8: J1.8
/A9: J1.7
/A10: J1.6
/A11: J1.5
/A12: J1.4
/A13: J1.3
/A14: J1.2
/A15: J1.1
/CLOCK: J1.21, U1.4
/D0: J1.27
/D1: J1.28
/D2: J1.29
/D3: J1.30
/D4: J1.31
/D5: J1.32
/D6: J1.33
/D7: J1.34
/INT: J1.22, U1.5
/IORQ: J1.26
/M1: J1.19
/RD: J1.25, U1.9
/RESET: C6.1, J1.20
/RX: J1.36
/TX: J1.35
/USR1: J1.37
/USR2: J1.38
/USR3: J1.39
/USR4: J1.40
/WR: J1.24, U1.11
GND: C1.2, C2.2, C3.2, C4.2, C5.2, C6.2, D1.1 (K), D2.1 (K), D3.1 (K), D4.1 (K), J1.17, U1.7 (GND), U2.1 (GND)
unnamed: C2.1, RV1.2, U2.2 (TR), U2.6 (THR)
unnamed: C3.1, U2.5 (CV)
unnamed: C4.1, R1.2, U1.1, Y1.1
unnamed: C5.1, R2.1, Y1.2
unnamed: D1.2 (A), R5.1
unnamed: D2.2 (A), R6.1
unnamed: D3.2 (A), R7.1
unnamed: D4.2 (A), R8.1
unnamed: JP1.1 (A), R1.1, R2.2, U1.2
unnamed: JP1.2 (C), U1.3, U1.13
unnamed: JP1.3 (B), U2.3 (Q)
unnamed: R3.1, R4.2, U2.7 (DIS)
unnamed: R3.2, RV1.1
unnamed: R5.2, U1.6
unnamed: R6.2, U1.10
unnamed: R7.2, U1.8
unnamed: R8.2, U1.12
VCC: C1.1, J1.18, R4.1, U1.14 (VCC), U2.4 (R), U2.8 (VCC)

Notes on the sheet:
CLK High
Takt-Generator (Schnell)
CLK Low
CLOCK
Power On Reset
Quarz mit 3,6864 MHz
Status LEDs
Takt-Generator (Langsam)


Board: 2 copper layers, 110.2 x 33.3 mm, 24 parts (1 on the bottom side), 24 nets.

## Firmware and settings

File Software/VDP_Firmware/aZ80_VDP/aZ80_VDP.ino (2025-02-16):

//
// aZ80 Pi Pico 2 VDP Terminal Emulator
//
// by Frank Hellmann, 2023, 2024, 2025
//
// for use with the attraktor.org aZ80 system 
// compatible with RC2014 systems
//
// includes: 
// - basic Terminal Emulation VT100
// - USB Host support for keyboard and mouse
// - TTL Serial comunication with 57600 baud
// - TTL Serial debug port with 115200 baud
// - Double-buffered 8-bit Adafruit_GFX-compatible framebuffer for PicoDVI
//   Allows animation without redraw flicker. Requires Adafruit_GFX >= 1.11.4
// - Simple Sprite Engine via serial ANSI ESC commands (see ansi_esc tab)
// - Simple Graphics Commands via serial ANSI ESC commands (see ansi_esc tab)
//

// Theory of operation:
// We have two modes to operate in: 
// mode 0: 320x240 Pixels with Terminal & Sprites enabled (Default)
// mode 1: 320x240 Pixels with GFX buffer & Sprites enabled
// mode 2: 320x240 Pixels with GFX buffer & Terminal & Sprites enabled
//
// In display.ino the layering of the buffers on top of each other is set to:
// - GFX buffer is background/last layer if enabled
// - Text buffer if enabled
// - Sprites
// - Status Display on top if enabled
// - Mouse Cursor


// Support for RP2040 has been DROPPED due to lack of memory for GFX buffer!
// !!Needed Arduino Options RP2040:
// !!- Install Raspberry Pi Pico Boards, Adafruit_PicoDVI and Pi Pico USB with dependencies. Then:
// !!- Tools -> Board -> Raspberry Pi Pico     (Raspberry Pi Pico W currently does not work)
// !!- Tools -> Flash size -> 2MB (no FS)
// !!- Tools -> Optimize -> Optimize even more (-O3)  to fix red lines apearing
// !!- Tools -> USB Stack -> Adafruit TinyUSB  (We need a fix here -> see usbhost.ino)
//

// Needed Arduino Options RP2350:
// - Install Raspberry Pi Pico 2 Boards, Adafruit_PicoDVI and Pi Pico USB with dependencies. Then:
// - Tools -> Board -> Raspberry Pi Pico 2   (Raspberry Pi Pico 2W currently does not work)
// - Tools -> CPU Speed -> 250MHz (To solve serial baudrate miscalculation)
// - Tools -> Flash size -> 1MB (3MB FS)
// - Tools -> Optimize -> Optimize even more (-O3)  to fix red lines apearing
// - Tools -> USB Stack -> Adafruit TinyUSB Host (native)
//

/* Pin Assignments
 * 
 *                                      _____|----|_____
 *                     aZ80 RX   GP0 - |      USB       | - VBUS
 *                     aZ80 TX   GP1 - |                | - VSYS     5V
 *                               GND - | * LED/GP25     | - GND
 *                   --    DB0   GP2 - |                | - 3V3_EN
 *                   |     DB1   GP3 - |                | - 3V3 OUT
 *                   |     DB2   GP4 - |                | - ADC_VREF
 *                   |     DB3   GP5 - |                | - GP28     AD2
 *                   |           GND - |                | - GND
 *          aZ80 Bus |     DB4   GP6 - |   Raspberry    | - GP27     AD1
 *                   |     DB5   GP7 - |       Pi       | - GP26     AD0   
 *                   |     DB6   GP8 - |     Pico 2     | - RUN      Reset Button
 *                   |     DB7   GP9 - |                | - GP22     Beeper O/P
 *                   |           GND - |                | - GND
 *                   |     RW   GP10 - |                | - GP21     RX2 Debug
 *                   --    CS   GP11 - |                | - GP20     TX2 Debug
 *                     DVI D0+  GP12 - |                | - GP19     DVI D1-
 *                     DVI D0-  GP13 - |                | - GP18     DVI D1+
 *                               GND - |                | - GND
 *                    DVI CLK+  GP14 - |                | - GP17     DVI D2-
 *                    DVI CLK-  GP15 - |___--__--__--___| - GP16     DVI D2+
 *                             SWCLK ______/  GND   \______ SWDIO
 */

// Todo ( - planned, + done ):
// + Serial Terminal Emu     aZ80 -> VDP darstellen
// + Keyboard Emu            VPD  -> aZ80 Tasten senden
// + ANSI Emu
//   + Mouse Cursor on/off, Position R/W
//   + Text Cursor on/off, Position R/W
//   + Palette
//   + Set palette entry with RGB values
//   - Smooth scrolling, extended Fontbuffer
//   - Upload Font Bitmaps
//   - Upload Mouse Pointer Bitmaps
// + Sprites
//   + draw sprites layer
//   + Set position, velocity
//   - Upload Sprite Bitmaps
//   - Report Collisions
// + GFX Layer Commands
//   + implement basic GFX commands
//   + draw GFX layer
//   - Smooth scrolling
//   - Blitter operations
//

// Do we want debugging over Serial Port 2 ?
// uncomment #define if we do
// (be aware that this can impact performace and framerate visibly)
//#define DEBUG

#ifdef DEBUG
 #define DEBUG_PRINT(...) Serial2.printf(__VA_ARGS__)
#else
 #define DEBUG_PRINT(...)
#endif

// Default Serial Speeds
#define SER1_SPEED  57600
#define SER2_SPEED 115200

// SdFat 2.2.1 or later Adafruit Fork is needed
// SdFat is required for using Adafruit_USBH_MSC_SdFatDevice
// (might clash with ESP8266_SdFat Library from Pi Pico Board due to same naming)
#include "SdFatConfig.h"
#include "SdFat.h"

// TinyUSB lib
#include "Adafruit_TinyUSB.h"

// USB Host object
Adafruit_USBH_Host USBHost;
// USB Host MSC Block Device object which implemented API for use with SdFat
Adafruit_USBH_MSC_BlockDevice msc_block_dev;

// DVI object
#include <PicoDVI.h>
DVIGFX8 display(DVI_RES_320x240p60, true, pico_sock_cfg);
#define DISPLAYSX 320
#define DISPLAYSY 240

// Default Runtime Configuration
static bool is_keyboard_mounted = false;
static bool is_mouse_mounted = false;
static bool is_joystick_mounted = false;
static bool is_filesystem_mounted = false;

// Check for WiFi capabilities ( not used so far )
static bool is_wifi_capable = rp2040.isPicoW();

// Textbuffer ( 8x8 font -> 40x30 characters = 4,8kB)
#define TEXTSX 40
#define TEXTSY 30 
#define TEXTBUFSZ 40*30
static uint8_t text_buf[TEXTBUFSZ];
static uint8_t text_fg[TEXTBUFSZ];
static uint8_t text_bg[TEXTBUFSZ];
static uint8_t text_attr[TEXTBUFSZ];
#define TEXTATTR_OFF      0
#define TEXTATTR_BLINK    1
#define TEXTATTR_REVERSE  2

// Display
static uint8_t  screen_mode     = 2;
static uint8_t  screen_bg_color = 0;
static uint8_t  fg_color        = 7;
static uint8_t  bg_color        = 0;
static uint8_t  current_attr    = 0;
static uint8_t  cycle_speed     = 3;
static uint8_t  cycle_count     = 0;
static uint16_t sprite_gui      = 0;
static bool     status_gui_on   = false;
static uint64_t cpu_ticks       = 0;

// Cursor
static unsigned int  cursor_mode = 0;
static unsigned int  cursorx = 0;
static unsigned int  cursory = 0;
static unsigned int  saved_cursorx = 0;
static unsigned int  saved_cursory = 0;

// Mouse
static unsigned int  mouse_pointer = 0;
static unsigned int  mousebuttons  = 0;
static unsigned int  mousex = 0;
static unsigned int  mousey = 0;

// Beeper
#define BEEPER_PIN 22
#define BEEPER_LOOPS 3
bool beeper_on = false;
int  beeper_timer = 0;

// GFX (64kB)
// allocate one buffer for graphics 320x240
GFXcanvas8       gfx_buffer(DISPLAYSX, DISPLAYSY);
static uint16_t  gfx_curx = 0;
static uint16_t  gfx_cury = 0;
static uint8_t   gfx_fgcol = fg_color;
static uint8_t   gfx_bgcol = bg_color;

// Sprites  ( 32kB )
#define MAX_SPRITE_NUM 63
struct SpriteData {
  int16_t   xpos;
  int16_t   ypos;
  int8_t    xvel;
  int8_t    yvel;
  uint8_t   xsize;
  uint8_t   ysize;
  bool      enabled;
  uint8_t   data[576];
  uint8_t   mask[72];
};
static SpriteData Sprite[MAX_SPRITE_NUM];

/* 
 *  Setup & Loop
*/
void setup() {
  // Setup Status LED on Pi Pico
  pinMode(LED_BUILTIN, OUTPUT);
  digitalWrite(LED_BUILTIN,1);   

  // setup UART
  serial_setup();
  
  // start USB Host
  usbhost_setup();

  // setup Beeper Signal
  beeper_setup();

  // setup GFX
  gfx_setup();

  // setup Sprites
  sprite_setup();

  // setup Ansi Decoder
  ansi_setup();

  // setup DVI Display
  display_setup();
}

// Core0: loops our stuff
// Core1: is used for generating the DVI Signal
void loop() {
  // update stuff
  serial_update();
  usbhost_update();
  beeper_update();
  sprite_update();
  display_update();

  // blink LED
  digitalWrite(LED_BUILTIN, (millis() / 500) & 1);    
}

//
// TinyUSB callbacks need to be in main .ino and get routed to usbhost.ino
//
// Invoked when device with hid interface is mounted
void tuh_hid_mount_cb(uint8_t dev_addr, uint8_t instance, uint8_t const *desc_report, uint16_t desc_len) {
  usbhost_hid_mount(dev_addr, instance, desc_report, desc_len);
}

// Invoked when device with hid interface is un-mounted
void tuh_hid_umount_cb(uint8_t dev_addr, uint8_t instance) {
  usbhost_hid_umount(dev_addr, instance);
}

// Invoked when received report from device via interrupt endpoint
void tuh_hid_report_received_cb(uint8_t dev_addr, uint8_t instance, uint8_t const *report, uint16_t len) {
  usbhost_hid_report_received(dev_addr, instance, report, len);
}

// Invoked when a device with MassStorage interface is mounted
void tuh_msc_mount_cb(uint8_t dev_addr)
{
  usbhost_msc_mount_cb(dev_addr);
}

// Invoked when a device with MassStorage interface is unmounted
void tuh_msc_umount_cb(uint8_t dev_addr)
{
  usbhost_msc_umount_cb(dev_addr);
}

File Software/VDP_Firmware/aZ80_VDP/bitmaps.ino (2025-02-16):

//
//
// This holds the inital palette, icons, sprites, logos and fonts
//
#include <Adafruit_GFX.h>    // Core graphics library

//=================== Palette ========================

// 256 Color Palette - each color in 16-bit RGB565 format
const uint16_t __in_flash() BM_Palette[] = {
  0x0000,0xf800,0x07e0,0xffe0,0x001f,0xf81f,0x07ff,0xffff,0x0000,0xf800,0x07e0,0xffe0,
  0x001f,0xf81f,0x07ff,0xffff,0xffff,0xef7d,0xdefb,0xce79,0xbdf7,0xad75,0x9cf3,0x8c71,
  0x7bef,0x6b6d,0x5aeb,0x4a69,0x4228,0x31a6,0x2124,0x10a2,0x0020,0xbd31,0xb511,0xacd0,
  0xa48f,0x9c4e,0x940d,0x8bcc,0x838b,0x7b4a,0x7309,0x6ac8,0x6287,0x5a46,0x5205,0x49e4,
  0x4183,0xbbc9,0xb388,0xab68,0xa347,0x9b07,0x8ae6,0x82a6,0x7a85,0x7265,0x6a24,0x5a04,
  0x51e3,0x49a3,0x3962,0x3142,0x2901,0xff5b,0xff1a,0xfed8,0xfe97,0xfe76,0xfe34,0xfdf3,
  0xfdd2,0xfd90,0xf54f,0xed0e,0xe4cd,0xdc8c,0xd44b,0xcc0a,0xcbe9,0xff7b,0xfef7,0xfe52,
  0xfdce,0xfd4a,0xfca6,0xfc23,0xfba0,0xf360,0xe320,0xdae0,0xcaa0,0xba60,0xb220,0xa1e0,
  0x91a0,0xfffd,0xfff9,0xfff5,0xfff1,0xffed,0xffe9,0xffe5,0xffe1,0xffe0,0xce60,0xad60,
  0x8c60,0x6b60,0x4a60,0x2960,0x0860,0xffee,0xeeca,0xd5c8,0xc4c5,0xabc3,0x9ac2,0x8200,
  0x7140,0xfefb,0xfdf7,0xfcf3,0xfbef,0xfaeb,0xf9e7,0xf8e3,0xf800,0xe800,0xd800,0xc800,
  0xb800,0xa800,0x9800,0x8800,0x7800,0x6800,0x5800,0x4800,0x3800,0x2800,0x1800,0x0800,
  0xfdb6,0xf514,0xe471,0xdbcf,0xcb4d,0xbacb,0xb269,0xa1e7,0x8960,0x8120,0x7900,0x70c0,
  0x6880,0x6040,0x5820,0x5000,0x77e9,0x7789,0x6f08,0x6688,0x5e07,0x5586,0x4d06,0x4485,
  0x3c05,0x3384,0x2b03,0x2283,0x1a02,0x1181,0x0901,0x0060,0xdff5,0xc732,0xae50,0x956d,
  0x7c8b,0x63a8,0x4ac6,0x31e3,0x07e0,0x06e0,0x05e0,0x04e0,0x03e0,0x02e0,0x01e0,0x00e0,
  0xfb7f,0xf81f,0xd81b,0xb817,0x9813,0x780f,0x580b,0x3807,0xef5e,0xc63c,0x9cf9,0x73b7,
  0x52b4,0x4210,0x296b,0x18c6,0xd79f,0xbf5f,0xaf1f,0x96ff,0x86bf,0x6e7f,0x565f,0x3dff,
  0x34fb,0x2c77,0x23b3,0x1aef,0x05f7,0x03ef,0x02eb,0x01e7,0xe73f,0xc63f,0xad7f,0x8c7f,
  0x739f,0x529f,0x319f,0x18df,0x001f,0x001c,0x0019,0x0016,0x0013,0x0010,0x000d,0x000a,
  0x0009,0x0007,0x0006,0x0004,0x0003,0x0001,0x0000,0x07ff,0xcbf9,0xb376,0x9af3,0x8270,
  0x69ed,0x516a,0x38e7,0x2064
};


//=================== Icons ==========================

// Icons for Status GUI
const uint8_t BM_Disk[] = {
  0x7c, 0xbe, 0xbd, 0x81, 0x81, 0xbd, 0xa5, 0x7e
};
const uint8_t BM_Keyboard[] = {
  0x00, 0xab, 0x00, 0xd5, 0x01, 0xab, 0x00, 0xeb
};
const uint8_t BM_Mouse[] = {
  0x04, 0x3e, 0x49, 0x7f, 0x41, 0x41, 0x22, 0x1c
};
const uint8_t BM_Joystick[] = {
  0x00, 0x08, 0x14, 0x14, 0x08, 0x08, 0x3e, 0x7f
};
const uint8_t BM_Wifi[] = {
  0x00, 0x78, 0x04, 0x72, 0x09, 0x65, 0x15, 0x55
};


//================== Sprites =========================

// The sprites are max. 24x24 pixels, and are stored one byte per pixel
// representing the color index from the 256 color palette and a one
// bit per pixel mask:  -> 648 bytes data+mask * 48 sprites total -> 32kB
// 8-bit image with a 1-bit mask (set bits = opaque, unset bits = clear) 

// Sprite 16x16
const uint8_t __in_flash() BM_Logo[] = {
  0x00, 0x00, 0x00, 0x00, 0x00, 0x00, 0x00, 0x00, 0x00, 0x00, 0x00, 0x00, 0x00, 0x00, 0x00, 0x00,
  0x00, 0x00, 0x00, 0xd8, 0x00, 0x00, 0x00, 0x00, 0x00, 0x00, 0x00, 0x00, 0xd8, 0x00, 0x00, 0x00,
  0x00, 0x00, 0x00, 0x00, 0xd9, 0x00, 0x00, 0x00, 0x00, 0x00, 0x00, 0xd9, 0x00, 0x00, 0x00, 0x00,
  0x00, 0x00, 0xda, 0xda, 0xda, 0xda, 0xda, 0x00, 0x00, 0xda, 0xda, 0xda, 0xda, 0xda, 0x00, 0x00,
  0x00, 0xdb, 0xdb, 0xdb, 0xdb, 0xdb, 0xdb, 0xdb, 0xdb, 0xdb, 0xdb, 0xdb, 0xdb, 0xdb, 0xdb, 0x00,
  0xdc, 0xdc, 0xdc, 0x00, 0xdc, 0x00, 0xdc, 0xdc, 0xdc, 0xdc, 0x00, 0xdc, 0x00, 0xdc, 0xdc, 0xdc,
  0xde, 0xde, 0x00, 0x00, 0x00, 0x00, 0x00, 0xde, 0xde, 0x00, 0x00, 0x00, 0x00, 0x00, 0xde, 0xde,
  0xdf, 0xdf, 0xdf, 0x00, 0x00, 0x00, 0xdf, 0xdf, 0xdf, 0xdf, 0x00, 0x00, 0x00, 0xdf, 0xdf, 0xdf,
  0xde, 0xde, 0xde, 0xde, 0xde, 0xde, 0xde, 0xde, 0xde, 0xde, 0xde, 0xde, 0xde, 0xde, 0xde, 0xde,
  0xdd, 0xdd, 0xdd, 0x00, 0x00, 0x00, 0xdd, 0xdd, 0xdd, 0xdd, 0x00, 0x00, 0x00, 0xdd, 0xdd, 0xdd,
  0xd0, 0xd0, 0x00, 0x00, 0x00, 0x00, 0x00, 0xd0, 0xd0, 0x00, 0x00, 0x00, 0x00, 0x00, 0xd0, 0xd0,
  0xc0, 0xc0, 0x00, 0x00, 0x00, 0x00, 0xc0, 0x00, 0x00, 0xc0, 0x00, 0x00, 0x00, 0x00, 0xc0, 0xc0,
  0x00, 0xda, 0xda, 0x00, 0x00, 0x00, 0xda, 0x00, 0x00, 0xda, 0x00, 0x00, 0x00, 0xda, 0xda, 0x00,
  0x00, 0x00, 0xd9, 0xd9, 0x00, 0x00, 0x00, 0x00, 0x00, 0x00, 0x00, 0x00, 0xd9, 0xd9, 0x00, 0x00,
  0x00, 0x00, 0x00, 0xd8, 0xd8, 0x00, 0x00, 0x00, 0x00, 0x00, 0x00, 0xd8, 0xd8, 0x00, 0x00, 0x00,   
  0x00, 0x00, 0x00, 0x00, 0x00, 0x00, 0x00, 0x00, 0x00, 0x00, 0x00, 0x00, 0x00, 0x00, 0x00, 0x00   
};

const uint8_t __in_flash() BM_Logo_mask[] = {
  0b00000000, 0b00000000,
  0b00010000, 0b00001000,
  0b00001000, 0b00010000,
  0b00111110, 0b01111100,
  0b01111111, 0b11111110,
  0b11111111, 0b11111111,
  0b11111111, 0b11111111,
  0b11111111, 0b11111111,
  0b11111111, 0b11111111,
  0b11111111, 0b11111111,
  0b11111111, 0b11111111,
  0b11111111, 0b11111111,
  0b01110011, 0b11001110,
  0b00110000, 0b00001100,
  0b00011000, 0b00011000,
  0b00000000, 0b00000000
};

//==================== Fonts =========================
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
